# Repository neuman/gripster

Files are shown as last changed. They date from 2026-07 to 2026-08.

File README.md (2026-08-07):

# Gripster

**A wireless split thumb keyboard that turns your phone into a handheld deck.** Your phone clamps
landscape in the middle on a spring-loaded expanding bridge (Kishi/Backbone style, fits 130–170 mm
phones); two grips flank it and you thumb-type a real 78-key QWERTY on metal snap domes over Bluetooth.

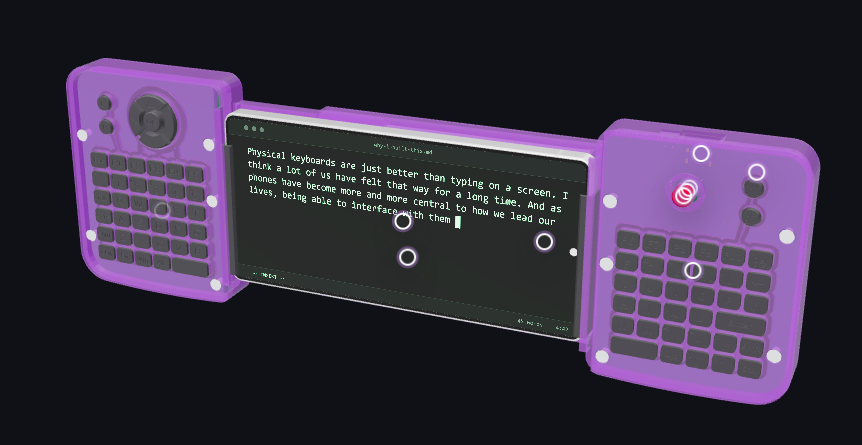
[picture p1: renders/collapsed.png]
Gripster — 3/4 view of the assembled deck: translucent Atomic-Purple shells, dark-gray keymats, a phone clamped landscape in the middle (https://neuman.github.io/gripster/)


<sub>☝️ **This image is a link — click it to spin the real assembly in 3D, pull it apart with the explode slider, and read the build story.**</sub>








> **Naming, once, so nothing is confusing later:** the project is called **Gripster** in prose. Every
> *internal* identifier — the ZMK board id `thumbdeck`, the board files `thumbdeck_right.kicad_pcb` /
> `thumbdeck_left.kicad_pcb`, the firmware artifact `thumbdeck-zmk.uf2`, the footprint library
> `thumbdeck.pretty/`, and the Bluetooth device name your phone will actually show — is
> **`thumbdeck`**. Those are real strings in real files and they stay as they are.

**What makes this interesting:**

- **It fits your phone, not one phone.** The grips ride a **2-part telescoping tray** (v0.24,
  Abxylute/8BitDo-style): stretch it open, drop the phone in, and two springs clamp it by the short
  edges — ~130 to ~170 mm long, and it collapses flat for a pocket. The phone is held **mechanically** —
  trapped between the tray and **soft TPU grippers with deep capture lips** — so it stays put even
  screen-down over your face like a Switch. **No magnets at all** — v0.25 dropped the secondary MagSafe
  ring: with the spring clamp, the toothed TPU grippers and the deep capture lips all doing their job it
  earned nothing, and its recess was the last thing wanting space in the moving jaw's travel.
- **The back is one flat plane.** v0.25 removed the v0.23 faceted crown and dropped both grips' backs
  to the tray floor, so the grips and the centre tray are coplanar — the device sits flat instead of
  rocking on its tray, and the back halves print straight on the bed with no supports. Every outside
  edge the hands wrap gets a 1.2 mm quarter-round.
- **No switches, no hand-soldering.** 78 Snaptron 7 mm metal snap domes press directly onto gold
  ENIG pads. Every soldered part is SMT on one side of each board — v0.21's pointing nub is a
  single SOT-23-6 hall sensor on the same reflow pass — so JLCPCB builds it 100 % turnkey,
  zero soldering by you.
- **It's not a split.** One certified nRF52840 module in the right grip scans a single 9×10 matrix;
  the left grip carries no active parts, joined by one **20-way** FFC ribbon that carries the matrix
  **and** the cell (v0.27 — the separate battery cable is deleted, so exactly one thing crosses the
  spine). One BLE device, no half-to-half pairing, one battery, one firmware image.
- **The whole product is generated from one Python file.**
  [`hardware/scripts/deck.py`](hardware/scripts/deck.py) emits the KiCad boards, the CadQuery
  shells, the renders *and* the ZMK keymap — so key openings land on dome pads by construction, not
  by luck.
- **The boards are real and finished.** Both PCBs are fully autorouted and DRC-clean in KiCad 9
  (0 violations, 0 unconnected), with the JLCPCB gerber + BOM + CPL package exporting cleanly.

> ### ⚠️ Honest status: designed, not built
>
> **No physical Gripster has ever existed.** Every image *of this device* is a render or a generated
> layout — the only photographs in the repo are of the Rii i8+ that was studied as a reference
> ([`references/`](references/)), alongside the original hand drawings in [`sketches/`](sketches/).
> rev-A (v0.27) is complete on paper: both boards routed and DRC-clean, the fab package
> exports cleanly, all 10 printed parts watertight and bed-fit-checked for an Ender 3 V2. (CI is
> stale — re-run it; the last green build predates the nub module.) Nothing has been ordered, printed, pressed, flashed or typed on.
>
> **Unmeasured and unknown:** ergonomics, dome feel and dome life, BLE range with a phone
> centimetres away and a hand around the antenna, real battery life, and every print tolerance.
> "0 DRC violations" means *no rule was broken*, not *the circuit is correct*.
>
> If you build one, **you are building the first one**. Read
> [Project status & roadmap](#project-status--roadmap) before you spend money.

---

## Table of contents

- [What is this?](#what-is-this)
- [Where to start](#where-to-start)
  - [What's in the repo](#whats-in-the-repo)
  - [Which doc answers which question](#which-doc-answers-which-question)
- [Project status & roadmap](#project-status--roadmap)
  - [Done](#done) · [Not done](#not-done--read-this-before-spending-money) · [Roadmap](#roadmap) · [Open design calls](#open-design-calls) · [Version history](#version-history)
- [FAQ](#faq)
- [Hardware](#hardware)
  - [At a glance](#at-a-glance)
  - [Why a module, not chip-down](#why-a-module-not-chip-down)
  - [Per-grip layout](#per-grip-layout)
  - [The boards, as routed](#the-boards-as-routed)
  - [The 3D model — printable shells + keymats](#the-3d-model--printable-shells--keymats)
  - [Parts list (BOM)](#parts-list-bom)
- [Firmware & software](#firmware--software)
  - [How it works — matrix, GPIO, power, antenna](#how-it-works--matrix-gpio-power-antenna)
  - [Building the firmware](#building-the-firmware)
- [Build guide](#build-guide)
- [Design & generation (the parametric model)](#design--generation-the-parametric-model)
  - [Fabrication view + real KiCad boards](#fabrication-view--real-kicad-boards)
  - [Reproduce the design](#reproduce-the-design)
- [Contributing](#contributing)
- [License](#license)

---

## What is this?

Phones are the most capable computer most people carry and the worst thing to type on. Gripster is a
handheld shell that fixes the input half without replacing the phone: your phone stays the screen
and the compute, and the deck around it becomes the keyboard.

The phone mounts **landscape in the centre**, clamped by two springs against toothed TPU grippers, and it
sits **down inside a well** — deep enough that the glass and the keyboard face form a single flat
plane 14.7 mm off the back. Two contoured grips flank it. You hold it like a game controller and
thumb-type a full split QWERTY: 78 keys on **metal snap domes**, the same clicky stainless discs used
in TV remotes and the [Rii i8+](references/rii8_ref.png), pressed straight onto gold pads on the PCB.
There is no switch, no stem, no solder — the dome *is* the switch. The whole thing takes its design
language from a Game Boy Color: boxy rounded outline, translucent Atomic-Purple shell, dark-gray
keymats. The original concept drawings are in [`sketches/`](sketches/).

Despite the two halves, **this is not a split keyboard**. One certified nRF52840 module lives in the
right grip and scans everything; the left grip holds no active silicon at all — domes, diodes, the
bridge connector, and (v0.27) the cell's plug and its fuse.

```
  LEFT grip (passive)                        RIGHT grip (MCU)
  42 domes + diodes  ── 20-way FFC jumper ──  Ebyte E73 (nRF52840)  ⇄ phone (BLE HID)
  D-pad/OK, mouse       straight type-A       + charger + USB-C + power switch
  LiPo + J4 + F1 PTC    14 matrix + VBAT      scans the whole 9×10 matrix
  (no chip)             + GND, one cable      charges over the same ribbon
```

That means one Bluetooth device to pair, no half-to-half link to drop, one battery to charge, and one
firmware image. The cost is a ribbon cable running through the spine under the phone well — since
**v0.27** that ribbon is 20-way and carries the raw cell alongside the matrix, so it is the *only*
thing crossing, and it is fused at the cell end (**F1**, a 0.75 A PPTC on the left board).

Everything you can see in this repo — the KiCad boards, the printable shells, the renders above, even
the ZMK keymap — is generated from a single parametric Python model,
[`hardware/scripts/deck.py`](hardware/scripts/deck.py). Move a key in the model and the board pad,
the shell opening, the keycap and the firmware matrix transform all move with it.

---

## Where to start

**Just browsing?** Open [the live site](https://neuman.github.io/gripster/) — spin the
model, drag the explode slider, tap the hotspots — then skim [At a glance](#at-a-glance) and the
[FAQ](#faq).

**Thinking about building one?** Read [Project status & roadmap](#project-status--roadmap) first — it
will either talk you out of it or tell you exactly what you are signing up for — then
[`docs/assembly.md`](docs/assembly.md) and
[`docs/fabrication-sourcing.md`](docs/fabrication-sourcing.md).

**Here for the engineering?** [Fabrication view + real KiCad boards](#fabrication-view--real-kicad-boards),
[`docs/routing-status.md`](docs/routing-status.md) and
[`docs/design-decisions.md`](docs/design-decisions.md).

### What's in the repo

| Directory | What's in it |
|---|---|
| [`hardware/scripts/`](hardware/scripts/) | **The source of truth.** [`deck.py`](hardware/scripts/deck.py) is the parametric model; the rest generate boards, fab output, firmware, simulations and 2D renders from it. Old 50-key experiments are archived in [`legacy/`](hardware/scripts/legacy/). |
| [`hardware/kicad/`](hardware/kicad/) | The generated KiCad 9 boards. Nothing here is hand-drawn — see its [README](hardware/kicad/README.md). The JLCPCB fab package builds into `generated/fab/` (a local build artifact, not committed). |
| [`hardware/cad/`](hardware/cad/) | CadQuery 3D: [`deck3d.py`](hardware/cad/deck3d.py) builds the shells and keymats, [`export_full_asm.py`](hardware/cad/export_full_asm.py) builds the nested GLB. Watertight STLs live in [`models/`](hardware/cad/models/). |
| [`hardware/footprints/`](hardware/footprints/) | Custom KiCad footprints, including the [snap-dome contact pad](hardware/footprints/snaptron_7mm_contact_pad.kicad_mod). Some are vendored third-party — see [License](#license). |
| [`hardware/layout/`](hardware/layout/) | [`keymat.json`](hardware/layout/keymat.json), the original sketch digitization. Historical only; the live layout is the `LEGENDS` tables in `deck.py`. |
| [`firmware/zmk-config/`](firmware/zmk-config/) | ZMK v0.3.0 config with a real board definition ([`config/boards/arm/thumbdeck/`](firmware/zmk-config/config/boards/arm/thumbdeck/)) — a unibody board, not a shield, not a split. |
| [`docs/`](docs/) | Eleven engineering documents, plus [`docs/diagrams/`](docs/diagrams/). Table below. |
| [`renders/`](renders/) | Every image in this README, all generated — CAD isometrics from `deck3d.py`, board renders from the `.kicad_pcb`s, and the two hero shots captured from the live viewer. [`history/`](renders/history/) keeps the superseded iteration log. |
| [`sketches/`](sketches/) · [`references/`](references/) | The original concept drawings, and Rii i8+ reference photos used during the design. |
| [`.github/workflows/`](.github/workflows/) | The self-contained ZMK build that produces `thumbdeck-zmk.uf2`. |

### Which doc answers which question

| I want to know… | Read |
|---|---|
| Why is it built this way? Every decision, with rejected alternatives | [`docs/design-decisions.md`](docs/design-decisions.md) |
| How do I actually assemble one, in order, without bricking it? | [`docs/assembly.md`](docs/assembly.md) |
| What do I buy, from whom, for how much? | [`docs/fabrication-sourcing.md`](docs/fabrication-sourcing.md) · [`docs/bill-of-materials.md`](docs/bill-of-materials.md) |
| How does the 9×10 matrix work, and why one diode per key? | [`docs/matrix-and-diodes.md`](docs/matrix-and-diodes.md) |
| Battery, charging, USB, ESD, the FFC bridge | [`docs/connectivity-and-power.md`](docs/connectivity-and-power.md) |
| How does a Python file turn into a routed PCB? | [`docs/routing-status.md`](docs/routing-status.md) |
| How does a Python file turn into printable shells? | [`docs/cad-process.md`](docs/cad-process.md) |
| What would an EE tear apart in a review? | [`docs/design-review.md`](docs/design-review.md) · [`docs/evaluation.md`](docs/evaluation.md) |
| What did we learn from cutting up a Rii i8+? | [`docs/reference-notes.md`](docs/reference-notes.md) |
| What does the architecture look like as a diagram? | [`docs/diagrams/`](docs/diagrams/) |

---

## Project status & roadmap

**rev-A (v0.27). Designed to the point of being orderable. Never built.**

### Done

| | |
|---|---|
| Both PCBs | Fully placed and **autorouted**, **0 DRC violations / 0 unconnected items** (KiCad 9, `kicad-cli 9.0.9`, error severity; both boards re-routed and re-verified for **v0.27**'s 20-way bridge, in the same commit that regenerated them — right board 75 nets / 114 footprints / 30 GND escape vias, left board 60 nets) |
| Fab package | 4-layer gerbers + JLC-format BOM + CPL export cleanly to `hardware/kicad/generated/fab/` via `gen_fab.py`; the exporter refuses to run unless DRC is clean. (That directory is a build artifact and is **not committed** — regenerate it, see [Reproduce the design](#reproduce-the-design).) |
| BOM | Every part real, LCSC-stocked and machine-placeable; no hand-soldered components |
| 3D | 221 bodies assembled and collision-checked at **every clamp position** (`deck3d.py --check` → 0 impossible overlaps at 130 / nominal / 170 / 179 mm open, cable enclosure sealed at each); all 6 shell parts (incl. the v0.21 nub spring + cap) + 2 TPU grippers + 2 keymats fit a 220 × 220 mm Ender 3 V2 bed (204 mm brim-safe limit) |
| Matrix proof | `sim_matrix.py` proves the full 78-key matrix is ghost-free with a diode per key |
| Firmware | Real ZMK v0.3.0 board definition; keymap and matrix transform generated from the model. CI last built green on 2026-07-15, **before the v0.21 nub module — re-run the workflow to validate the current design**. Never flashed; no hardware exists. |

### Not done — read this before spending money

| | |
|---|---|
| **Physically built** | **Never.** Zero boards ordered, zero shells printed, zero domes pressed, zero flashes. Every image of the device is a render. |
| Ergonomics | The grip shape, key pitch and thumb reach have never been tested by a human hand. v0.19 already reshaped the grips once on print-test feedback — expect more. |
| Dome feel & life | Snaptron force curve, keymat living-hinge fatigue and dome retention are *specified* but unmeasured. Fatigue-test a 3×3 keymat coupon before printing a full one. |
| Circuit correctness | Autorouted and DRC-clean is not the same as reviewed. No board has been powered, and no net has been probed. |
| RF | The antenna sits centimetres from a phone and inside a closing hand. Range loss is expected and unquantified. |
| Battery life | Never measured. The ~450–500 mAh cell and ZMK's sleep behaviour suggest weeks of light use; treat that as an estimate, not a spec. |
| Tolerances | Boss travel, screw-boss fit and lid gaps have only been checked in CAD, never against a real print. |
| **FFC route into the ZIF** | **Built in v0.27**, after turning out never to have existed. With the ZIF slot facing the spine there was only **1.20 mm of x** between the slot and a solid grip wall in which to lose **6.74 mm of z** — no route, in any version, for either cable, because both were drawn as straight boxes reaching neither connector. J2 now faces **inboard**: the ribbon folds in the grip's open back cavity and leaves through a low **stepped** duct (z −0.8 .. 2.6 on the grip side, .. 1.95 through the shroud so its roof keeps 1.42 mm) that passes *under* the phone-retention structure (all of which sits at z ≥ 3.9) rather than severing it. The descent clears the matrix diodes by **0.98 / 1.03 mm**, asserted against the real placement. `deck3d.py --check-lanes` sweeps the ribbon's full 21 mm section along the path and exits non-zero if any of it is buried. |

### Roadmap

1. **First article.** Order 5 sets, print the shells, build one, and write down everything that is
   wrong.
2. **Bring-up.** SWD-flash the bootloader, load the UF2, prove the matrix grip-by-grip, measure
   current draw and BLE range with a phone in the well and a hand on the grips.
3. **rev-B**, driven by whatever the first article teaches. Already parked for it: shoulder buttons,
   a canted/fanned key arc, and an I²C trackpad on the TP6–8 breakout.

### Open design calls

Decisions that are **yours to make** — they change the shape of the build:

1. **Feel.** Keys are **rectangular 8.5 × 7 mm at 10 × 9 mm pitch** (v0.17, i8+ chiclet — wider than
   tall so the 6-row field stays short). Still an open call: a flat ortho grid vs a **canted/fanned
   arc** to feel more like a controller — the arc is a keymat/standoff change, not a pitch change.
2. **Phone-fit window.** v0.24's expanding clamp fits phones with a **130–170 mm long edge** (cased)
   out of the box — the springs take up the rest. The jaw itself opens to **179 mm**: it has to
   clear the capture hooks to let the largest phone in, and v0.24e found that until then the travel
   was exactly the phone range, so a 170 mm phone couldn't physically be fitted. The nominal
   near-flush point is tuned to the
   **S25 Ultra + a 1.2 mm case**; `phone_span_min/max` (and `phone_t`/`case_t` for the recess depth)
   re-set the range and re-generate the shells (one command; boards unaffected).
3. **Cell size — settled in v0.18:** standard **403040 (~450–500 mAh)** in the left grip cavity (the
   only standard shape that fits the 5.1 mm free depth there); PROG's 196 mA ≈ 0.43 C suits it as-is.
   Sleep-managed runtime is still weeks.
4. **Shoulder buttons** for index fingers (offload thumb modifiers)? A rev-B matrix change.
5. **Trackpad** — dropped from v1 (single-maintainer ZMK driver + ATI tuning burden); the labelled
   I²C breakout (TP6–8) keeps a rev-B trackpad possible.

### Version history

<details>
<summary><strong>v0.16 → v0.20 changelog</strong> (click to expand)</summary>

- **v0.16 — the shell splits.** The one-piece shells (which needed a 350-class printer) become
  **five printed parts**: two back halves joined at mid-spine with printed tabs + wall shiplaps (no
  seam screws), two grip lids, and a screwed-on center panel that bridges the seam. Everything now
  prints flat on a 220 × 220 mm Ender 3 V2 bed.
- **v0.16-follow (2026-07-15).** A **Rii-style 2u Enter** ends the right grip's H-row — `H J K L +
  ENT`. The `'` key gave up its spot (`'` is now **FN+`;`**), bringing the total to **78 keys**. The
  right board was regenerated and rerouted (still 0/0), the fab package re-exported, **debossed
  keycap legends** added to the keymat model, and the shell screws modelled in the 3D assembly.
- **v0.17 — Rii proportions.** The grips take the Rii i8+'s proportions: **97 mm** tall, a chin cut,
  the E73 + entire power front-end moved up into the **top zone** (the old trackpad space) with the
  ceramic antenna pointing **up off the top board edge**, and **rectangular 8.5 × 7 mm keys** at
  10 × 9 mm pitch replacing the round ones. Boards became 79.5 × 97.0 mm.
- **v0.18 — the phone sinks.** A real **S25 Ultra in a thin case** drops into a **well in the center
  panel** so its **screen surface is flush with the lids' keyboard face** — one 14.7 mm-high front
  plane, and the device drops from 22.9 mm to **15.7 mm** thick overall. That left no cell height in
  the spine, so the **battery moved to the left grip's cavity**: a standard **403040 (~450–500 mAh)**
  under the passive PCB. No board change, no reroute. The FFC minimum length rose accordingly.
- **v0.19 — Game Boy Color rework.** From print-testing feedback: the grip outline goes
  **GBC-boxy** — the parabolic outer cheek bow is deleted (it blocked thumb reach to the
  edge-adjacent keys) and boards narrow **79.5 → 75.0 mm**; corners tuck to r8 (top, antenna-pinned)
  and r11 + a 1.0 mm **crown** (bottom). All 14 face screws become **M3×10 countersunk, flush with
  the face**. The phone well gets **closing end walls** (no more open slots into the grips) and the
  thumb scallop becomes a **watertight curved finger dish**. Shells render and export in
  **translucent Atomic Purple** with dark-gray keymats. Both boards re-routed from scratch against
  the new outline, still 0 violations / 0 unconnected.
- **v0.20 — mirrored modifiers.** A thumb can't cross the phone gap, so Ctrl/Shift/Alt now exist on
  **both** grips: two right-grip caps relabel (`AltGr`→`Alt`, the corner `\`→`Ctrl`) and both grips
  end in the identical stack — Ctrl at the bottom-outside corner, Shift above it, Alt beside Space.
  `\` and `|` move to **FN+`]` / FN+`[`** (direct bindings). Right grip emits RCTRL/RSHFT/RALT.
  **No sticky keys — all chords are plain holds.** Zero PCB change: the matrix transform regenerated
  byte-identical; keymats re-debossed; `sim_matrix` re-run — 78 keys, 0 collisions, PASS.

</details>

---

## FAQ

**Will it fit my phone?**
Out of the box, no — the well is dimensioned for a **Samsung S25 Ultra (77.6 × 162.8 × 8.2 mm bare)
in a ~1.2 mm thin case**, and the fit is tight by design because the screen has to sit flush. But the
phone is four numbers in the model (`phone_w`, `phone_h`, `phone_t`, `case_t` in
[`hardware/scripts/deck.py`](hardware/scripts/deck.py)); change them, re-run the 3D generator, and
you get shells for your phone. **The PCBs are unaffected** — only the printed parts change. Two
caveats: the grip separation is
derived straight from the cased phone envelope — a substantially **larger** phone pushes the grips
further apart than is comfortable to thumb-type across (a smaller one brings them closer, which is
fine ergonomically, you just get less screen). A large change also moves the FFC bridge connectors
apart, so re-check the ribbon length in [`docs/assembly.md`](docs/assembly.md) before ordering.

**Can I build one today?**
You can order everything today — the boards are routed, DRC-clean and the JLCPCB package exports with
one command. But you would be building the **first one that has ever existed**, and rev-A has never
been electrically or ergonomically validated. If that is appealing,
[`docs/assembly.md`](docs/assembly.md) is written to be followed literally, and the one thing to
check first is E73 module stock (JLC **C356849**) — it has been observed swinging from ~1000 units to
~20 in days.

**Is it a split keyboard?**
It looks like one and isn't. There is a **single 9×10 matrix** scanned by one MCU: the right grip
owns COL0–4 locally, the left grip's COL5–9 arrive over a **20-way** FFC ribbon (14 of its conductors
are the matrix and have not changed since rev-A; v0.27 put the battery on the spare ones), and all nine rows are
shared. In ZMK terms it's a **unibody board**, not `CONFIG_ZMK_SPLIT`. One device pairs to your
phone, one battery, one firmware. A useful debugging consequence: a dead **column** on the left
points at the ribbon; a dead **row** kills the same row on *both* grips.

**Why a module instead of a bare nRF52840?**
Because chip-down means owning a 2.4 GHz impedance match and VNA tuning, **FCC/IC/RED radiated
certification**, crystals, a USB bootloader and a from-scratch Zephyr board port. The Ebyte
E73-2G4M08S1C retires all of that, is stocked in JLCPCB's library so it machine-places, and still
breaks out far more GPIO than the 19 matrix pins + 1 battery ADC this design uses. Full reasoning in
[`docs/design-decisions.md`](docs/design-decisions.md) and
[below](#why-a-module-not-chip-down).

**Why no trackpad?**
It was designed in and then deliberately **cut from v1**: a maintained ZMK driver plus ATI/sensitivity
tuning is a large burden for a single maintainer, and it competed for the exact board area the module
and power front-end now occupy. Pointing since v0.21 is the right-grip **hall-effect nub**
(rate-control, ThinkPad-style) — which now lives on the very I²C breakout (**TP6–8**) that was
reserved for a rev-B trackpad — plus the left D-pad with FN-layer mouse keys as fallback. And the
user verdict behind the nub choice: trackpad-style thumb pointing means constantly lifting the
finger; a velocity-controlled nub doesn't.

**What's the battery life?**
Unknown — nothing has been measured. The design carries a standard **403040 LiPo (~450–500 mAh)** in
the left grip, charged at ~196 mA by an MCP73831, with battery percentage reported over BLE. A BLE HID
keyboard with a sleeping nRF52840 should give weeks of light use; that is an expectation based on
comparable ZMK builds, not a number from this device.

**Why ZMK and not QMK?**
ZMK is built around BLE and low-power sleep on nRF52 parts, which is exactly this device's whole job,
and it gives layers, combos and mouse keys for free. The repo pins **ZMK v0.3.0** (the last
HWMv1-compatible release, Zephyr 3.5) and ships a **real board definition** at
[`firmware/zmk-config/config/boards/arm/thumbdeck/`](firmware/zmk-config/config/boards/arm/thumbdeck/)
rather than a shield — the keymap and matrix transform are generated from the same model as the PCB,
so they cannot drift apart.

**What printer do I need?**
Anything with a **220 × 220 mm bed** — the 5-part shell split exists specifically so everything fits
an Ender 3 V2, and `deck3d.py --all` gates every part against a 204 mm brim-safe limit. Largest part
is a back half at 170.5 × 103.8 mm. Shells print in **PETG**; the keymats need **TPU 95A** (or a
tough resin) for the living hinges.

**Do I have to solder?**
No. Every soldered component is on one side of each board and is placed by JLCPCB, 100 % turnkey.
Your hands do four things: press the 78 domes onto their pads under retention tape, seat the FFC
ribbon, print and screw together the shell, and tape in the battery. The one unavoidable exception is
a **one-time SWD flash** of the Adafruit nRF52 bootloader via test pads TP1–5 (possibly preceded by
`nrfjprog --recover`) — that needs a debug probe, and it is the single most likely place a builder
gets stuck. After that it's drag-and-drop UF2 forever.

**What will it cost?**
The **~$150–250 for 5 sets** figure quoted below is **boards + JLCPCB assembly only**. It excludes
domes, retention tape, the LiPo, FFC jumpers, M3 hardware, filament, a debug probe,
shipping and any import duty. Re-quote at order time.

**Can I buy one?**
No. This is an open-source design, not a product — there is no kit, no store and no waiting list.
It's Apache 2.0, so you are free to build it, modify it or sell it yourself.

---

## Hardware

### At a glance

| | value |
|---|---|
| Form | phone (**130–170 mm long edge**) held **LANDSCAPE** in a **2-part telescoping tray** (v0.24, Abxylute/8BitDo-style — spring clamp, TPU edge grippers + deep capture lips; v0.25 no magnets); two dome-key grips, **printed shell** in **Game-Boy-Color design language** (translucent Atomic-Purple shells, dark-gray keymats; v0.25 flat one-plane back with rounded outer edges; every part fits an Ender 3 V2 bed) |
| Keys | **78 Snaptron 7 mm snap domes** (right 36, left 42) · **rectangular 8.5 × 7 mm keys** (i8+ chiclet feel) at **10 × 9 mm** pitch (~1.5–2 mm walls → PETG-printable) · one-piece living-hinge keymat with a **2u space bar**/side + a Rii-style **2u Enter** ending the right H-row · debossed keycap legends |
| Left grip | QWERT-half (6×6) + a **Ø24 integrated D-pad** (v0.25, Rii i8+ style: four arm sectors + a Ø9 centre OK behind one round lid aperture, over the same five domes) + **mouse L/R** buttons — **no active parts**: diodes + the FFC ZIF, plus (v0.27) the cell's JST-PH **J4** and its **F1** PPTC fuse in the chin |
| Right grip | YUIOP-half (6×6 field; the H-row ends in a Rii-style **2u ENT** — `H J K L + ENT`, with `'` on FN+`;`) + the v0.21 **pointing cluster mirroring the left D-pad cluster** (hall-effect nub at the D-pad mirror, PgUp/PgDn as the mouse-button pair's mirror), plus the module and the whole power front-end |
| Modifiers | **mirrored** (v0.20): Ctrl at each grip's bottom-outside corner, Shift directly above it, Alt beside each Space — a thumb can't cross the phone gap, so every mod+same-side-key chord holds the mod with the opposite thumb (right emits RCTRL/RSHFT/RALT). `\` and `\|` moved to FN+`]` / FN+`[`; **no sticky keys — all chords are plain holds** |
| Controller | **one Ebyte E73-2G4M08S1C** (nRF52840 module, JLC C356849) — certified radio, on-module antenna/crystals, UF2-flashable after a one-time SWD bootloader flash |
| Matrix | single **9 × 10**, `col2row`, one **SOD-323** diode/key on the back, 9× 4.7 kΩ row pull-downs, NKRO best-effort |
| Bridge | **20-pin 1.0 mm FFC ZIF** (v0.27: JUSHUO **AFA07-S20FCC-00**, JLC **C262352**, Extended — same tier as the 16-way it replaces) on each grip's inner edge + a **20-way 1.0 mm type-A (same-side contacts) FFC jumper, length ≥240 mm** (v0.24: the clamp span is variable, so the ribbon carries a rolling service loop). It went 16 → 20 way so **one** cable carries the matrix *and* the battery: 14 matrix conductors (ROW0–8, COL5–9 — **identical to rev-A, so firmware is untouched**), 2× GND, 2× VBAT_CELL and 2 NC guards. Nets are assigned by ribbon geometry, so a straight jumper is correct by construction. **⚠ Do not fit a 16-way ribbon** — a 17.0 mm ribbon floats in the 21.0 mm housing with 4.0 mm of slop at *each* end |
| Grip boards | **75.0 × 97.0 mm** each (v0.19: GBC-boxy straight outer edge — the parabolic cheek bow is gone for thumb reach), **4-layer** (sig / GND plane / sig / sig), 1.6 mm FR-4, **ENIG** (mandatory — dome contacts) |
| Power | **LiPo 403040 (4.0 × 30 × 40, ~450–500 mAh) with an integrated PCM — a hard requirement, not a preference** — in the LEFT grip cavity under its PCB (v0.18 — the sunken phone well leaves no cell height in the spine). **v0.27:** it plugs into **J4** (JST-PH) ~8 mm away *in the same grip*, through **F1** (0.75 A hold / 1.5 A trip PPTC) in series with cell +, and reaches the right grip over the bridge ribbon — the separate 2-wire power cable is deleted. **MCP73831** charger + **USB-C** + inline **USBLC6-2** ESD + **MSK12C02 power switch** + **reset tact** (pinhole) + **charge LED** stay in the right grip; the charger is still on the cell side of the switch, so it charges while switched off |
| Pointer | v0.21/22: **ThinkPad-style hall-effect nub** on the right grip, Ploopy-Bean architecture — a TMAG5273 I²C hall sensor (SOT-23-6, machine-placed) reads a magnet in a printed flexure spring **through the PCB**; true **rate-control** firmware (deflection → cursor velocity, quadratic curve) in an in-tree Zephyr module on the repurposed TP6–8 I²C breakout. The mount is a **standard 4.4 mm-square TrackPoint platform**: wear the printed **red soft-dome replica** or any **genuine classic TrackPoint cap**. FN+D-pad mouse keys remain as fallback |
| Wireless | BLE HID; USB-C for charging + UF2 flashing |
| Fabrication | **JLCPCB** turnkey, **two separate orders** (right + left), single-sided reflow (**all SMT on the back**, single-pass — v0.21 adds no THT) → rough target **~$150–250 for 5 sets**, boards + assembly only (re-quote at order time) |
| Firmware | **ZMK v0.3.0**, real board definition `thumbdeck` (unibody, not a split); the CI workflow is a **self-contained** ZMK v0.3.0 build producing `thumbdeck-zmk.uf2` |

### Why a module, not chip-down

> A bare nRF52840 would force you to own a 2.4 GHz match + VNA tuning, **FCC/IC/RED radiated
> certification**, a USB bootloader, crystals, and a from-scratch Zephyr board port. A pre-certified
> module retires all of that and still breaks out far more GPIO than the 19 matrix pins + battery
> sense this design needs. We use the **Ebyte E73** because it's stocked in the JLCPCB library and
> machine-places — see [`docs/fabrication-sourcing.md`](docs/fabrication-sourcing.md). Full decision
> record in [`docs/design-decisions.md`](docs/design-decisions.md).

Everything below is generated from one parametric model
([`hardware/scripts/deck.py`](hardware/scripts/deck.py)) — regenerate with the
[pipeline](#reproduce-the-design).

### Per-grip layout

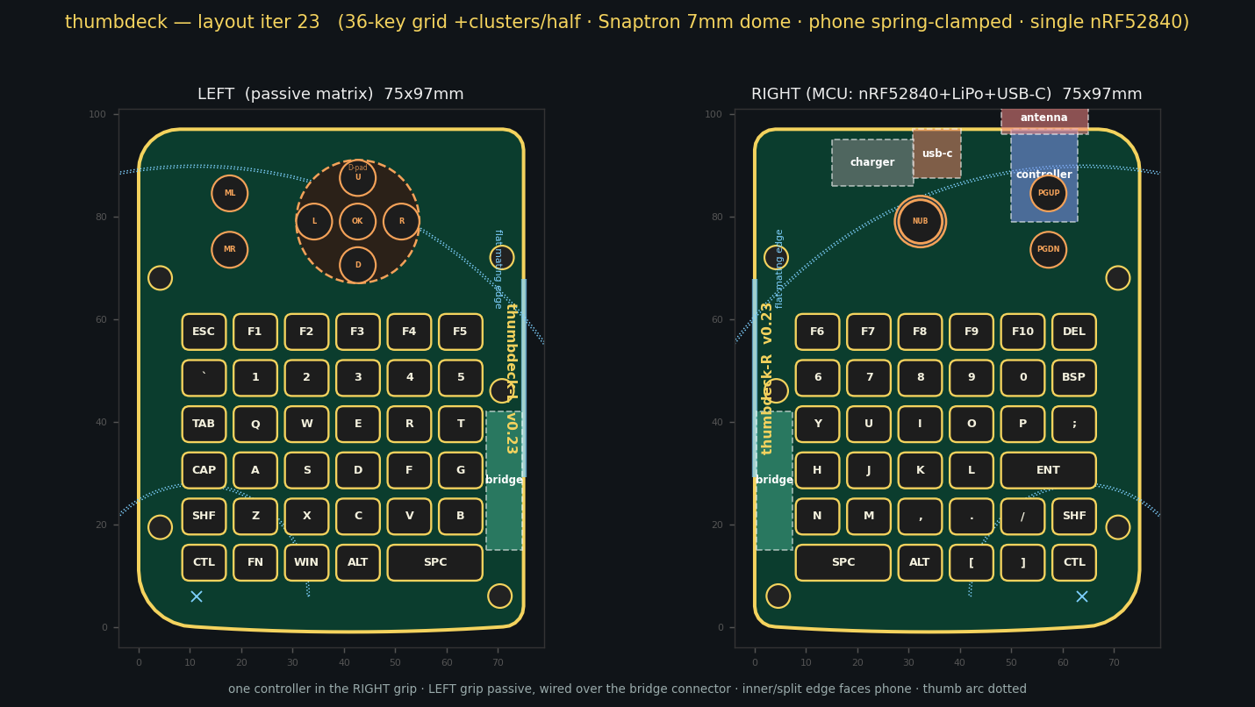
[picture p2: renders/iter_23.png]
Layout, both grips


6-col grid of rectangular 8.5 × 7 mm keys at 10 × 9 mm pitch per grip (bottom row = a 2u space bar;
the right H-row ends in a Rii-style 2u Enter — `H J K L + ENT`, `'` on FN+`;`), plus the cluster
features. The E73 + power front-end sit in the top zone with the antenna up off the top edge;
PgUp/PgDn sit beside the pointing nub as the mouse-button pair's mirror (v0.21).

### The boards, as routed

Rendered straight from the committed `.kicad_pcb` files — this is the copper that would be
fabricated, not a concept drawing.

<details>
<summary><strong>Show both boards, front and back</strong> (click to expand)</summary>

**Front — right grip.** Nothing but snap-dome contact pads (centre pad + leg ring with the routing
escape gap) and front-layer traces. The front carries **zero soldered parts**; the domes are pressed
on later, under retention tape.

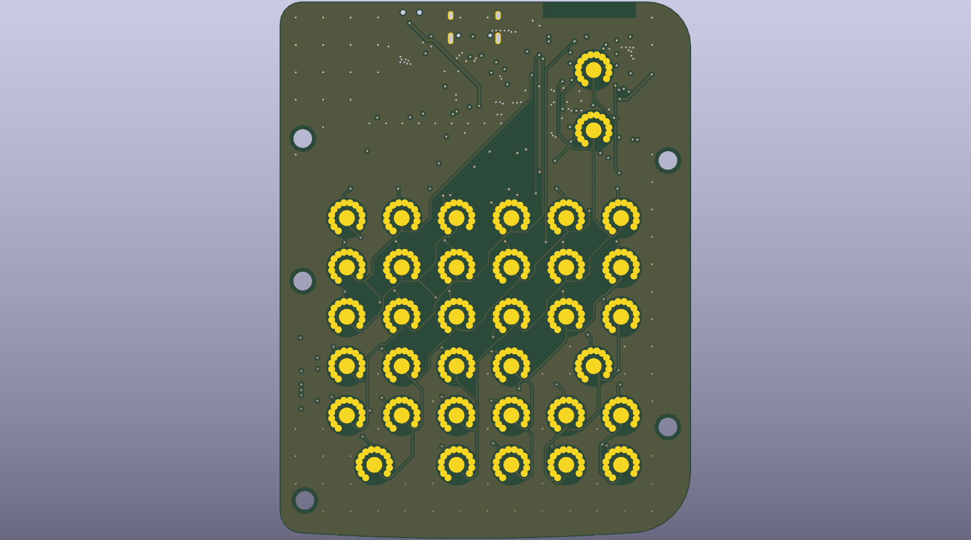
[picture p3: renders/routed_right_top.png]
Right board, front


**Back — right grip.** Everything soldered lives here: a diode behind every dome, the Ebyte module
(**antenna-up at the top edge**, v0.17), charger, USB-C, ESD, power switch, reset tact, charge LED,
the FFC connector and all passives — the whole cluster in the top zone, which is what let the chin
be trimmed.

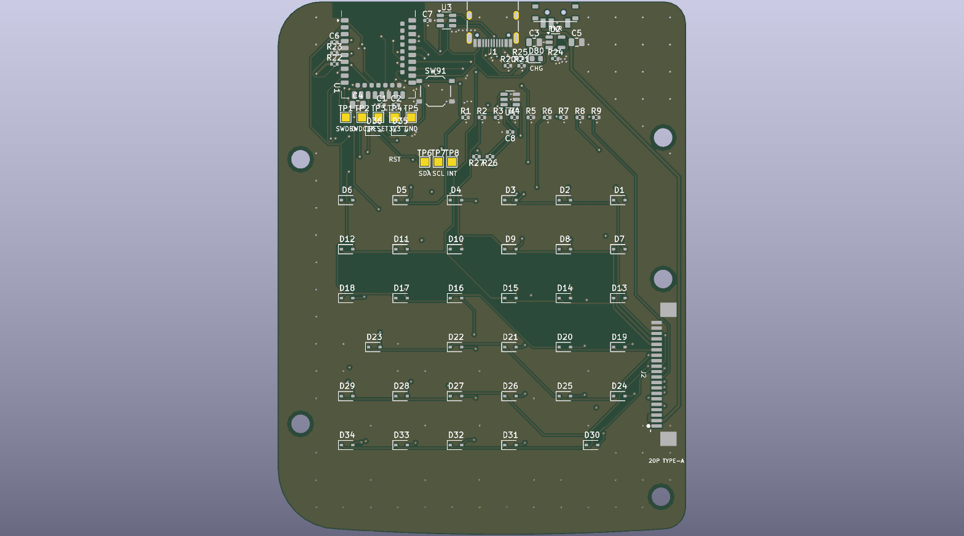
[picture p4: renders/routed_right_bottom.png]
Right board, back


**Left grip, front and back.** No active silicon at all — 42 domes, 42 diodes, the FFC ZIF, and
(v0.27) the cell's JST-PH **J4** and its **F1** PPTC fuse in the chin.

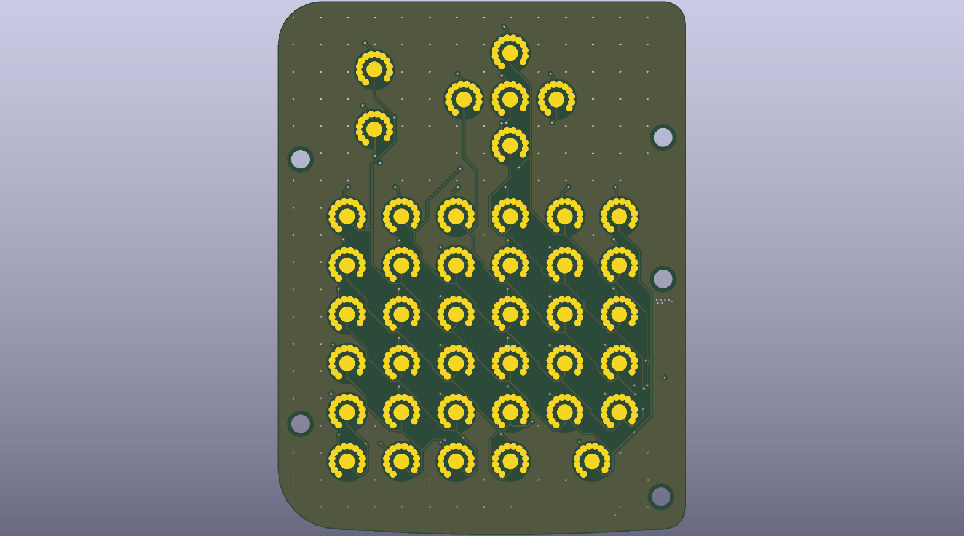
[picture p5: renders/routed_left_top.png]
Left board, front


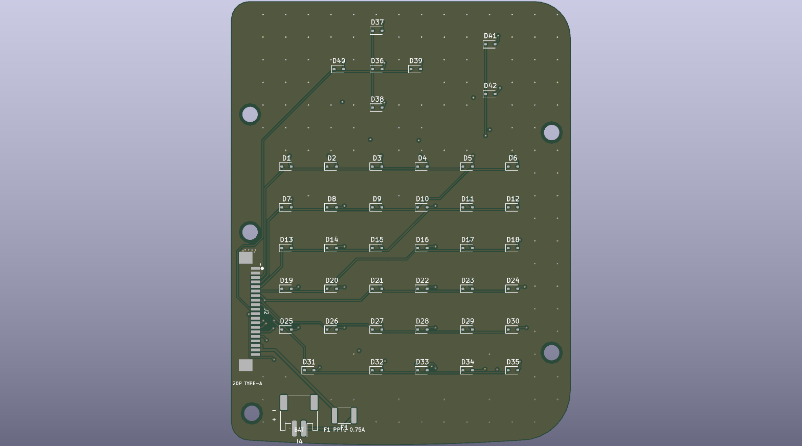
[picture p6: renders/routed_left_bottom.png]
Left board, back


</details>

Inside the centre tray, v0.24d gives the contents a **lane plan** — as of **v0.27** it reads
`spring | FFC | spring` front to back (the power lane went with the cable it carried), every lane on
one z with printed divider ribs between them, so nothing is stacked over anything and the ribbon
sits inside the *moving* shroud's cavity — enclosed at every extension, not just while the fixed
tray happens to still be underneath. The FFC lane widened with the connector — 17.0 → **21.0 mm** on
y **28.5** — and y 40.0…82.5 inside the cavity is now free.

### The 3D model — printable shells + keymats

Fit-checked in CAD against real-dimension component models — datasheet heights, not a physical
build. The mechanical parts are generated from the **same** parametric
model as the PCB ([`hardware/scripts/deck.py`](hardware/scripts/deck.py)) via CadQuery, so key
openings land on dome pads and bosses land on mount holes *by construction*. The whole stack — back
halves (the right one is the grip **and** the fixed tray in a single part since v0.25), PCB with
**real-dimension** components (E73 module, USB-C, connectors, SOT-23s, 0402s, snap-domes), LiPo, FFC
jumper, keymats, grip lids, **TPU grippers**, phone — is assembled in one frame and
**collision-checked at every clamp position**: `deck3d.py --check` reports **0 impossible overlaps**
at 130 mm, nominal, 170 mm and 179 mm fully open, with the cable enclosure sealed at each.
Full method: [`docs/cad-process.md`](docs/cad-process.md).

**Exploded** — back halves (right = grip + tray, one part) · PCB + domes · keymats · grip lids · TPU grippers · phone:

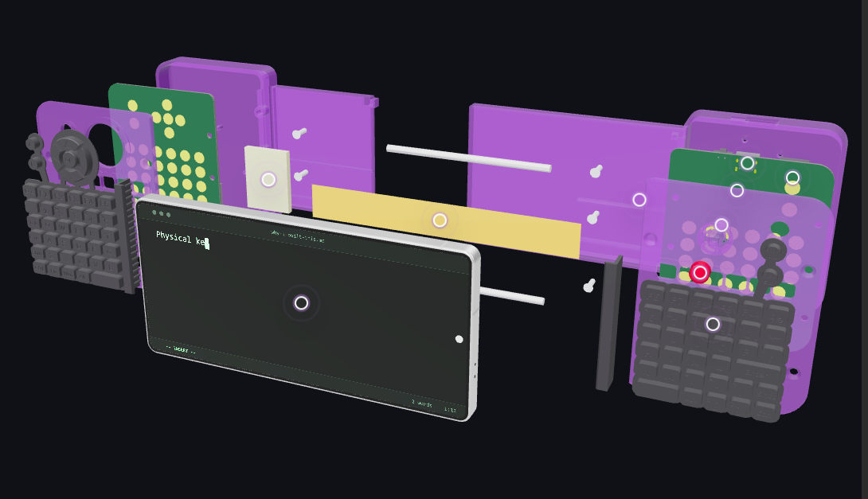
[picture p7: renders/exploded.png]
Exploded assembly


The shell prints flat on a **220 × 220 mm Ender 3 V2 bed** — the old one-piece shells needed a
350-class printer. Since **v0.24** the rigid center panel is gone: the two back halves are the
**grips themselves** — `back_right` is the fixed ground, `back_left` is the moving clamp jaw — and
since **v0.25** the telescoping tray is printed as *part of* `back_right` rather than bolted on, with
the left grip's inner shroud lapping inside it to enclose the springs and the single FFC. The tray
top is an uninterrupted flat phone rest; **TPU grippers** on each inner edge do the mechanical hold.
Opening the left grip's five screws services the battery. v0.17
keymats carry the **rectangular keycaps** (8.5 × 7 rounded-rect plungers, 18.5 mm 2u caps for the
space bars and the right H-row's Rii-style Enter, round cluster keys) on the same living-hinge web
(TPU 95A), now with **debossed Rii-style legends** (primary, shifted-symbol and FN-layer); the grip
lids get matching rounded-rect openings. v0.25 replaces the left grip's five separate nav buttons
with **one Ø24 integrated D-pad** — four arm sectors and a Ø9 centre OK, split by 2.0 mm relief
moats, through a single dished Ø24.4 lid aperture. The five domes underneath do not move, so no
board or firmware changes; the presses stay discrete because the web is **thinned to 0.4 mm under
each moat** and pinned all the way round the pad by a **clamp ring** on the lid backed by a **rib**
on the mat.
Part sizes: back halves 170.5/162.8 × 103.8 mm, grip lids 77.9 × 103.8, keymats ~63 × 86–89 — all
within the 204 mm brim-safe limit.

Back half (grip + tray) | Grip lid | TPU gripper | Keymat
:---:|:---:|:---:|:---:
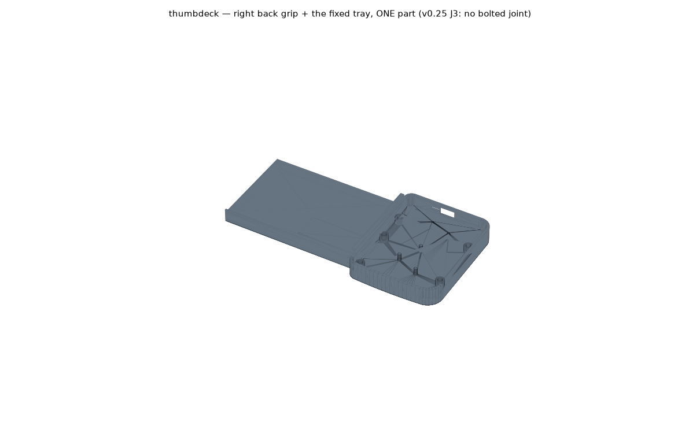
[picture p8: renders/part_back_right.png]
back
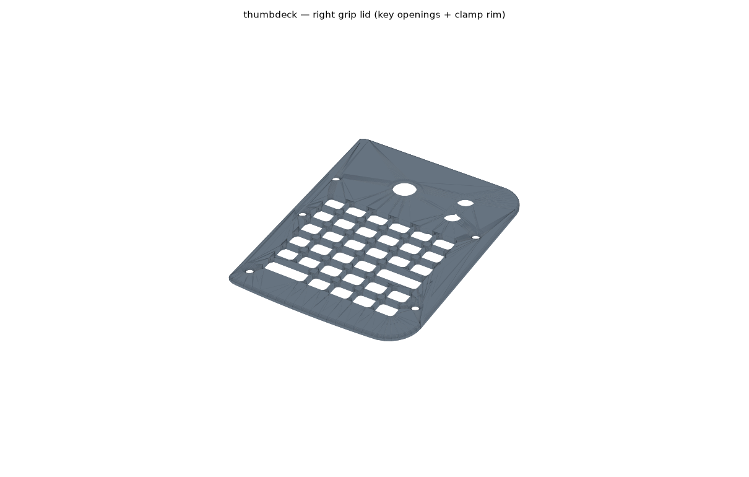
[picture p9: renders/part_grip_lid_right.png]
lid
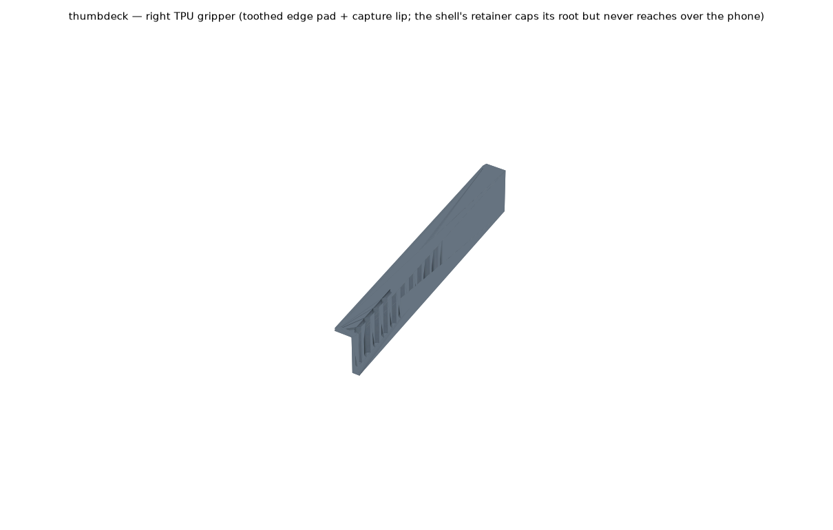
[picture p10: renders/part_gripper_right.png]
gripper
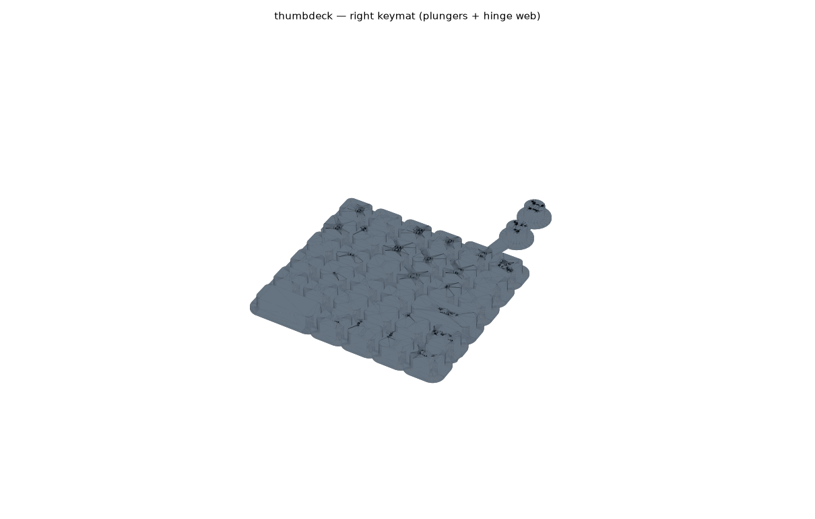
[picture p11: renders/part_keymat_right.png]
keymat
 |  |  | 

Regenerate: `hardware/cad/.venv/bin/python hardware/cad/deck3d.py --all --check --render`
(`--all` also gates every part on the Ender 3 V2 bed-fit; `--sync-models` refreshes the tracked STLs
in [`hardware/cad/models/`](hardware/cad/models/)).

**Full nested assembly** —
[`hardware/cad/models/thumbdeck_full_asm.glb`](hardware/cad/models/thumbdeck_full_asm.glb) is the
whole build as one glTF file with a **named object tree** (open it in Blender or any glTF viewer, or
spin it in the browser on [the live site](https://neuman.github.io/gripster/), which
loads a web-optimized build of this same file): translucent **Atomic-Purple** shells + dark-gray keymats (real glTF PBR
materials), **KiCad-generated boards** (real Edge.Cuts body + routed copper + soldermask + silkscreen
from the `.kicad_pcb`s), every placed component and snap dome as its real-dimension body, plus the
403040 battery, FFC jumper (drawn as a straight box in its tray lane — its descent into the ZIFs is
the open item in [Not done](#not-done--read-this-before-spending-money)), the M3 shell screws and the
flush-mounted cased phone. All transforms are baked into the vertices, so the tree survives even
minimal TRS-only viewers. Regenerate:
`hardware/cad/.venv/bin/python hardware/cad/export_full_asm.py`.

### Parts list (BOM)

Full BOM in [`docs/bill-of-materials.md`](docs/bill-of-materials.md) — regenerated from the
machine-exported `fab/*/bom.csv`. **78 keys**, **one** module, **one** battery. Everything soldered is
placed by JLC; your hands do domes, shell, battery and the FFC jumper.

#### Core

| Item | Part | Qty | Notes |
|---|---|---|---|
| Snap dome | **Snaptron 7 mm 4-leg dome** (SnapForce series) | 78 (+spares) | Pressed onto ENIG contact pads under retention tape — no solder. Footprint: [`snaptron_7mm_contact`](hardware/footprints/snaptron_7mm_contact_pad.kicad_mod) (centre pad + leg ring with routing escape gap). |
| Dome retention | Snaptron taped polyimide array (Peel-N-Place) **or** 0.2–0.3 mm laser-cut polyimide spacer | 2 | **Required** — the keymat alone won't stop a dome walking off its contact ring. The tape channels also vent the domes. |
| Keymat | one-piece 3D print, **TPU 95A** / tough resin | 2 | Living-hinge strips; fatigue-test a coupon >10 k cycles before the full mat. |
| Diode | **1N4148WS SOD-323** (JLC **C2128**, Basic) | 78 | One/key, `col2row`, cathode band → row net, **on the back**. Basic part = free feeder. |
| **Controller** | **Ebyte E73-2G4M08S1C** (nRF52840, JLC **C356849**) | **1** | Certified radio, on-module antenna/crystals. On the **back** of the right grip, **antenna-up at the top board edge** (v0.17 — farthest from the centred phone/LiPo, off the edge the palm doesn't cradle). Extended + X-ray + **volatile stock** (seen swinging ~1000 → ~20 units in days) — reserve/backorder before anything else. |
| **LiPo** | **403040 pouch (4.0 × 30 × 40 mm, ~450–500 mAh)** with an **integrated PCM — REQUIRED**, JST-PH pigtail | 1 | The protection module is a hard requirement, not advice: overcurrent 2.0–2.5 A / 8–16 ms, overcharge 4.275 V, overdischarge 2.75 V. It and **F1** cover *different* bands and neither alone is sufficient. v0.18: foam-taped (0.3 mm) to the **LEFT grip's floor under its PCB** — the sunken phone well displaced it from the spine. **v0.27:** the pigtail plugs into **J4** ~8 mm away in the *same* grip instead of running a ~265 mm bare lead across the whole device. **Meter pigtail polarity against the "+"/"−" silk at J4 — on the LEFT board — before first plug-in** (pin 1 = "+"); vendors wire PH pigtails both ways. |
| **Bridge** | **AFA07-S20FCC-00** **20**-pin 1.0 mm FFC ZIF (JLC **C262352**) ×2 + **20-way 1.0 mm FFC jumper, TYPE-A ONLY (contacts on the SAME side at both ends), length ≥240 mm** | 1 set | Bottom-contact, 2.5 mm tall, slide lock, side entry, 0.3 mm FFC. Type-A is load-bearing — the left grip's nets are assigned by ribbon geometry, so a straight jumper matches 1:1. **v0.27: buy 20-way. A 16-way ribbon is dangerous here** — 17.0 mm floats in the 21.0 mm housing with 4.0 mm of slop at *each* end, i.e. up to a 4-position shift. The conductor order (GND, GND, ROW0–8, COL5–9, NC, VBAT_CELL, VBAT_CELL, NC, index 0 = highest deck y) is chosen so even a 4-position shift lands VBAT on a **column** — one dead MCU pin — rather than on GND, which is a dead short across the cell. **v0.24:** the clamp span is variable, so the ribbon carries a rolling service loop that pays out as the jaw slides; it must reach at max extension (~195 mm J2-to-J2) plus the fold, so coupon-tune the loop radius. |
| **Fuse (F1)** | **Bourns MF-MSMF075-2** PPTC, 1812 (JLC **C84140**) | 1 | **v0.27, safety-critical.** 0.75 A hold / 1.5 A trip, 13.2 V, Imax 100 A, R<sub>init</sub> ≤ 0.45 Ω. On the **LEFT** board at deck (50.0, 5.5), in series with cell **+** between **J4** and **J2** — it must be on the **cell** side of the ribbon or it protects nothing. Why it exists: the ribbon now carries the raw cell, and a 1.0 mm-pitch FFC conductor (0.70 × 0.035 mm = 0.0245 mm²) hits its 105 °C insulation limit around 2.8 A·√s and melts its own PET in ~0.2 s at a real short, while the cell's PCM does not trip until 2.0–2.5 A. The **0.43–2.0 A band in between** — the signature of a partially abraded conductor in a mechanism that flexes on every phone insertion — is covered by nothing else. Cost is **charge time**, not capacity: the 0.45 Ω moves CC→CV handover to a lower cell voltage so the taper is longer; undercharge at termination is I<sub>TERM</sub> × R<sub>loop</sub> ≈ 10–16 mV, negligible against the MCP73831's own ±32 mV VREG tolerance. |

#### Power / USB front-end (right grip unless noted — required even with a module)

| Item | Part | Qty | Notes |
|---|---|---|---|
| Charger IC | **MCP73831T-2ACI/OT** (JLC **C424093**) | 1 | Module has no charger. PROG = 5.1 kΩ → ~196 mA (~0.43 C of the 403040 cell). Don't sub -2ATI (different Vreg). 4.7 µF 0805 at **both** VDD and VBAT per datasheet. |
| USB-C receptacle | **fully-SMD 16P** (JLC **C165948**) + **2× 5.1 kΩ** CC1/CC2 | 1 | Must be SMD — a THT shell breaks 100 % reflow. Missing CC = never charges. |
| ESD array | **USBLC6-2SC6** (JLC **C7519**) **inline** between USB-C and module | 1 | |
| Power switch | **MSK12C02** slide (C431540) between cell+ and VBAT | 1 | Charger stays on the cell side — it charges while switched off. Knob through a slot in the **top** shell wall (v0.17 moved the electronics cluster to the top zone). v0.27: cell + arrives here as **VBAT_CELL over the bridge ribbon**; the switch gates only the load, so the ribbon is live whenever the cell is plugged into J4. |
| Reset button | **TS-1187A** tact (C318884), top-actuated | 1 | Pressed through a 1.6 mm pinhole in the shell floor — UF2 double-tap without opening the shell. |
| Charge LED | 0603 red (C2286) + 1 kΩ | 1 | On MCP73831 STAT; visible through a 1.5 mm floor hole. |
| Battery connector | **JST-PH 2.0 mm side-entry SMT** (S2B-PH-SM4-TB, C295747) — **J4, on the LEFT board** | 1 | Polarized; the hobby-LiPo standard. **v0.27:** it moved grips. Deck (60.0, 5.5) in the left grip's chin, mouth facing +y, so the 403040 plugs in ~8 mm from where it lives; the old right-board **J3 is deleted**. It is also the only way to de-energize the ribbon for service, since the power switch gates the load, not the cell. Pin 1 = "+". |
| Battery sense | 2× 1 MΩ divider (÷2) + 100 nF SAADC filter | 1 | On P0.02/AIN0. |
| SWD pads | **TP1–5** (SWDIO / SWDCLK / RESET / 3V3 / GND), silk-labelled | — | One-time bootloader flash / recovery. TP6–8 = the nub sensor's live I²C (SDA/SCL/INT), still probe-able. |

#### Matrix hardening (on the board)

| Item | Part | Qty | Notes |
|---|---|---|---|
| Row pull-downs | 4.7 kΩ 0402 (R1–R9) | 9 | External at the MCU — the nRF's internal pull is too weak over the ribbon. |

Column series resistors and a dome-field TVS were considered and **dropped** — the bridge is a short
fixed internal ribbon, not a long flexing cable. Note them as a rev-B option if field ESD issues
appear.

#### PCB / hardware

| Item | Spec | Qty | Notes |
|---|---|---|---|
| PCB | `thumbdeck_right` + `thumbdeck_left`, **4-layer**, 1.6 mm FR-4, **ENIG** | 5 each | Two distinct boards, **two separate JLC orders**. Fab package exported by `gen_fab.py` into `hardware/kicad/generated/fab/`. |
| Shell | **v0.25: 6 prints** (`back_right` = grip **+ fixed tray in one part**, `back_left`, 2 grip lids, nub spring + cap) + 2 **TPU grippers** | 1 | Retention is entirely mechanical (TPU grippers + capture lips + spring clamp) — no magnets. All parts fit a 220 × 220 bed. |
| Pointing nub | **TMAG5273A1** hall sensor (C3716049, on the right board) + **Ø4 × 2 mm N45 disc magnet, axially magnetized** (supermagnete **S-04-02-N**) in the printed spring | 1 + spare magnets | v0.21: the only added electronics is one SOT-23-6 — machine-placed with everything else. v0.22: the spring's post is a standard TrackPoint square platform — genuine classic caps fit; a red soft-dome replica prints in TPU. **v0.26:** the magnet is now a real body in the CAD (it had only ever been a *hole*) and sits a measured **3.33 mm from the hall element** — not the 2.6 mm the old comment claimed, which was the distance to the outside of the chip package rather than to the sensing element 0.73 mm inside it. The flexure was re-derived against the TrackPoint IV spec and **kept at 0.8 mm** (thickening it would have made the nub nearly rigid); what it gained was a **root fillet** at the arms' square T-junction — where every model put peak stress — and a **0.35 mm plunge stop**, without which pressing harder sped the cursor up at constant tilt. Grade is N45, **not** N52: N52 tops out at 65 °C and the loss is irreversible. |
| M3 hardware | **M3×10 countersunk** screws + M3 heat-set inserts (Ø4.0 bores) | 10 + 10 | Heads flush with the face (v0.19). 5 per grip lid, and that is all of them: v0.24 deleted the 4 center-panel screws, and v0.25 deleted the tray's own 2 by printing it as part of `back_right`. |

---

## Firmware & software

### How it works — matrix, GPIO, power, antenna

- **One matrix, not a split.** A single 9×10 matrix scanned by one module. Right grip = COL0–4
  (local); left grip = COL5–9 (over the ribbon); ROW0–8 shared. This is a ZMK **unibody** board —
  *not* `CONFIG_ZMK_SPLIT`. [`docs/matrix-and-diodes.md`](docs/matrix-and-diodes.md).
- **GPIO:** 19 matrix pins + 1 battery ADC, plus a spare I²C (SDA/SCL/INT) broken out to test pads
  TP6–8 for a rev-B trackpad. COL9 sits on P0.04/AIN2 — the XTAL pins (P0.00/P0.01) are deliberately
  kept free.
- **Power electronics all in the right grip:** cell → charger (cell side) → **power switch** → VBAT →
  the module's VDDH — topology unchanged. The cell itself sits in the LEFT grip (v0.18), and since
  **v0.27** its whole path is `cell → J4 → F1 (PPTC) → J2 → ribbon → right board`: the connector and
  the fuse are on the left board, and **VBAT_CELL crosses on the bridge ribbon** instead of on a
  separate 2-wire cable. So the bridge carries power as well as logic, and the ribbon is live
  whenever the cell is plugged in — the switch gates only the load. VBAT_SENSE (R22/R23/C6 → AIN0)
  is unchanged.
- **Antenna:** the E73's ceramic antenna points **up, off the top board edge** (v0.17 — centre-top,
  farthest from the phone/LiPo and off the edge the palm doesn't cradle), with an all-layer keep-out
  crossing the edge and a 0.6 mm relief in the shell wall. Expect the phone + hand to detune range
  somewhat; re-check on the first article.

A block diagram lives in [`docs/diagrams/`](docs/diagrams/). Every other document is indexed in
[Which doc answers which question](#which-doc-answers-which-question).

### Building the firmware

- **Config:** [`firmware/zmk-config/`](firmware/zmk-config/), pinned to **ZMK v0.3.0** — the last
  HWMv1-compatible release (Zephyr 3.5).
- **Board, not shield:** [`config/boards/arm/thumbdeck/`](firmware/zmk-config/config/boards/arm/thumbdeck/)
  is a real ZMK board definition (`thumbdeck.dts`, `thumbdeck.keymap`, `thumbdeck_defconfig`, …)
  describing a **unibody** keyboard. The matrix transform and keymap in there are *generated* by
  `gen_firmware.py` from the same model as the PCB, so a key cannot exist on the board and be missing
  in the firmware.
- **CI:** [`.github/workflows/build.yml`](.github/workflows/build.yml) is a **self-contained** build
  (deliberately not ZMK's reusable `build-user-config` workflow, which assumes the config sits at the
  repo root — ours lives under `firmware/zmk-config/`). It runs
  `west build -s zmk/app -p always -b thumbdeck` and uploads the result as the artifact
  **`thumbdeck-zmk-uf2`**, containing `thumbdeck-zmk.uf2`.
- **Locally:** `cd firmware/zmk-config && west init -l config && west update && west zephyr-export`,
  then the same `west build` line with
  `-DZMK_CONFIG="$PWD/config"`.
- **Status:** the firmware **compiles green in CI** (a ≈137 KB `thumbdeck-zmk.uf2` was produced on
  2026-07-15). It has never been flashed to hardware, because no hardware exists. Compiling is not
  working.

---

## Build guide

Path: **order boards (turnkey, no routing left to do) → press domes → print shells + keymats →
assemble + FFC jumper → battery → first flash → pair.** Full detail in
[`docs/assembly.md`](docs/assembly.md).

> Nobody has executed these steps. They are derived from the design, not transcribed from a build.

### Step 1 — Order the boards

Nothing is left to route: both boards are **DRC-clean and fully routed**, and the JLCPCB package is
one `gen_fab.py` run away.

1. Upload `hardware/kicad/generated/fab/right/thumbdeck_right_gerbers.zip` + `bom.csv` +
   `positions.csv` as one JLCPCB PCBA order, and the `fab/left/` set as a **second, separate order**
   (two different designs — panelizing them costs more than it saves). That directory is a build
   artifact and is not committed; regenerate it with
   [the pipeline](#reproduce-the-design) (`python3 hardware/scripts/gen_fab.py`).
2. Options: **4-layer**, 1.6 mm FR-4, **ENIG** (snap domes need gold — HASL oxidises within weeks of
   cycling), assembly side = **bottom**, single-sided. The right board needs **Standard** assembly
   (the E73 is Extended + X-ray); the left board (42 diodes + the ZIF + v0.27's J4 and F1) can go Economic.
3. **Check the DFM preview before paying** — LED polarity (the classic JLC 180° flip), SOT-23-5/6
   rotation, USB-C and E73 orientation. Rotate in the preview if needed.
4. Rough target **~$150–250 for 5 sets** — **boards + assembly only**; costing detail and part
   numbers in [`docs/fabrication-sourcing.md`](docs/fabrication-sourcing.md); re-quote at order time.
   **E73 stock is volatile** (observed from ~1000 down to ~20 units within days) — check
   jlcpcb.com/parts for **C356849** and **reserve/backorder the modules before anything else**.

### Step 2 — Domes, retention, keymat

- Press the **78 Snaptron domes** onto the gold pads under the **polyimide retention tape/array**
  (pockets locate each 7 mm dome; the tape channels vent them).
- Print the **shells** (PETG) and the **keymat** (TPU 95A); validate boss travel + hinge fatigue on a
  3×3 coupon **before** committing the full mat.

### Step 3 — Assemble

- Everything soldered arrives soldered — there is **no hand-soldering step**.
- **FFC jumper first** (the ZIFs hide under the lids): **≥240 mm, 20-way, type-A** ribbon between the
  two ZIF connectors, **contacts facing the board at both ends** (bottom-contact ZIFs); flip the
  latches closed. **Ribbon before the cell, always** — since v0.27 two of its conductors are the raw
  cell, so seating it with the battery plugged in is a live operation. Then seat the ribbon into its
  tray lane.
- **Battery first (v0.18):** foam-tape the 403040 to the LEFT grip's floor before the left board goes
  in — the cell lives UNDER the left PCB, and since **v0.27** its pigtail reaches **J4 on that same
  board**, so nothing has to be routed across the spine. Then seat each board on its 3 support posts
  + perimeter bosses; screw on each grip lid
  (5 × M3×10 CSK). Route the FFC through the tray — which since v0.25 is already part of
  `back_right`, so there is nothing to bolt — lap the left grip's inner shroud into it, then press
  the TPU grippers on. The battery is serviced by opening the left grip. v0.24d: the ribbon threads its
  **own walled channel** with a spring in each outboard lane (**v0.27:** `spring | FFC | spring` —
  the power lane is gone) — thread it before the shrouds are lapped together, and don't let the
  service loop sit across a divider rib. Full order:
  [`docs/assembly.md`](docs/assembly.md).
- **Battery:** meter the pigtail against the **"+"/"−" silk at J4 — on the LEFT board** (pin 1 = "+")
  first (vendors wire PH pigtails both ways) — but **do not connect the cell until after the first
  flash** (REGOUT0 must be programmed first — see [`docs/assembly.md`](docs/assembly.md)). Slide
  switch OFF for assembly. Use a cell with an **integrated PCM**; **F1** on the left board covers the
  band the PCM does not, and neither substitutes for the other.

### Step 4 — First flash, pair

- The E73 ships **blank**. One-time step: SWD-flash the **Adafruit nRF52 bootloader (nice_nano
  build)** via TP1–5 (a `nrfjprog --recover` may be needed first). The bootloader sets
  REGOUT0 = 3.3 V. **This step needs a debug probe** and is the most likely place to get stuck.
- From then on it's UF2: double-tap reset (pinhole) → drag the CI-built `thumbdeck-zmk.uf2` on.
- **Pair:** the host pairs to a device advertising as **"thumbdeck"** (that is the literal
  `ZMK_KEYBOARD_NAME` in the board definition — not a typo for Gripster). No inter-half pairing. Type
  across both grips — a dead **column** on the left → suspect the ribbon seating; a dead **row** hits
  **both** grips (rows shared). Confirm battery % over BLE.

---

## Design & generation (the parametric model)

### Fabrication view + real KiCad boards

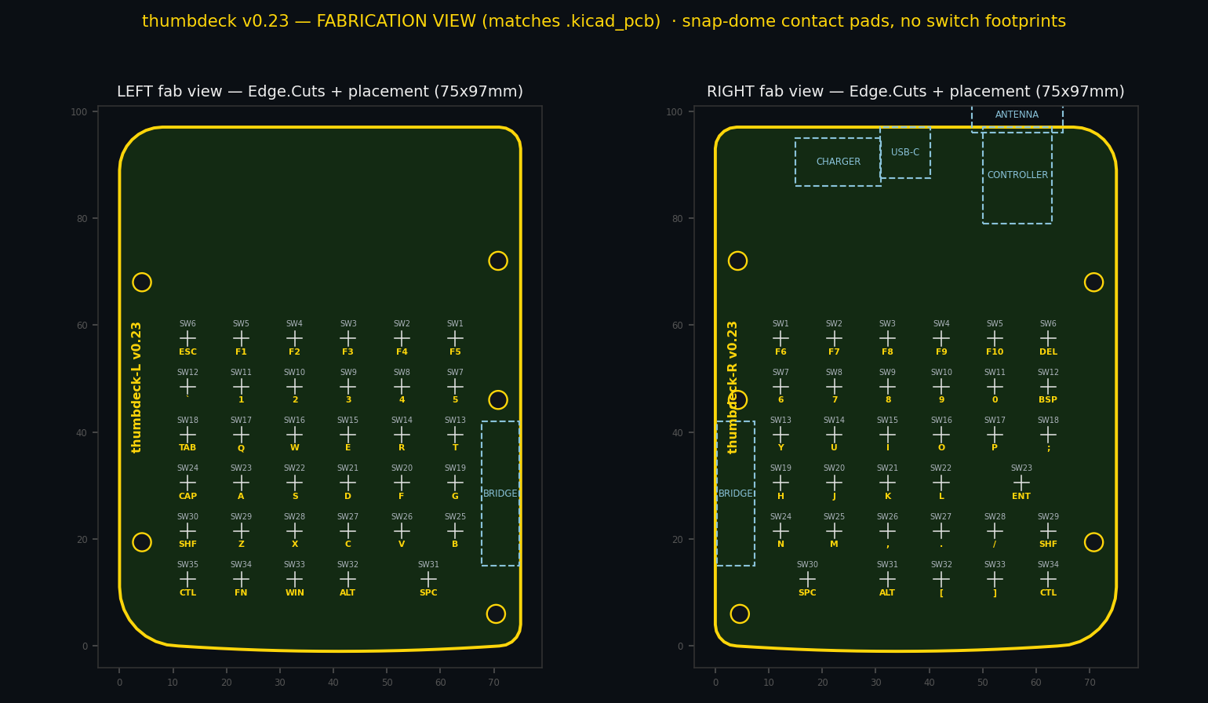
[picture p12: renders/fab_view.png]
Fabrication view


The generated boards are **real, routed, DRC-clean KiCad 9 files** —
[`hardware/kicad/generated/thumbdeck_right.kicad_pcb`](hardware/kicad/generated/thumbdeck_right.kicad_pcb)
(36 domes + 36 diodes + module + power front-end; 75 nets, 114 footprints) and
[`thumbdeck_left.kicad_pcb`](hardware/kicad/generated/thumbdeck_left.kicad_pcb) (42 + 42, no active
parts, 60 nets since v0.27 added J4 and F1) —
**0 DRC violations, 0 unconnected items** on both (`kicad-cli 9.0.9`, error severity; both boards
re-routed and re-verified for v0.27's 20-way bridge). The full fab package (4-layer
gerbers, JLC-format BOM + CPL) exports to `hardware/kicad/generated/fab/`; the exporter refuses to
run unless DRC is clean. Routing is fully autonomous — Freerouting + a GND stitcher + a DRC gate; see
[`docs/routing-status.md`](docs/routing-status.md).

Three placement constraints moved with the wider connector, and they are frozen: `deck.py`'s
inner-mid M3 mount hole went from `board_h × 0.42` (40.74) to a fixed **46.0** — its Ø8 boss disc was
the only thing capping the connector's pin count — and **J2 moved from deck y 24.5 to 28.5** on both
boards, because the 21 mm ribbon would otherwise overlap the clamp's front spring lane. J2's land is
26.85 mm long with 4.08 mm to the boss (the gate is 4.00). **VBAT_CELL/VBAT now route at 0.4 mm** via
a real power netclass injected in `route.sh`'s DSN rewrite; before v0.27 `gen_board.py`'s `PWR = 0.5`
was dead code and VBAT_CELL shipped at 0.2 mm — ~336 mΩ, a third of the whole charge loop.

*Caveat worth stating plainly: 0 DRC violations means no design rule was broken. It does not mean the
circuit is correct, and no board has ever been powered.*

Like the i8+: the **front** carries only the snap-dome contact pads and front-layer traces; the
**back** carries everything soldered — the 78 diodes, the Ebyte module, charger, USB-C, ESD, power
switch, reset tact, charge LED, FFC connectors, passives. All parts on one side makes the SMT job
**single-sided** (one stencil, one pass) and **100 % turnkey** — there are no hand-soldered parts.
The USB-C shell's plated stakes and the FFC/slide-switch locating pegs are the only through-board
features, and they are all placed in the same single-pass JLC assembly.

### Reproduce the design

```bash
cd hardware/scripts
python3 gen_board.py                  # placement + netlist + deterministic USB copper + GND escape vias
./route.sh right && ./route.sh left   # Freerouting autoroute -> GND stitch + zone fill -> DRC gate
python3 gen_fab.py                    # gerbers/BOM/CPL per side (refuses to export unless DRC-clean)
python3 verify_alignment.py           # top-to-bottom 2D stack audit: PCB domes/diodes vs model, cap gutters, boss clearances
python3 sim_matrix.py                 # ghosting/NKRO proof (78 keys, 0 collisions) — FINAL PASS
python3 gen_firmware.py               # ZMK transform/keymap/gpio, generated from the model
python3 layout_gen.py --iter 23       # per-grip layout diagram -> renders/iter_23.png
python3 render_fab.py                 # Edge.Cuts + placement fab view -> renders/fab_view.png
# --- 3D (CadQuery; see docs/cad-process.md) ---
cd ../.. && hardware/cad/.venv/bin/python hardware/cad/deck3d.py --all --check --render
hardware/cad/.venv/bin/python hardware/cad/export_full_asm.py   # nested full-assembly GLB (KiCad boards + all parts)
```

Requires Python 3 + `matplotlib`; the board pipeline needs **KiCad 9** (`pcbnew` Python module +
`kicad-cli`) and a **Freerouting** jar (see [`docs/routing-status.md`](docs/routing-status.md)); the
3D generator uses a venv (create it from
[`hardware/cad/requirements.txt`](hardware/cad/requirements.txt) — the commands above assume it lives
at `hardware/cad/.venv/`).

The routing intermediates (`*.dsn`, `*.ses`), the DRC result JSONs and the `fab/` package are all
build artifacts and are **not committed** — run the pipeline to produce them.
[`hardware/layout/keymat.json`](hardware/layout/keymat.json) is the **original sketch
digitization** — historical; the layout source of truth is now the `LEGENDS` tables in `deck.py`. The
old 50-key / nice!nano design-loop scripts are archived in
[`hardware/scripts/legacy/`](hardware/scripts/legacy/).

---

## Contributing

Contributions are welcome — see [CONTRIBUTING.md](CONTRIBUTING.md), and please read the
[CODE_OF_CONDUCT.md](CODE_OF_CONDUCT.md).

The most valuable thing anyone can contribute right now is **not code**. It is:

1. **A first-article build.** Someone ordering rev-A and reporting what's wrong is worth more than
   every other contribution combined. Open an issue with photos — especially if it doesn't work.
2. **Ergonomic critique.** If you have built or used a thumb-typed device, the
   [Open design calls](#open-design-calls) are real open questions: flat ortho grid vs a canted arc,
   shoulder buttons, key pitch.
3. **A KiCad or RF review.** The boards are autorouted and DRC-clean, which is not the same as good.
   Antenna keep-out, ground stitching and the power front-end all deserve a second pair of eyes.
4. **A ZMK review** of the board definition in
   [`firmware/zmk-config/config/boards/arm/thumbdeck/`](firmware/zmk-config/config/boards/arm/thumbdeck/).

One rule specific to this repo: **the generated files are outputs, not sources.** Do not hand-edit
`hardware/kicad/generated/`, `hardware/cad/models/` or `renders/`. Change
[`hardware/scripts/deck.py`](hardware/scripts/deck.py) or the generators, re-run the pipeline in
[Reproduce the design](#reproduce-the-design), and commit the regenerated output alongside the
change.

---

## License

Licensed under the Apache License, Version 2.0 — see [LICENSE](LICENSE) and [NOTICE](NOTICE).
Copyright © 2026 Eric Neuman.

```
Licensed under the Apache License, Version 2.0 (the "License");
you may not use this file except in compliance with the License.
You may obtain a copy of the License at

    http://www.apache.org/licenses/LICENSE-2.0

Unless required by applicable law or agreed to in writing, software
distributed under the License is distributed on an "AS IS" BASIS,
WITHOUT WARRANTIES OR CONDITIONS OF ANY KIND, either express or implied.
See the License for the specific language governing permissions and
limitations under the License.
```

This covers the original hardware design, the parametric model and generator scripts, the firmware
configuration and the documentation in this repository.

### Third-party components

Some files in this repository come from elsewhere and carry their own terms. They are **not**
relicensed by the above.

| Component | Origin | License |
|---|---|---|
| Footprints in [`hardware/footprints/thumbdeck.pretty/`](hardware/footprints/thumbdeck.pretty/) derived from marbastlib — exactly two: `nRF52840_E73-2G4M08S1C` (the E73 module, used on the shipped boards) and `CON_JST_ACH_BM02B` (unused spare) | [marbastlib](https://github.com/ebastler/marbastlib) by ebastler | **CERN-OHL-P-2.0** — full text preserved unmodified at [`marbastlib-LICENSE`](hardware/footprints/thumbdeck.pretty/marbastlib-LICENSE) |
| Stock KiCad footprints — those embedded in the generated `.kicad_pcb` files, plus the vendored copy of `USB_C_Receptacle_HRO_TYPE-C-31-M-12` in `hardware/footprints/thumbdeck.pretty/` | KiCad Libraries | CC-BY-SA-4.0 with the KiCad library exception |
| [`hardware/cad/assets/s25_ultra.glb`](hardware/cad/assets/) — phone model, used for fit-checking and visualization only | *provenance not yet established* | *to be stated — see [NOTICE](NOTICE)* |
| Images in [`references/`](references/) — one Rii i8+ product photo and two i8+ teardown photos, used as design reference only | *provenance not yet established — neither photographer nor source is recorded anywhere in this repo* | **Unknown. No licence is asserted and none can currently be substantiated.** Provenance must be established, or the files removed, before redistribution — see [`docs/reference-notes.md`](docs/reference-notes.md) |

The other footprints in `hardware/footprints/thumbdeck.pretty/` — `ffc_afa07_s20fcc` (the shipped
20-way bridge connector), `ffc_afa07_s16fcc` (the 16-way it replaced, kept because the committed
rev-A boards reference it), `msk12c02_slide`, `snaptron_7mm_contact`, `snaptron_7mm_simple` — are
original work drawn from manufacturer land-pattern drawings and are covered by the Apache-2.0 grant
above, not by any third-party licence.

Nothing in the buildable output (PCBs, shells, keymats, firmware) depends on the `references/`
images; no i8+ artwork, geometry, footprint or firmware was copied into this design. "Rii" is a
trademark of its respective owner; this project is not affiliated with, endorsed by, or sponsored
by Rii.

Fuller attribution notes in [NOTICE](NOTICE), which covers the marbastlib footprints, the phone
GLB and ZMK.

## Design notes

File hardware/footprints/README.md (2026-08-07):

# hardware/footprints — thumbdeck footprint library (rev-A)

`thumbdeck.pretty/` is the library the board generator loads (alongside the stock
KiCad libraries). The custom footprints below are **as-fabricated** — they are on
the routed, DRC-clean boards and were verified against manufacturer drawings in
2026-07 (the 20-way ZIF in 2026-08). Do not edit them casually: `gen_board.py` and
the routed `.kicad_pcb` files depend on their exact geometry.

## `snaptron_7mm_contact` — the production snap-dome footprint

For the Snaptron 7 mm 4-leg dome (SnapForce), pressed (not soldered) onto the pads:

- **Pad 1 = centre contact, Ø2.86 mm** (Snaptron P1 spec) — the column net.
- **Pad 2 = leg ring, 4.4–6.9 mm dia** (T1/W1/N1), drawn as **13 overlapping
  circles spanning 292°** with a **67.5° escape gap** at +y — the corridor the
  column trace uses to reach the centre pad. Worst-case dome rotation keeps
  **3 of 4 legs on the ring**.
- Full solder-mask apertures over both contacts (bare metal for the dome).
- **F.Cu keepout r 3.8:** tracks allowed (they're mask-covered) but **no vias, no
  pour**; plus an **all-layer via keepout r 3.6** — a tented-via bump under the
  dome seat breaks contact, and Freerouting only honours via keepouts that cover
  every layer.
- **No vent hole** — venting comes from the Snaptron retention-tape channels.
- Ring circle angles must match `RING_ANGLES` in `gen_board.py`.

Why not two simple pads: a dome rotated ~45° on the old 2-pad proxy
(`snaptron_7mm_simple`, kept for reference only) lands legs off-copper → **dead
key**. The continuous ring makes rotation irrelevant.

> **Surface finish: ENIG is mandatory.** An old note here claimed HASL was fine —
> that was written for the abandoned soldered-tact-switch design and is **wrong**
> for snap domes: they press on bare pads, and HASL oxidises into rising contact
> resistance within weeks of key cycling. Order ENIG; hard gold is a
> production-volume upgrade only.

## `ffc_afa07_s20fcc` — the bridge ZIF (current, v0.27)

JUSHUO **AFA07-S20FCC-00** (LCSC **C262352**, JLC **Extended**): FFC/FPC ZIF,
**1.0 mm pitch, 20 positions, side entry, BOTTOM contacts**, slide-lock drawer,
2.5 mm tall, 0.3 mm FFC, tin plating. Land pattern per the customer drawing —
same family rule as the 16-way (nail pad = `(N−1)/2 × pitch + 2.35`): 20×
0.6×1.8 mm pads at 1.0 mm + 2 nail pads 2.6×3.0, land 26.85 mm long. One per
grip, on the inner edge at deck y **28.5**, cable opening toward the spine.
Mates with a **20-way, 1.0 mm pitch, TYPE-A (contacts on the SAME side at both
ends)** jumper, **≥240 mm** (the v0.24 clamp span is variable, so the ribbon
carries a rolling service loop) — the left grip's pin→net assignment is generated
from ribbon geometry, so the straight jumper is correct by construction.

Since v0.27 this ribbon carries the **battery as well as the matrix**: the four
extra conductors over the 16-way are `NC | VBAT_CELL | VBAT_CELL | NC`, which is
what deleted the separate 2-wire power cable. Two consequences the geometry
alone won't tell you:

- **Buy 20-way, and buy TYPE-A. Do not use a leftover 16-way ribbon.** A 17.0 mm
  16-way ribbon drops into this 21.0 mm housing with **4.0 mm of independent slop
  at each end** — up to a 4-position shift. The conductor order is chosen so the
  worst achievable shift lands VBAT on a *column* (one dead MCU pin) rather than
  on GND (a dead cell short), but that is a last line of defence, not a licence.
  The silk names the width and the type for the same reason.
- **The cell path is fused on the cell side** (F1, a 0.75 A-hold PPTC on the left
  board) because a 1.0 mm-pitch FFC conductor is only 0.0245 mm² — see
  [`docs/design-decisions.md`](../../docs/design-decisions.md).

## `ffc_afa07_s16fcc` — the rev-A 16-way ZIF (superseded, KEPT)

JUSHUO **AFA07-S16FCC-00** (LCSC C13744): the same connector in **16 positions**,
16× 0.6×1.8 mm pads + 2 nail pads, land 22.85 mm long. Superseded by the 20-way
above in v0.27 and **kept on purpose** — the committed rev-A boards reference this
file and must keep loading. It is not what a current build orders.

## `msk12c02_slide` — the power switch

SHOU HAN **MSK12C02** SPDT slide (LCSC C431540): body 8.0×2.8×1.4 mm, knob
protrudes ~1.5 mm from the −y face, 1.6 mm travel. Land per the manufacturer
drawing: 3 signal pads (**pin 2 = common**) + 4 mechanical lug pads + 2× Ø0.85
NPTH locating holes. Wired between cell+ and the VBAT rail; the knob passes
through the 8×2.8 slot in the top shell wall (v0.17 moved the electronics cluster
and its shell openings to the top zone).

## Also in the library

| Footprint | Use |
|---|---|
| `nRF52840_E73-2G4M08S1C` | Ebyte E73 module — 13×18 mm, 43 pads (28 castellated + 15 inner, 1.27 mm), **antenna keep-out embedded** (all-layer, crosses the board edge as placed). Pad N = Ebyte datasheet pin N; from marbastlib (see `marbastlib-LICENSE`), verified against the Ebyte User Manual. |
| `USB_C_Receptacle_HRO_TYPE-C-31-M-12` | full-SMD 16P USB-C (C165948). |
| `snaptron_7mm_simple` | historical 2-pad routing proxy — **not for fab**. |
| `CON_JST_ACH_BM02B` | unused spare (JST ACH 2-pos); the battery connector is the stock-library JST-PH `S2B-PH-SM4-TB` — **J4 on the LEFT board** since v0.27 (it was J3 on the right). |
| `../snaptron_7mm_contact_pad.kicad_mod` | earlier standalone draft of the contact footprint, superseded by `thumbdeck.pretty/snaptron_7mm_contact`. |

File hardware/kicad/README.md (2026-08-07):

# hardware/kicad — generated boards + autonomous fab pipeline (rev-A)

Everything in `generated/` is produced headlessly by the pipeline in
`hardware/scripts/`. **Both boards are fully routed and DRC-clean** (0 violations,
0 unconnected, kicad-cli 9.0.9) and the JLC fab package exports cleanly. Nothing
here is hand-drawn; to change the board, change the model/scripts and regenerate.
**The boards are unbuilt** — nothing here has been fabricated or bring-up tested,
and DRC-clean means no rule is violated, not that the circuit is correct.

## The pipeline

```bash
cd hardware/scripts
python3 gen_board.py                  # placement + full netlist + deterministic USB copper
                                      #   + GND escape vias -> generated/thumbdeck_{right,left}.kicad_pcb
./route.sh right                      # Specctra DSN (In1 marked power, + a 0.5mm `power`
                                      #   netclass for the cell path) -> Freerouting (-Xss16m)
./route.sh left                       #   -> SES import -> stitch.py (GND vias + zone fill) -> DRC -> renders
python3 gen_fab.py                    # gerbers/BOM/CPL per side; REFUSES to export unless DRC is 0/0
python3 sim_matrix.py                 # 78-key matrix ghosting/NKRO proof (final pass)
```

Requirements: **KiCad 9** (`pcbnew` Python module + `kicad-cli`), a Java runtime
and **freerouting.jar**. Note that `route.sh` currently **hardcodes the author's
toolchain paths** for both (the `JAVA=` and `FR=` lines at the top) — edit them to
match your machine before running it. Details and quirks in
[`docs/routing-status.md`](../../docs/routing-status.md).

## What's in `generated/`

| file | what |
|---|---|
| `thumbdeck_right.kicad_pcb` / `thumbdeck_left.kicad_pcb` | routed, DRC-clean 4-layer boards (F.Cu / In1 GND plane / In2 / B.Cu) |
| `thumbdeck_*.kicad_pro/.kicad_prl/.kicad_dru` | project + 0.2 mm rules (via 0.6/0.3) |
| `thumbdeck_*.dsn` / `thumbdeck_*.ses` | Freerouting in/out (local build artifacts — git-ignored, regenerate with `route.sh`) |
| `drc_right.json` / `drc_left.json` | DRC results: **0 violations, 0 unconnected** (error severity) — git-ignored, regenerate with `route.sh` |
| `fab/right/`, `fab/left/` | **the order package**: `thumbdeck_*_gerbers.zip` + `bom.csv` + `positions.csv` (JLC format) — git-ignored, regenerate with `gen_fab.py` |
| `thumbdeck_*_placement.csv` | placement summary (ref, value, x, y, rot, side) |

## Ordering

Two **separate** JLCPCB PCBA orders (right + left — don't panelize two different
designs): 4-layer, 1.6 mm FR-4, **ENIG (mandatory — snap-dome contacts)**, assembly
side **bottom**, Standard assembly for the right board (E73 = Extended + X-ray),
Economic OK for the left. Check the DFM preview for part rotations (LED polarity,
SOT-23s, USB-C, E73). Full walkthrough:
[`docs/fabrication-sourcing.md`](../../docs/fabrication-sourcing.md).

## Notes

- **v0.27 (2026-08-07):** the bridge is a **20-way** 1.0 mm ZIF (JUSHUO
  AFA07-S20FCC-00, LCSC C262352) whose four extra conductors carry the cell across
  the spine, so the separate battery cable is gone. **J3 is deleted from the right
  board**; the left board gains **J4** (JST-PH-2, C295747) and **F1** (Bourns
  MF-MSMF075-2 PPTC, C84140) — so the left board is no longer purely passive, and
  its BOM has two placements it did not have before. J2 sits at deck y 28.5 on both
  boards. Both boards were re-generated and **re-routed to 0/0** with the new parts.
  The `power` netclass injected by `route.sh` is what finally gives the cell path
  its 0.5 mm width; details in
  [`docs/routing-status.md`](../../docs/routing-status.md).
- The boards are frozen build artifacts — regenerate rather than hand-edit; the
  DRC gate in `gen_fab.py` protects the export either way.
- Opening them in the KiCad 9 GUI is fine for inspection; the pipeline does not
  depend on the GUI for anything.

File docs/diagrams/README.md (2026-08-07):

# docs/diagrams

> **Historical.** `architecture.svg` shows the **v0.2 two-controller BLE split**
> (LEFT peripheral ⇄ BLE ⇄ RIGHT central) — an architecture abandoned in v0.3.
> The current rev-A design is a **single** E73 (nRF52840) in the right grip
> scanning one 9×10 matrix, with the passive left grip wired over a **20-way**
> FFC jumper (14 matrix signals + the battery, since v0.27 — there is no separate
> power cable). See the architecture diagram in the [README](../../README.md#how-it-works--matrix-gpio-power-antenna)
> and [connectivity-and-power.md](../connectivity-and-power.md).

- `architecture.svg` — v0.2 split architecture (historical, kept for the record).

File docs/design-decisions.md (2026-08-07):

# Design decisions

Decision log, newest first. Older entries are **history** — they record why calls
were made at the time and may name parts since replaced (Raytac → E73, Cirque /
IQS7211E trackpad → dropped, JST-GH → FFC ZIF, nice!nano → bare E73 board,
16-way FFC → 20-way, battery connector J3-on-the-right → J4+F1-on-the-left). The
current design is rev-A / v0.27 (first entry).

## v0.27 — the battery rides the bridge ribbon (2026-08-07, branch main)

The 403040 has lived in the **left** grip since v0.18; the charger, the switch and the
E73 have lived in the **right** grip since v0.8. Between them ran a two-wire pigtail
~265 mm long, across the spine, through a mechanism that moves on every phone insertion,
in an enclosure lane of its own. v0.27 deletes that cable. The bridge FFC goes **16-way →
20-way** (JUSHUO **AFA07-S20FCC-00**, LCSC **C262352** — same 1.0 mm pitch, bottom
contact, side entry, slide lock, 2.5 mm height, same JLC **Extended** tier, so no
assembly-class change) and four of the extra conductors carry the cell.

The **14 matrix signals are unchanged**, so ROW0–8 / COL0–9 land exactly where they did
and **the firmware is completely unaffected** — not "regenerated identical", untouched.

### Why the ribbon, and not a second connector pair

Three options: keep the pigtail, add a dedicated 2-pin connector at each end of a proper
cable, or spend four conductors on the ribbon that already crosses. The third wins on
every axis that matters here, and the v0.24d entry below is the evidence for most of it:

- **The second cable is where the enclosure kept failing.** Every v0.24c/d cable fault
  was the power lane's: it was the lane the tray's single end-wall window missed
  entirely (cut at y 15–33, lane at y 40), and its envelope was the one hanging 0.95 mm
  below the moving shroud's underside at full extension. One cable in one walled channel
  is not a smaller version of that problem — it is the problem deleted.
- **Part count goes DOWN, not up.** A dedicated pair costs two connectors, a cable and a
  second service loop. The ribbon route adds one connector (J4) and deletes one (J3), so
  the count is flat — and the ribbon's service loop already exists and is already ribbed
  off from both springs.
- **The cell finally terminates in the grip it lives in.** ~8 mm of pigtail to J4 instead
  of ~265 mm of bare two-wire to the other grip. That is the actual safety win; the fuse
  below is what pays for putting the cell on a flat flex.
- **Freed volume.** `POWER_Y`/`POWER_W`/`POWER_T` are gone and y 40.0–82.5 inside the
  clamp cavity is now empty — the lane plan reads `spring | FFC | spring`.

The costs, stated rather than buried: the ribbon now carries the **raw cell**, which is
what forces F1; and the left board **stops being purely passive**, which is what forces
J4. Both are treated as requirements below, not as nice-to-haves.

### Why 20-way and not 24

A 24-position sibling exists in the AFA07 family (confirm the exact suffix and LCSC
code against the JUSHUO drawing before ordering — this design never sourced one) and four
more guard conductors would be pleasant. It does not fit the board. J2 sits between the chin
mount hole at deck y 6.0 and the inner-mid mount hole, and it is the inner-mid hole's
**Ø8 boss disc** — not the board edge, not the routing — that caps the connector's pin
count. At 20 positions the land is **26.85 mm** long with **4.08 mm** to the boss against
a 4.00 mm gate: 0.08 mm of margin, and only after moving that hole from `board_h*0.42`
(= 40.74) to a **frozen 46.0**. A 24-way needs the hole at **≥50.0** — i.e. moving a
mount hole, its boss, its screw and the shell around it, to buy guard positions that F1
and the pin order below already make unnecessary.

The `0.42` is worth a sentence of its own. A hard geometric requirement had been hiding
behind an innocuous-looking fraction that nothing was allowed to notice; it is an
absolute now, with the reason written next to it.

### F1 is required. It is not belt-and-braces.

**Bourns MF-MSMF075-2** PPTC, LCSC **C84140**, 1812, **0.75 A hold / 1.5 A trip**,
13.2 V, Imax 100 A, initial resistance ≤0.45 Ω. On the **left** board at deck
(50.0, 5.5), in series with the cell **positive**, between J4 and J2 — on the **cell**
side of the ribbon, or it protects nothing at all.

The reasoning is a gap between two protections, not a duplication of either:

- A 1S pouch's built-in PCM does not trip until **2.0–2.5 A**.
- A 1.0 mm-pitch FFC conductor is **0.70 × 0.035 mm = 0.0245 mm²**. It reaches its
  105 °C insulation limit at about **2.8 A·√s**, and at a real short it melts its own
  PET in **~0.2 s**.
- Between them sits the **0.43–2.0 A** band: too little for the pack to notice, more than
  enough to cook the ribbon over seconds to minutes. That is precisely the signature of a
  **partially abraded conductor in a mechanism that flexes on every phone insertion** —
  the one failure this device's geometry actively invites — and nothing else covers it.

0.75 A hold rather than 0.5 A because the part derates with temperature and has to stay
clear of the ~196 mA charge current in a device designed to sit on a car dash.

**The cell must also be a protected pack — that is now a hard requirement, not advice.**
Integrated PCM with overcurrent 2.0–2.5 A / 8–16 ms, overcharge 4.275 V, overdischarge
2.75 V. The PCM and the PTC cover **different bands**; neither alone is sufficient, and
the BOM says so.

**What F1 costs: charge TIME, not capacity.** Its ≤0.45 Ω is in the charge loop, so
CC→CV handover happens at a lower cell voltage and the taper runs longer. The
*undercharge* at termination is `ITERM × R_loop` ≈ **10–16 mV**, which is negligible
beside the MCP73831's own **±32 mV** VREG tolerance — the charger's datasheet spread is
already twice the effect. What the loop resistance did deserve was a real trace:
`VBAT_CELL`/`VBAT` now route at **0.4 mm** via a genuine `power` netclass injected in
`route.sh`'s DSN rewrite. Before v0.27 `gen_board.py`'s `PWR = 0.5` was **dead code**
(KiCad 9 exposes no netclass setter through SWIG) and `VBAT_CELL` shipped at 0.2 mm —
about **336 mΩ**, a third of the entire charge loop, on a board that had a stated
intention to do better.

### The conductor order is an interlock, not packing convenience

Index 0 = **highest** deck y:

```
GND | GND | ROW0..ROW8 | COL5..COL9 | NC | VBAT_CELL | VBAT_CELL | NC
^ high deck y                                              low deck y ^
```

The hazard being designed against is **not** a one-position slip. It is the 16-way ribbon
every rev-A builder already owns: 17.0 mm of ribbon in a 21.0 mm housing has **4.0 mm of
independent slop at each end** — up to a **4-position shift**. `place_bridge()` maps the
left connector **by deck y**, so a shift joins right-net(k) to left-net(k+n), and only
nets present on *both* boards can fault.

- **GND is 15 positions from VBAT_CELL.** VBAT onto GND is a dead cell short — roughly
  10–16 A through one 0.0245 mm² conductor, which melts its own PET in ~0.2 s. At 15
  positions apart **no achievable shift can reach it**. The worst case instead lands VBAT
  on a **column**: ~50–100 mA into an MCU output NFET — one dead pin, no fire.
- **The two NC guards** absorb a ±1 slip completely, so VBAT never touches a matrix line
  for the ordinary error either. They carry **no net at all**, deliberately: tying them to
  GND would recreate exactly the short the guards exist to prevent.
- **No VBAT at a ribbon edge**, where a conductor is most exposed to abrasion.
- **Ribbon GND is not in the matrix return loop** (that closes through the right board's
  R1–R9 pulldowns and right-board GND), so exiling it to the far end costs no signal
  integrity — it is purely the battery return.
- **This ordering is only correct with F1 fitted.** Without the fuse the right answer
  changes shape entirely, which is another reason F1 is not an option.

**Consequence: purging "16-way" from the documentation is itself a safety item.** Any doc
still telling a builder what ribbon to buy in 16-way terms is actively dangerous now, so
every such reference across the repo moved to 20-way, and J2's silk names the **width and
the type** (`J2 FFC20 1.0mm TYPE-A <- pin1`) because getting either wrong is a short, not
a no-op.

### J3 out, J4 + F1 in — and why J4 has to exist

**J3 is deleted from the right board.** **J4** (JST-PH-2, S2B-PH-SM4-TB, C295747) is new
on the **left** board at deck (60.0, 5.5), mouth facing **+y**. Pin 1 = "+". Placement is
not free: `rot=180` would aim the plug off the bottom board edge into the shell wall, and
the naive mirror of the old right-board J3 at x = 31 would drive the mated plug's swath
straight into the cell. F1 sits west of it at (50.0, 5.5), clear of the cell footprint,
of the innermost diode column and of every boss. `VBAT_CELL` reaches the right board's
charger and switch over the ribbon; the power tree is otherwise **unchanged** — the
charger is still on the cell side of SW90, so it still charges while switched off, and
VBAT_SENSE (R22/R23/C6 → AIN0) is untouched.

J4 is **required**, not a convenience, and the reason is a live-parts argument: **SW90
gates only the LOAD**, so `VBAT_CELL` — and therefore the whole ribbon — is energised
whenever the cell is attached. Without a connector on the board the cell sits on, there
is no way to de-energize the ribbon for the service operation the docs advertise, and
[assembly.md](assembly.md)'s **battery-free first power-up** (the REGOUT0 / AIN0
absolute-maximum rule) becomes impossible to perform. So the build order changes:
**ribbon first, then J4** — and "battery-free" now means *J4 unplugged*, not *switch off*.

### The enclosure loses a lane and gains an assertion

`spring | FFC | power | spring` → **`spring | FFC | spring`**. `FLEX_Y` 26.5 → **28.5**,
`FLEX_W` 17.0 → **21.0**, `FLEX_T` still 0.3, `POWER_*` deleted.

The lane move is the more interesting half. v0.24d recorded that the FFC lane was kept at
"**J2's y centre (24.5)**" so the ribbon would enter the ZIF dead straight. **That was
false when it was written.** The lane was 26.5 and the connector was at 24.5 — a 2.0 mm
skew that ran the 17 mm ribbon off the pad row and put its first conductor outside the
housing altogether. 26.5 was never J2's y; it was the lane-plan *minimum* that the
spring-rib assert would accept, silently overriding the connector, and nothing objected
because the two numbers lived in different files and nothing compared them.

v0.27 makes the claim true and then makes it checkable. J2 moves to deck y **28.5** on
both boards — the 21 mm ribbon needs ≥28.20 to clear the front spring lane, and the
inner-mid mount boss is the ceiling — and `check_lanes()` now asserts the lane y against
**J2's slot centre read from the KiCad placement export** (to 0.25 mm) *and* the ribbon
width against J2's body, so a wrong pin count fails loudly too. `deck3d.py
--check-lanes` runs the whole thing in seconds, before any mesh work. The general lesson
is the same one v0.24d learned about its guards: a comment claiming two numbers are equal
is not a constraint, it is a wish.

### Boards

Both re-generated and **re-routed from scratch to 0 DRC violations / 0 unconnected**.
Right board: **75 nets, 114 footprints, 30 GND escape vias**. Left board: **60 nets**
(was 58 — `VCELL_RAW` and `VBAT_CELL` are new there). The footprint library gains
`ffc_afa07_s20fcc`; the 16-way file is **kept**, because the committed rev-A boards
reference it.

### The FFC duct, and why J2 was rotated to face inboard

A defect that **pre-dates v0.27** surfaced the moment the ribbon was modelled honestly:
there was no physical route from either ZIF into the enclosure lane, and never had been.
J2's cable slot sits at z ≈ 6.95 (the ZIF is back-mounted under a board at `PCB_Z` 7.9)
and the lane at z 0.2, and across the ribbon's y band the grip is solid from the tray end
to the cavity wall. With the slot facing the spine that left about **1.20 mm of x** in
which to lose **6.74 mm of z**. It could not be done.

Nothing caught it because *both* bridge cables were straight boxes in the lane reaching
neither connector, and a cable that reaches nothing touches nothing — `collide()` had no
opinion, and `cable_enclosure()` clipped 6 mm off each end, putting the connector ends
outside its window by construction.

Two ways to open the route, and the choice is structural:

- **Cut a full-height slot** from the lane up to the ZIF. No PCB change, no re-route —
  but at the ribbon's 23 mm y band that slot passes through the cradle backstop wall, its
  1.2 mm rest ledge and the bottom shelf, removing ~23 mm of phone-edge support out of
  ~78 mm on the one structure whose entire job is stopping a phone falling out.
- **Rotate J2 to face inboard** (chosen). The ribbon exits into ~10 mm of open back
  cavity, descends there, folds at z ≈ 2.2 and leaves through a **low duct** that passes
  *under* the retention structure — all of which lives at z ≥ 3.9. Costs one re-route and
  ~20 mm more ribbon, and buys back the cradle intact.

The duct is **stepped**, and that is not cosmetic. Only its grip-side half may be tall:
inboard of the grip's inner face the moving inner shroud's roof spans `CAV_Z1` 1.75 to
`izt` 3.15, so a straight 2.6-high cut across the whole duct left that roof **0.55 mm**
thick on an exposed outside surface — well under this file's own 3-perimeter convention
(`RIB_T` = 1.2). The grip side has no such roof (it is cutting the grip's own floor slab,
whose top is at 1.55), so it goes to `FLEX_DUCT_Z1` = 2.6 for the fold while the shroud
side stays a flat slot at `FLEX_DUCT_Z1_LANE` = 1.95. Measured result: **1.42 mm** of roof
left, and the ribbon's vertical drop is placed on the grip side of the face so it still
has the height it needs.

The descent is dimensioned, not eyeballed. `FFC_BEND_R` = 1.6 mm is charged against
`FLEX_TURN_X` = 2.0 mm, because a ribbon leaving a slot horizontally lands its vertical
leg one bend radius past the fold — sizing the fold to a zero-radius corner is how a
21 mm-wide ribbon ends up over a diode column. `check_lanes()` measures the resulting leg
against the real placement and asserts it clears the innermost back-side part: currently
**0.98 mm** (left, D25) and **1.03 mm** (right, D24).

`flex_route_report()` then sweeps the ribbon's **full 21 mm section** — not its centre
line — along the whole path and asserts nothing is buried in the shell. The centre-line
version of that test was written first and rejected: this repo's own v0.24e lesson is
that centre-line enclosure tests lie, and with 21 mm of ribbon in a 23 mm duct band the
width is exactly what is tight. Removing the duct makes it fail with the first
obstruction at y = 18.0 — the ribbon's *edge*, which a centre-line probe would have
walked straight past.

## v0.26 — the nub magnet becomes real, and the flexure gets a spec (2026-08-03, branch main)

The magnet had a **pocket** in `nub_spring` since v0.21 but never a **body**: it was in no
STL, no GLB, no render and no collision check. Adding it turned into an audit of the whole
pointing stack, because once you draw the magnet you have to say exactly where it sits, and
that number had never been written down.

### The magnet: a part you can actually order

The BOM said "Ø4 × 2 mm N52 disc, axially magnetized" with no supplier, no plating and no
tolerance. It now names **supermagnete `S-04-02-N`** (Ø4 × 2 mm, **N45**, Ni-Cu-Ni, axial,
Br 1.32–1.37 T) with a US part (totalElement `D4X2MMN52-250PK`) and an engineering-grade
alternative (Radial 9039 = Digi-Key `469-1072-ND`, N35SH, 150 °C, magnetization angle sorted
to ≤ 3°).

- **Grade drops N52 → N45.** N52 has the **lowest** service temperature of the common grades
  (≤ 65 °C vs ≤ 80 °C). This device clamps a phone, sits in sunlight and rides in cars. Past
  that limit the loss is irreversible and the driver's boot-zero *cannot* recover it — it
  re-zeros a weaker magnet and pointing goes quietly sluggish forever. N45 costs ~8 % of Br,
  which the firmware gain absorbs without noticing.
- **"(Bean spec)" was false.** The code comment credited the Ø4 × 2 size to the Ploopy Bean.
  The Bean's hardware appendix actually specifies **Ø6 × 2**, which our Ø7.0 hub cannot carry
  (the wall would drop to 0.5 mm). Ø4 × 2 is our own choice, made because it is a genuine
  mass-stock size that the hub *can* carry. The Bean also mounts its magnet **N away** from
  the sensor — the opposite of ours — so the polarity note is ours to own too.
- **Order by SKU, not description.** A Ø4 × 2 mm *diametrically* magnetized disc is also a
  cataloged product and is the wrong part.
- **The pocket was never a press fit.** It was drawn Ø4.10 for a Ø4.00 ±0.10 magnet, so a
  +tolerance magnet exactly equals the nominal bore — and FDM prints holes undersize. That is
  an interference fit being driven into a 1.45 mm wall by hand, and NdFeB is brittle. The bore
  opens to **Ø4.20** and retention becomes a drop of cyanoacrylate against the pocket ceiling.

### The gap nobody had computed

The docstring said the magnet sits "~2.6 mm over the back-side TMAG5273". That is the distance
to the **package**, and the package is not what measures anything. Per TI SLYS045C Figure 6-2,
the hall element sits **0.73 mm below the moulded top face** — and U4 is back-mounted, so its
mould face points *away* from the board and that 0.73 mm is *toward* the PCB. The real
magnet-face-to-die distance is **3.33 mm**:

```
magnet face 10.45 | 0.95 air | 1.60 FR4 | 0.06 solder | 0.72 package | die 7.12
```

`deck3d.py --report` now prints and asserts this whole stack instead of leaving it in a
comment. Modelled SOT-23-6 height also went 1.1 → **1.45 mm** (the real DBV figure), because
the die reference is measured off a face the model was placing 0.35 mm wrong.

At 3.33 mm a Ø4 × 2 N45 disc puts **~52 mT** on the die. Nothing saturates: the driver enables
**X and Y only**, and the axial field never enters a measured channel.

- **The X/Y range was wrong in the safe direction.** It was set to ±80 mT for "headroom vs the
  close nub magnet" — but X/Y only ever see the *transverse* field, which peaks around 12 mT
  including the static misalignment offset. v0.26 uses **±40 mT**, doubling resolution to
  1.2207 µT/count for free.
- **The hall element is 0.418 mm off the package axis** (+0.40 along the body, −0.12 across),
  and `gen_board` centres U4's *footprint* on the nub axis, so the die is off-axis by that much.
  This is left **uncompensated, deliberately**: it costs a static transverse offset the boot-zero
  removes and **under 1 %** response asymmetry once the flexure is stiff enough to stay in its
  linear range. Correcting it would mean either a board respin or de-coupling the mechanical nub
  from the feature that places the sensor. Recorded here so the next board spin can shift U4
  0.418 mm and take the 17 % of full scale back.

### The flexure: the arms were already right, but for no stated reason

The user's ask was a "ThinkPad-like experience of tension / pressure / travel", so the arms were
modelled properly for the first time. **Four** independent beam models got built — two here, two
adversarial — and the honest result is that **they agree on stress and disagree on stiffness by
7×.** That disagreement is itself the finding, so it is recorded rather than averaged away.

The reason is a boundary condition, not a modelling error. The arm is a 1.2 mm ribbon spiralling
r 3.6 → 5.9, so its first ~22 % is buried in the Ø7 hub and its last ~30 % in the flange bore.
Treat the whole 100° arc as a free beam and you get 2.6 N/mm; clamp it rigidly at both embedments
(48° free) and you get 18.3 N/mm. Neither is true — the hub is genuinely stiff, the 1 mm flange
ring is not — and no beam model can tell you where in between the real part sits.

What that bracket *can* settle is the design question, because the two candidates fall on opposite
sides of it. Against a target of **350–600 µm of cap travel at 150 gf** (the TrackPoint IV spec —
0–150 gf usable, 320 gf working — adapted to a hall nub, which unlike a strain gauge must actually
move to be read):

| arm thickness | cap travel at 150 gf | verdict |
|---|---|---|
| **0.8 mm (as built)** | **474 µm** (free-span) … **285 µm** (hub clamped) | **straddles the band** |
| 1.2 mm | 158 µm … 94 µm | below it under *every* assumption — nearly rigid |

So **`NUB_ARM_T` stays at 0.8.** An earlier pass of this same work had thickened it to 1.2 on the
strength of the softest model alone; correcting the embedment assumption reversed that. The v0.21
value was right — it simply had no stated reason, no target band, and no calibration procedure
attached to it. It now has all three, and arm thickness is documented as a **coupon-calibrated
parameter**: print at 0.7/0.8/0.9, hang 50/100/150 gf laterally off the cap, measure with a dial
indicator, and take the one nearest 350–600 µm. Do not trust a beam model here, including ours.

Peak arm stress at 150 gf is **23–29 MPa** against PETG's ~50 MPa yield — first yield around
300 gf. That is a thinner margin than one would choose, which is what the first change below is for.

Two changes the arms did need, both **independent of the stiffness argument**:

- **Root fillets.** The arm was a constant-width ribbon meeting the hub and the flange at a square
  re-entrant T-junction, and *every* model built — including the ones that disagreed about
  everything else — put peak stress at exactly that corner. The arm is now a two-sided offset
  polygon whose half-width swells 0.5 mm at both ends, shaped `(2s−1)^6` so the swell stays inside
  the last ~15 % — the zone where the arm is merging into the hub or flange anyway, so it costs no
  free slot at mid-arc. Peak stress drops ~19 % (28.6 → 23.1 MPa at 150 gf) and the peak migrates
  off the corner. This is the fix the stress numbers actually supported; thickening was not.
- **A plunge stop.** Nothing limited *axial* travel: the hub could sink the full 0.90 mm to the
  PCB, and because the magnet approaches the die over that stroke, Bz swung 52 → 92 mT and the
  pointing gain rose with it. The cursor sped up when you pressed harder **at constant tilt** —
  precisely the squishy, non-isometric feel a TrackPoint avoids. Three pads on the hub underside
  now bottom out at **0.35 mm**. (Note the stop is directionally uneven — it engages sooner toward
  a pad than between pads. Widening or adding pads is the follow-up if that reads as notchy.)

**Correction to v0.22.** That entry claims the cap skirt hitting the Ø10 aperture wall is the
"first tilt-stop" and that it keeps peak arm strain under 3.5 %. It does neither. The skirt has
1.1 mm of radial clearance and the cap moves ~54 µm/N laterally, so reaching that wall takes
**~20 N** — nothing a thumb will ever do. There is no tilt stop in the lid, and there never was.
What does bound overload is the v0.26 plunge pads (they ground out on the PCB in tilt as well as
in plunge) plus the arms' own ~300 gf first-yield margin. The "<3.5 % peak arm strain" acceptance
criterion should also be retired rather than re-used: PETG's yield strain is ~2.5 % (50 MPa /
2.0 GPa), so a 3.5 % budget is already past it. Judge stress against yield directly instead.

### Firmware is half of the feel, so it moved with the spring

`gain-div` is not independent of the arms — it converts field into cursor speed, so it inherits
the flexure's stiffness and the sensor's range. Two of the three changes here are unambiguous:

- **X/Y range ±80 → ±40 mT.** The old setting was justified as "headroom vs the close nub magnet",
  which conflates the axial field with the channels being measured. `MAG_CH_EN` enables X and Y
  only, and those never see more than ~12 mT. Halves the count size for free.
- **deadzone 150 → 100 counts.** Forced by the above: the range change halved the microtesla value
  of a count, so keeping 150 would have *doubled* the physical deadband. 100 counts = 0.122 mT ≈
  9.5 gf, about 2.8× the noise floor at 8× averaging.
- **`MAG_TEMPCO` → NdFeB (0.12 %/°C)** — a free register field left at "no compensation" for a
  magnet that is, in fact, NdFeB.

**gain-div 3500 → 1054 is a bracket, not a measurement**, and is labelled as such in the binding.
It inherits the flexure's 7× stiffness uncertainty: targeting full speed at 150 gf gives 615 at the
stiff end of the bracket and 1807 at the soft end. 1054 is the geometric mean, and across the
bracket the curve spans:

| thumb force | cursor speed |
|---|---|
| 25 gf | 8 – 35 px/s |
| 50 gf | 57 – 191 px/s |
| 100 gf | 289 – 876 px/s |
| 150 gf | 701 – 1200 px/s (clamp) |

The binding carries the formula to re-derive it from a measured count at 150 gf. It stays a
first-article item for two further reasons: printed arm stiffness varies with material and layer
bonding, and the sensor is spec'd to ±20 % sensitivity error, which this quadratic curve squares
into ±44 % of cursor speed.

### Also fixed

The site's "TI TMAG5273A1 Hall Sensor" hotspot was anchored to **`pcb_right__U2`** — the
MCP73831 **charger**, 13.5 mm away. The TMAG5273 is U4, and it was not even preserved as a node
in the web export. Both fixed, and the magnet is now its own explodable part.

## v0.25 — flat one-plane back, and the tray joint deleted rather than fixed (2026-08-02, branch main)

Two user calls in one pass, plus a consequence neither of them had alone.

### The faceted crown is gone (option A)

*"I appreciate everything you did to add the ergonomic 'cheeks' … but they are not working for me
aesthetically."* Five options were rendered as hillshaded relief so the choice could be made on the
shape rather than on a description; the call was **delete it**. Worth separating what was wrong: the
5.5 mm of palm fill was doing real ergonomic work, but the *language* — a cut-corner octagon, one
steep chamfer band, three scored grooves — read as a block applied to the back rather than a shape
the back has. The crown was also the sole reason the back halves printed cavity-down and therefore
needed tree supports through the cavity, and why the reset pinhole was a 7.1 mm Ø1.6 straw.

### The tray-to-grip joint is deleted, not repaired (option J3)

Measuring the joint to answer "is this the best design for strength and simplicity" turned up that
**it could not be assembled at all**:

- Both sides were **Ø3.4 M3 *clearance*** (`SCREW_HOLE_R` 1.7). No tapped hole, no heat-set bore, no
  head seat anywhere in the joint — a bolt engaged nothing. Conspicuous, because the grips' own five
  mount holes do it properly (Ø4.0 × 5.3 for an M3 insert, OD ~4.6).
- A probe straight down the bolt column at x = 83.3 meets solid grip from z = 17.7 to 5.2 — the
  cradle wall and capture retainer sit **12.5 mm** directly on top of it. No driver could reach it.

`--check` passed it every time, because **assemblability is not a collision**. Rather than fix a
joint whose whole job was to exist, the fixed tray is now unioned into `back_right`: one part,
203.75 × 103.8 × 22.2 mm. It missed the 204 mm brim-safe gate by 3.75 mm as drawn, so `OUTER_LEFT`
went −45 → **−41** and `INNER_LEN` 67 → **71** paid it back — full-open telescoping overlap is
unchanged at 13.35 mm, which is the number the enclosure assertion actually cares about.

### …and the two together broke the stance, which is why the back is now one plane

`SHROUD_ZBOT` = −4.5 was chosen as "above the −5.5 grip crown": the device rested on the two crown
plateaus with the tray hanging 1 mm clear. Delete the crown and the grips' backs are flat at z = 0,
so **the tray became the lowest thing on the device by 4.5 mm** — it would have rested on the centre
tray with both grips floating, and since J3 prints the tray as part of `back_right`, the merged part
would have needed support under ~87 cm² of cosmetic back face.

The fix is `BACK_Z = SHROUD_ZBOT`: both grips' outer backs drop to the tray floor, so the whole back
of the device is **one flat plane**. Deriving it from `SHROUD_ZBOT` rather than writing −4.5 twice
makes the coplanarity a fact of the model. The part now lies straight on the bed and prints with **no
supports at all** — the cavity, its bosses and its posts all open upward.

Consequences handled in the same pass: the back is 6.1 mm thick under the cavity there, so the reset
pinhole and the LED pipe get a Ø3.2 counterbore from the back and keep only their last 1.6 mm narrow
(otherwise the crown's 7 mm straw would have come straight back).

### The outside edges the hands wrap get a 1.2 mm quarter-round

`EDGE_R` = 1.2 on the back plane's outer edge and on the grip lids' keyboard-face outer edge —
*"just a slight rounding … around the outside of the device where human hands will touch
frequently."* Built as six ~0.2 mm bands of inset profile rather than a CadQuery `.fillet()`: these
boundaries are 200 mm long with dozens of segments, an OCC fillet on them is slow and fragile, and at
one band per layer the printed result is identical. Each band overhangs the last by one layer, so it
prints with no support. The lid's round is built from the **unclipped** footprint on purpose — near
the seam that profile sits 2.9 mm inboard and gets clipped away, so the reveal keeps its crisp 0.5 mm
chamfer and only the outer perimeter is rounded. Nothing moves: the nearest screw hole edge is 5.4 mm
inboard of the outer boundary and its countersink cone stops 2.3 mm short of the round.

## v0.25 — the nav cluster becomes one integrated D-pad (2026-08-01, branch main)

User request, with the Rii i8+ nav cluster circled as the reference: *"adjust the 5
circles directional pad to instead be a traditional integrated d pad like in the rii.
The idea is for it to be a circle with some sort of ridges internally or in the back to
enable the clicks to be cleanly discrete between up down left right and center. I think
this can be a change to the keymat and shell only."*

It can, and it is. The left grip's nav cluster was five scattered Ø6.2 buttons on 8.5 mm
centres poking through five Ø7.8 holes. It is now **one Ø24 pad** — four arm sectors
around a Ø9 centre OK, split by 2.0 mm relief moats — standing in a **single Ø24.4 lid
aperture** with a 0.6 mm dished lip. `deck.py` still emits the same five `NAV_*` dome
features at the same coordinates, so **the board, the matrix, the routing and the ZMK
keymap are byte-for-byte untouched**; the whole change lives in `deck3d.py`'s keymat and
grip-lid builders (`_dpad_zone` / `_dpad_plan`).

### Discreteness is bought with geometry, not with rigidity

A faithful one-piece rocker — a rigid cross on a centre pivot, rocking to press one dome
at a time — is the obvious answer and the wrong one here. It needs a stiff cap, and the
keymat is **TPU 95A** (E ≈ 30 MPa, ~80× softer than the PETG shells): a 24 mm TPU disc
does not transmit a corner press to a pivot, it just squashes locally. Worse, a centre
pivot has nowhere to react against except the **OK dome**, so every direction press would
land force on OK. Rocking was rejected; four cheaper pieces of geometry do the job:

- **Moats** (keymat). Each of the five actuators is its own column all the way down to
  the 0.8 mm web, so no cap material links neighbours at all. This is the primary
  isolator and it is *geometric*, not stiffness-dependent — which is why cross-talk
  becomes a web problem instead of a cap problem.
- **Moat relief** (keymat) — *the part that is easy to miss.* A moat on its own isolates
  nothing: the caps stop but the web runs straight on underneath at full thickness, and
  over a short span that web is **stiff**, because a thin-strip coupling goes as
  `t³/L³`. The first cut of this design used a 1.0 mm moat over the unmodified 0.8 mm
  web — **3.4× stiffer** than the 1.5 mm of web that separates two ordinary keycaps, i.e.
  a pad that would have pressed its neighbours along with the key you meant. The moat is
  now 2.0 mm wide and the web beneath it is thinned to **0.4 mm** (two 0.2 layers), which
  lands **~19× looser** than that key pair. `_dpad_zone` asserts that ratio rather than trusting a
  number: the absolute stiffness of a printed TPU membrane is not something this model
  can honestly predict, but "no stiffer than the geometry we already assume works" is a
  bar it can hold.
- **Clamp ring** (grip lid). The perimeter clamp rim only pins the web where the field's
  edge happens to run, and the pad sits well inboard of it. A closed annular downstand at
  **r 13.0 → 14.5** pins the web all the way round the pad, so a sector reacts against a
  clamped boundary instead of lifting the web its neighbours stand on. Its 1.0 mm standoff
  from the pad edge leaves each arm a short full-thickness hinge — soft enough to rock
  (≈ 32 N·mm/rad, an order more travel than the 0.4 mm a dome wants) but short enough to
  locate the arm.
- **Back rib** (keymat). The matching annulus on the web's underside, reaching to 0.2 mm
  above the PCB face, so the pinned ring cannot simply sink instead of clamping. It is a
  **backstop, not a preload** — 0.2 mm of rest clearance keeps it off `collide()`'s
  keymat-vs-board pair, which is not a mating one.

r 13.0 is not arbitrary: the arm domes are Ø7 discs centred at r 8.5, so their edges
reach r 12.0. `_dpad_zone` asserts the band starts ≥ 0.5 mm outside that, or the back rib
would come down on a dome's edge. It also asserts the pad covers its domes, that the OK
button plus moat leaves an arm sector to press, that the pad's web does not swallow
`MB_L`/`MB_R`, and that the web disc stays 1.0 mm inside the grip cavity — because
growing the upper zone to fit a bigger pad *is* a board change, and it should fail loudly
rather than quietly re-derive `board_h`.

### Notes

- The moats read as the seams of a moulded D-pad rather than as five gaps, which is the
  Rii/GBC look. A seamless top skin over hidden rear moats was considered and dropped for
  the same `t³/L³` reason the relief exists: a skin thin enough to fold over a 2 mm moat
  is ~0.4 mm, and bridging 0.4 mm of soft TPU across an enclosed slot is a print gamble
  where an open moat is not.
- The pad's outer edge and the OK button's each get a 45° break (0.5 / 0.4 mm) so the
  flat-topped extrusion the other caps use still reads as a moulded control, and the lid
  aperture gets a 0.6 mm 45° dish so the pad sits *in* the face rather than standing in a
  punched hole. Every one of those cones is based *outside* the wall it chamfers — a cone
  based exactly on the wall is a coincident-face boolean, and OCC returns a
  **non-watertight** shell for it (caught by `--all`, which prints watertightness).
- The NAV arrows grow 3.2 → 4.6 mm now that each has a whole sector, and `OK` is sized to
  the Ø9 button instead of the old Ø6.2 one. `_dpad_plan` asserts each Ø2.8 actuator nub
  still lands fully under its own cap — with the moat at 2.0 mm the arms start at r 6.5
  and the nubs at r 8.5 keep 0.6 mm of margin.
- `deck.Config.dpad_d` owns the diameter so `layout_gen.py` (which draws the pad as a
  dashed footprint *under* its five domes — the board really does still have five
  switches) and `deck3d.py` cannot drift apart.

## v0.24e — the capture lip actually captures (2026-07-30, branch main)

User review of the assembled GLB: *"the lips of the grippers are submerged within the
phone body… are they actually large enough to hold a phone with the gripster fully
inverted?"* and *"is the grip strength really enough or do we need a small shelf?
Phones dropping out is a dealbreaker."* Both were right, and the arithmetic is worse
than the observation. **v0.24d had no working capture lip at all** — retention was
friction, and friction does not have the margin.

### The lip was measured off two planes that don't exist

- **Underside.** It sat at `FACE_Z - LIP_T` = 13.1. A nominal cased phone's front face
  is at `RECESS_TOP + PHONE_TC` = **14.5**. The lip was modelled **1.4 mm inside the
  phone body**, so only its top 0.2 mm was ever above the screen.
- **Overhang.** `CRADLE_LIP` = 2.8 was measured from the *nominal* phone-edge plane
  (x = ±82.6). But the pad (1.6) and its teeth (0.8) stand 2.4 mm proud of that plane,
  so the clamped phone's edge rests on the **tooth crest** at 80.2, against a lip inner
  edge at 79.8 — **0.40 mm** of real overhang.
- Review then found the 0.4 was itself optimistic: `LIP_CHAM` = 0.8 sits on the lip's
  *top inboard* edge, which is precisely the sliver above the phone, so net capture over
  the front face was **≈ −0.2 mm — a clearance gap**. And because the lip's inner edge
  was 0.4 mm *inboard of the tooth crest*, the soft lip, not the teeth, was the clamp
  contact: **the v0.24d teeth were dead geometry.**

Fixed by referencing surfaces that physically exist: `PHONE_FACE_Z` for the underside,
and `lip_depth() = GRIP_PAD_T + TOOTH_R + LIP_OVER` so `LIP_OVER` is overhang past what
the phone actually touches. `--check` asserts both.

### The lip stays TPU. A rigid hook was tried and rejected.

An adversarial review refuted the all-TPU lip — it passes its bending check comfortably
(b = 60, TPU 95A at a pessimistic E = 20 MPa → 0.47 mm tip deflection at 10 g, 16 % of
the overhang) but review raised four modes bending never captures: **gripper pull-off**
(`gripper()` is a plain L-section with no dovetail, undercut or screw, so the whole
retention chain hung off a friction joint), **creep** under a deck stored face-down,
**temperature** (TPU 95A loses 35–45 % of its modulus at 50 °C, 60–70 % at 70 °C), and
**asymmetric load** (the phone rotates about one edge, so one lip takes all of it).

So a rigid PETG hook over the phone was built — and then **rejected on user review, which
was right**, for a reason none of the four reviewers raised:

> **A rigid hook at a fixed z can only capture a phone whose cased thickness is ≤ nominal.**
> The lip's underside is `PHONE_FACE_Z`, a 9.4 mm cased phone. A thicker case puts the
> phone's front face *above* that plane, so its edge butts into the lip's z band and the
> jaw cannot close. The lip degenerates into a side pad and the capture is silently gone.

TPU fails gracefully in that case — it deforms, rides up, still part-captures — where
PETG fails hard. And printed PETG layer lines on cover glass are a scratch source; TPU
spreads the contact. Stiffness and thickness-compliance are the *same* direction (+z),
so a lip cannot provide both: **the compliance has to be TPU, and the lip is the only
place it can live** without moving the phone's back datum.

What survives from the rigid version is the part that never touched the phone: a
**`_gripper_retainer`** caps the TPU lip's **root** so the gripper cannot peel off, and
stops `RETAIN_CLR` = 0.4 mm **outboard of the clamped phone edge** — so no rigid material
is ever over the screen, and the 3.4 mm of lip inboard of it stays free to flex, which is
exactly where a thick case needs give. Pull-off is solved; compliance and screen safety
are kept. The lip's top inboard edge carries the lead-in chamfer; its **underside stays
dead flat**, because a chamfer there would turn the phone's weight into a jaw-spreading
wedge.

**Known limitation, stated rather than hidden:** thickness compliance is only what the
TPU lip can flex. Cases meaningfully thicker than nominal still lose capture. The real
fix is a compliant pad *behind* the phone so the screen plane stays put regardless of
case thickness — but that drops the tray floor and cascades into `SHROUD_ZTOP`, the
v0.24d lane plan, the MagSafe recess and the v0.23 back crown, so it is not taken here.

### Insertion: the mechanism couldn't fit its own largest phone

Travel was exactly 130–170 — *identical* to the phone range — so at 170 there was zero
opening left. With a real lip that is fatal. Rotating the phone in doesn't help: its
xz diagonal (170.3) is longer than its length, and the well is exactly `PHONE_TC` deep.
The only path is seat-one-edge-then-translate, which needs

    clamp_pos ≥ P + lip_depth() + (GRIP_PAD_T + TOOTH_R) = P + 7.8

not the "one lip overhang" (3.0) first assumed. `clamp_insert_clr` = **9.0**, so the jaw
opens to **179**. Every mm of opening costs a mm of telescoping overlap, so `INNER_LEN`
goes **62 → 67** to keep the enclosure sealed: overlap at *full open* is 13.35 mm,
still over the ≥ 12 assertion. `--check` now runs a fourth **"open"** state, because the
widest the jaw goes — not the biggest phone — is the real worst case.

### Grip strength: the math, and why the shelf is justified

Statics: the springs pull the moving jaw with total `F_s`; that force passes through the
phone, so the normal force at **each** of the two grippers is `F_s` (not `F_s/2`).
Holding force = `2·μ·F_s`.

| `F_s` | μ | hold | slips at (0.30 kg phone) |
|---|---|---|---|
| 10 N | 0.6 (molded-TPU optimism) | 12.0 N | **4.1 g** |
| 10 N | 0.40 (glazed, oily, dusty) | 8.0 N | **2.7 g** |
| 10 N | 0.25 (printed ridges on a glossy PC case) | 5.0 N | **1.7 g** |
| 20 N | 0.6 | 24.0 N | 8.2 g |

Printed TPU is not molded TPU — layer ridges mean the pad contacts a smooth case only on
ridge crests, and elastomer friction is adhesion-dominated, so **μ ≈ 0.25–0.45 is the
defensible design range, not 0.6**. Review also derates `N` itself: the spring pulls at
`LANE_Z` = 0.2 while the phone contact acts at pad mid-height ≈ 9.9, and that ~9.7 mm
offset is a permanent racking couple reacted as slide friction in the shroud — roughly
`N ≈ 0.7·F_s`. Net: **the phone slips at 2–3 g**, which is ordinary handling.

Held normally, gravity acts along **−y**, and nothing was under the phone's bottom long
edge — the tray sits *behind* it (z), not *below* it (y). So that load rode entirely on
the one path that decays. **`SHELF_H` = 3 mm upstand** along the tray top's low-y edge
plus a tab on each grip's cradle turns it into bearing (contact stress 0.05 MPa —
nothing). It blocks only −y, so the phone still drops straight in and lifts straight
out. Honest caveats: it does nothing for the device held **upside down** (+y), where
friction still rules; and it can't live on the moving inner shroud, whose front wall is
inset to y ≥ 8.75, *inside* the phone's 8.5 footprint — so at long spans ~40 mm of the
phone's bottom edge overhangs the tray shelf and is carried by the cradle tabs.

Worth recording: **no commercial controller has a bottom shelf** — Backbone, Kishi,
GameSir and the Abxylute all leave both long edges clear. They can, because molded
liners and higher clamp force give them the friction we don't have.

### Springs: the anchor moves, and the spring type is still wrong

`SPRING_ANCHOR_X` **22 → 76**. At 22 the installed length ran 7.85 → 47.85 mm — 510 %
extension, which no coil spring survives — and because an extension spring is weakest
when least stretched, the **smallest phones would have got the weakest clamp**. At 76 it
runs 61.85 → 105.85 mm, a **1.71:1** length ratio instead of 6.1:1.

That makes the spring *buildable*, not *right*. Review closed the loop on the numbers:
a Ø4 / 0.5 mm music-wire spring at C = 7 caps initial tension at **F0 ≈ 1.85 N/spring,
not the 3 N assumed** — τ_i would need ~259 MPa against a ~160 MPa limit — so min-span
clamp lands near 5.8 N total, not 8.1. And the spring is **fatigue-limited** (τ ≈
870–930 MPa against an ~843 MPa cyclic allowable, cycling on every insertion), while a
**hooked extension spring's failure mode is total release**. None of Backbone, Kishi,
GameSir or Abxylute uses hooked extension springs: they use **compression springs
captive in the telescoping bridge**, or a **constant-force spiral**. That is a component
choice for the user to make, so it is flagged, not silently changed.

**Also flagged, not fixed:** the assembly GLB used to seat the phone by its *camera-bump
tip* on the recess floor (a v0.18 rigid-well leftover), which put its screen 0.82 mm
above `PHONE_FACE_Z` and is why the lip still rendered buried. It now seats by the
**screen**, so the GLB and the fit model agree — and that makes visible a real
interference the old datum was hiding: a bare S25U's camera bump stands ~2.0 mm proud of
its back while a 1.2 mm case covers only 1.2 of it, so **a flat full-width tray cannot
accept a phone whose bump exceeds its case thickness**. Either the tray needs a bump
relief or it needs to narrow toward the Kishi/Backbone rail form.

## v0.24d — enclosure lane plan + gripper teeth (2026-07-28, branch feature/expanding-clamp)

User review of the v0.24c clamp found three faults. All three were real, and the first
two were the *same* fault: v0.24c placed the enclosure's contents by eye, one at a time,
instead of to a plan.

- **Everything inside the enclosure now runs in its own y LANE, on one shared z.**
  Front → back the tray reads `spring | FFC | power | spring`, every lane on `LANE_Z`
  (the mid-height of the *moving* shroud's cavity). Nothing is stacked over anything.
  - *Why it was broken:* v0.24c ran the FFC at y=24 directly under spring 0 (also y=24),
    z bands overlapping — the coil sat on the ribbon, and the ribbon's service loop had
    nowhere to crumple at short spans that wasn't a spring. The user called this out
    before it ever got printed.
  - *The fix is a lane plan, not a nudge.* The springs move OUT to the enclosure's y
    extremes (13.5 / 83.5); the FFC keeps **J2's y centre (24.5)** so the 16-way ribbon
    still enters the ZIF dead straight rather than being doglegged to make room; the
    power cable keeps its own row at 40. Pushing the springs outboard is a second win:
    a wider stance resists jaw racking.
    > **⚠ Superseded by v0.27, and the "J2's y centre" claim in this bullet was already
    > wrong when written.** The lane was 26.5 against a connector at 24.5 — a 2.0 mm
    > skew that put the ribbon's first conductor outside the housing. 26.5 was the
    > lane-plan minimum the spring-rib assert would accept, not J2's y. v0.27 moves
    > both to **28.5** (21 mm ribbon, 20-way), deletes the power lane and its cable
    > entirely (`spring | FFC | spring`), and makes `check_lanes()` assert the lane
    > against the KiCad placement export so the two cannot drift apart again.
  - **Printed divider RIBS** wall each cable into a channel, in *both* telescoping
    members, so a loose loop has no path into a spring lane at any extension. The tray's
    ribs can only live right of the moving shroud's end at the *shortest* span — that is
    still the majority of the run, and exactly the stretch that was open cavity before.
- **The cables were exposed out the back at full extension — root cause was a z, not a
  gap.** v0.24c pinned both cables to the FIXED tray's floor. The MOVING shroud's floor
  sits 1.4 mm *above* that, so across the span only the moving shroud covers (longest at
  full extension) the cables hung in open air behind the device — the power cable's
  envelope reaching 0.95 mm below the shroud's underside. Putting every lane on `LANE_Z`
  *inside the moving shroud's cavity* makes enclosure hold **by construction** at every
  extension, instead of depending on the fixed tray still happening to be underneath.
  Two consequential fixes came with it: the shroud's left end wall now has real cable
  **pass-throughs** (v0.24c modelled the ribbon straight through 1.4 mm of PETG), and the
  tray's right end wall has **one window per lane** (v0.24c cut a single window at
  y 15–33, which the power lane at y=40 missed entirely).
- **The TPU grippers get TEETH** (the GameSir / Abxylute detail v0.24c skipped). 13
  half-round ribs at 3.4 mm pitch, axis along the phone's thickness, 0.8 mm proud of the
  pad face. A flat pad resisted the phone creeping or rotating in y by friction alone;
  the teeth bite the cased edge, which is what actually keeps the screen square to the
  keyboard face. Rolling them out of cylinders centred *on* the pad face leaves exactly
  half proud — the shape that bites and the shape TPU prints without support. The
  capture lip also gains a **lead-in chamfer** on its top inboard edge so the phone snaps
  past it instead of having to be threaded in square.
- **Both `--check` guards that should have caught this were themselves wrong** — worth
  recording, because the geometry bugs were only survivable *because* the guards passed.
  - `cable_enclosure` ray-cast from the cable's **centre line**, so a cable sunk inside a
    shroud wall reported "SEALED": every ray promptly hit the wall it was embedded in. It
    now runs two tests — a **solid** test (the clipped run may not intersect the tray at
    all; a cable inside a wall is impossible, not "contact") and rays cast from just
    outside the cable's **envelope**. Fed the v0.24c lanes it fails 2 / 9 / 10 samples at
    min / nominal / max span, `power … open: down` — precisely the reported symptom, and
    worst at full extension, as reported.
  - `_allowed` whitelisted **"spring vs anything"** as intended mating, which is how a
    coil resting on the FFC never showed up as a clash. A spring may now only touch its
    own anchors (`bridge`, `back_left`). Likewise the cables no longer get a free pass
    against `bridge`: inside the tray they run in a walled channel with real clearance,
    so any overlap there means buried-in-a-wall.
  - `--check` now also asserts the **lane plan** numerically (each cable between the two
    springs, ≥2 mm clear of both, channels far enough apart to wall off, lane axis inside
    the moving shroud's cavity) — pure arithmetic, so a lane regression fails in
    milliseconds instead of after a four-minute build.

**Known, not fixed here:** the spring stroke is aggressive. With the anchor at x=22 the
installed length runs ~7.9 mm at min span to ~48 mm at max — a >5:1 working ratio no coil
extension spring will survive. Moving the anchor toward the tray's right wall converts
that to a far saner ratio on the same 40 mm travel. Left alone deliberately: it is a
spring-selection question the user has not weighed in on, and it does not interact with
the lane plan.

## v0.24 — expanding spring-clamp back (2026-07-26, branch feature/expanding-clamp)

User request: make the back **expand and collapse like a Razer Kishi 2 / Backbone** so
it clasps different-size phones with a spring — a drastic rework of the rigid center.
Chosen after four decisions: **printed dual-rail slide** (no metal rods), **2 extension
springs**, **preserve near-flush at the nominal phone**, phone long-edge range
**130–170 mm**.

**FINAL landing: 2-part tray (the geared 3-stage below was built, then simplified away).**

- **The rigid center is gone.** Deleted the bolted `center_panel`, the sunken
  flush-screen well, the x=0 back seam + tabs/shiplap, the panel screws, and the central
  spine slab. The two grips are now separate bodies joined by the telescoping tray. A
  deliberate reversal of the v0.8/v0.18 fixed-flush calls — the user wants multi-phone
  fit over a single-phone flush mount.
- **2-part telescoping TRAY (final).** After building the geared 3-stage (below), the
  user flagged it as over-complex and pointed to the Abxylute S9 / 8BitDo single-joint
  trays. Reframe that settled it: **our travel is only ~40 mm (1.3:1)**, and the geared
  telescope's whole value is holding overlap over *large* travel — for 40 mm a single
  lap keeps huge overlap throughout, so the gear solved a problem we don't have. The
  tray (`bridge` = fixed tray + the left grip's lapping plate) is simpler, sturdier in
  practice (the clamped phone is the stiffener), far easier to tune, and its continuous
  flat top hosts the MagSafe ring + leaves back-space for maker alt-shells (the user's
  hackability goal). Kept: the enclosure (lapping plates), springs, power cable, rounded
  section. *(⚠ v0.27: the power cable is deleted — the cell crosses on the bridge ribbon.)* Dropped: the pinion, both racks, the separate centre stage, the twin channels.
- **Face-down retention is MECHANICAL, not magnetic.** Requirement: usable screen-down
  over your face (Switch/Steam-Deck). Magnets shear/peel — unsafe over a face — so the
  phone is trapped between the tray (behind) and **deep soft lips** (front); gravity just
  presses it into the lips. The lips + a compliant edge grip are one **TPU gripper** per
  grip (`gripper_left/right`, GameSir-style, prints with the keymats). Lip depth + clamp
  force are the coupon tune.
- **MagSafe is back — as a SECONDARY convenience.** A strong **N52 ring** (mount side,
  not a passive steel plate — the user correctly noted the phone/case magnet is the weak
  one) seats in a recess at the tray centre (`magsafe_ring`), for back-flat + snap only.
  Because it isn't load-bearing, its alignment drift across phone sizes/cases (the thing
  that killed a fixed ring on the old rigid mount) stops mattering; makers can reposition
  or float it. Opt-in: Android (incl. our S25U) needs a magnetic case/stick-on ring;
  iPhone gets it free; the clamp holds the phone either way.
- **THREE-STAGE GEARED brace (feedback: match the Kishi's geared telescope; make it
  sturdy for print/mould).** `deck.product()` is parametric on `clamp_pos`; the right
  grip is the frame reference and the left is the moving jaw. The brace is a 3-section
  slide: a **centre stage** (`bridge`) telescoping inside a **channel on each grip**,
  with a **pinion** (`pinion`) meshing a **fixed rack** (right grip) and a **moving
  rack** (left grip). This enforces a **2:1** — `_center_x()` places the centre at the
  midpoint = the phone centreline at every span. *Why geared, not free-sliding:* a
  telescope's stiffness is its overlap; free stages hand off (one runs to its stop,
  then the other), leaving the worst-case one-joint-does-all at intermediate spans. The
  2:1 keeps **both joints half-engaged everywhere**, maximising rigidity, killing
  racking, halving per-joint travel/wear, and keeping the pad behind the phone. Three
  stages (not two) also buy the collapsed→extended range without a bigger closed unit.
  It evolved from a 2-stage nested shroud (this same iteration) once the geared
  reference was specified.
- **Sturdy section (per the brief).** Every stage is a solid bar with a **flat
  phone-side top + a rounded-bevel back** (`_rbar`) — a deep, stress-concentration-free
  section for bending/torsion, comfortable in hand, and consonant with the v0.23 crown.
  The clamp **springs**, the **FFC**, and the **power cable** run enclosed in the nested
  stages' cavity on y-lanes clear of the gear/racks.
- **The missing power cable, added + enclosed.** The battery leads (left-grip 403040 →
  J3 on the right board) were never modeled; they're now a `power_body` routed enclosed
  through the shrouds in its own y/z lane beside the FFC, each with a rolling service
  loop. Collision shows both cables as intended contacts with the shrouds (threaded
  through, inside the cavity), not clashes.
  > **⚠ Deleted in v0.27.** The cable, its lane and J3 are all gone: the cell crosses on
  > four conductors of a 20-way bridge ribbon and plugs into **J4 on the LEFT board**,
  > ~8 mm from where it sits. `power_body` no longer exists.
- **Packing conflicts solved during collision bring-up** (validated at min/nominal/max):
  the left grip's mount screws had to be shifted with the moving jaw (they were pinned
  at nominal); the recess floor was shortened to x −60 so it clears the **collapsed
  grip's battery** (the phone is edge-clamped, so it only needs central + cradle-edge
  support, not full-back support); the cradle walls were pulled 0.9 mm shy of J2's
  courtyard; and the bolt column was moved off J2's y-band. `--check` asserts the
  shrouds stay overlapped (≥12 mm) so the enclosure can't open at full extension.
- **Retention & near-flush trade-offs (accepted).** X = spring clamp on the short
  edges via TPU-padded cradles; Z = screen-edge lips + the recess; Y = bridge walls.
  Near-flush holds exactly only at the nominal cased thickness (9.4 mm) — thinner
  phones sit slightly low, thicker slightly proud — and the smallest phones are
  right-justified (right edge pinned) rather than centred.
- **Electrical / battery.** Both cross-grip cables — the 16-way FFC (matrix) and the
  battery power leads — now need a **rolling service loop** (fold inside the shroud;
  FFC grows to ≈240 mm) because the span is variable. The 403040 battery stays in the
  left grip and rides the moving jaw. No PCB changes — this is shell-only; the boards
  remain v0.22 rev-A.
  > **⚠ Superseded by v0.27.** There is only **one** cross-grip cable now: a **20-way**
  > FFC carrying the matrix *and* the cell. ≥240 mm and the rolling service loop still
  > stand — quoted for 20-way stock, **TYPE-A only**. This did become a PCB change: J2
  > is a 20-position ZIF at deck y 28.5, the right board loses J3, and the left board
  > gains J4 + F1.

## v0.23 — faceted ergonomic back crown (2026-07-26, branch feature/back-ergonomics)

User feedback: "the design is great but flat — use more sophisticated geometry for
better ergonomics, especially the back contours; take inspiration from the Rii 8+
back and 90s electronics." The back was a dead-flat extruded tray (outer face a
single z=0 plane), so the device pressed a flat slab into the palm.

- **A faceted palm crown, added BELOW z=0.** Two cut-corner **grip plateaus** rise
  **5.5 mm** below the back plane (apex biased to the outer edge where the thenar
  heel and curled fingers bear), each scored with three **shadow-line grip
  grooves**; a lower faceted **spine panel** (−2.2 mm) laps into both so the whole
  back reads as one milled 90s-industrial block (Sega/Nokia cut-block facets, crisp
  panel lines), tapering to a thin land at the perimeter. Generated with CadQuery
  **ruled lofts** of cut-corner octagon sections — planar-facet B-rep, exact and
  STEP-clean, the right tool for the *faceted* (not smooth-organic) look the user
  chose. scipy thin-plate-RBF + scikit-image marching-cubes were installed for a
  future SDF/organic pass but are unused here by design.
- **Why additive-below-z=0 is the whole trick.** The crown never enters the
  electronics cavity (everything at z ≥ FLOOR), so the validated PCB fit, the
  221-body collision result (still **0 clashes**), the joinery and the bed-fit are
  unchanged by construction — the change is provably local to the cosmetic back.
  The reset pinhole + charge-LED holes are the only cavity features it touches, and
  they are just lengthened to pierce the crown to daylight.
- **Print orientation flips floor-down → CAVITY-DOWN** (the one real cost). A
  convex crown can't print floor-down (a convex-down face droops near its apex), so
  the halves now print cavity-opening-down: the crown prints **apex-up as a
  strictly-narrowing faceted peak** — self-supporting at any facet angle, clean
  cosmetic face. The internal PCB bosses/posts become the only downward faces and
  take **tree supports inside the cavity**, where the scars are hidden (the user
  explicitly chose "cavity-down with supports so the support scars are internal"
  over a bolt-on cover or an outer-face-down print with visible palm-side scars).
- **Thickness.** Device stays 14.7 mm at the flush front plane and ~15.7 mm at the
  thin edges; the grips swell to ~20 mm back-to-face (~24.8 mm incl. keycaps) —
  the Rii-8+ hand-filling target. The PCB is unchanged from v0.22 rev-A (the crown
  is shell-only; boards were not re-fabbed, so their silkscreen still reads v0.22).

## v0.22 — true-mirror page keys + genuine-TrackPoint-cap mount (2026-07-24, branch feature/right-joystick)

Two user-feedback items on the v0.21 print/renders.

- **PgUp/PgDn move to the TRUE mouse-button mirror x = 57.25** (the F10|DEL
  gap, mirroring the left pair's ESC|F1 gap; y unchanged at cy_lo ± 5.5). The
  user caught them sitting "above F9" (x 45.7). v0.21 had dodged 57.25 with
  the note "the true mirror is ON the E73 body" — which conflated the two
  board FACES: domes are front-side copper, the module is a back-side part,
  and they coexist at the same x/y. What actually needed care: (1) BOTH
  feature diodes — PGUP's default spot (deck 57.25, 87.5) is under the module
  belly and PGDN's (57.25, 76.5) is on the TP1-5 SWD row (y 75.7), so they
  drop to deck (52.5, 73.2) and (57.25, 73.2), just under the TP row; (2)
  SW91 moved (53.5, 71.5) → (46.0, 80.5) — the vacated old-PGUP zone; its
  first two candidates hit TP6/TP7 and the R-row (the reset's 7.6×5.7
  courtyard fits no gap in the crowded y 66–77 band); (3) the
  module's south-castellation escape vias must clear the PGUP dome's r3.6
  all-layer via keep-out — the autorouter re-fans them (tracks stay legal
  through the keep-out; only vias are banned). The dome courtyard clears the
  antenna keep-out band (module-top 5.5 mm) by ~4 mm.
- **The nub mount becomes GENUINE-TrackPoint-cap compatible.** v0.21's Ø5
  round spigot + smooth-top printed dish cap (TPU, but no dot texture — a
  slick surface that wears with no replacement path but a reprint); the user
  asked for the classic cap look ("people who love the nub
  will respond to it visually"). The spring's post is now the **standard
  classic TrackPoint square platform: 4.4 mm sq × 2.5** (genuine classic
  full-size caps — soft dome / soft rim / classic dome, the ones sold in
  10-packs everywhere — have a ~4.5 mm square socket ~2.5 deep; dimension
  cross-checked against the navcaps project's cap-mount sources, which print
  against genuine caps: mount side 4.5, height 2.5, classic cap adds ~5 mm
  height, and 6 mm-tall variants "tend to come off" as thumbsticks). The
  printed cap is now a **classic soft-dome replica in ThinkPad-red TPU**:
  mushroom profile (Ø7.8 flared skirt, Ø6.8 waist, Ø7.8 dotted dome, 5.25
  tall), the same 4.6 sq × 2.6 socket (corners r0.6, waist Ø6.8 — the r0.6 corner
  reaches r3.00, so a Ø6.2 waist left a 0.10 mm unprintable corner wall,
  caught in STL review; Ø6.8 leaves 0.40 mm ≈ one extrusion width), so
  printed and genuine caps interchange on the same post.
  Hub top drops 16.4 → **14.0** (0.7 below the face): the cap skirt nestles
  INTO the Ø10 aperture exactly like a TrackPoint between keycaps; dome top
  z 18.9 (+0.35 dot grid) ≈ 4.2 mm proud of the face. First tilt-stop is now the rubber skirt
  against the aperture wall (1.2 mm) instead of plastic-on-plastic — gentler
  on the flexure (peak arm strain drops below ~3.5%). Sensor gap, magnet,
  arms, legs and clamp are untouched; the GLB paints the cap
  `trackpoint_red`.
  > **⚠ Superseded by v0.26 — the tilt-stop claim in this paragraph is wrong.** Reaching
  > the aperture wall takes ~20 N of thumb force, so it is not a stop at all, and the
  > "<3.5 % peak arm strain" criterion is past PETG's ~2.5 % yield strain anyway. v0.26
  > re-derived the flexure against the TrackPoint IV spec and **kept the 0.8 mm arms** (they
  > were already in the target band), but added a root fillet and a 0.35 mm plunge stop, so
  > "arms, legs and clamp are untouched" no longer holds. Neither does "sensor gap ...
  > untouched": the gap was never 2.6 mm — that measured to the package, not the die.

## v0.21 — right-grip pointing nub: Bean-style TMAG5273 hall sensor (2026-07-23, branch feature/right-joystick)

The right top zone becomes a mirror of the left cluster, with a real pointing
device where the D-pad mirror lands. Final architecture: a **ThinkPad-style
rate-control nub** built the way the
[Ploopy Bean pointing stick](https://github.com/ploopyco/bean-pointing-stick/)
does it (hardware CERN-OHL-S v2 — credit where due; our sensor placement,
flexure, and driver are original implementations of the same architecture):
a **TI TMAG5273A1 I²C 3-axis hall sensor** (SOT-23-6, LCSC **C3716049**,
~$0.60, basic SMT — machine-placed like everything else) under the board, a
**Ø4×2 mm N52 disc magnet** press-fit into a **3D-printed flexure spring**
above the lid, and a printed friction cap. Deflecting the nub tilts/shifts the
magnet; the sensor reads the X/Y field **through the 1.6 mm FR4**; firmware
maps deflection to cursor **velocity** (quadratic curve + deadzone + remainder
accumulation) — steeper tilt = faster cursor, exactly the trackpoint behavior
the user asked for, with zero moving parts on the PCB.

- **The ALPS detour, recorded honestly**: the first implementation used an
  ALPS RKJXV1224005 analog gimbal stick (THT, JLC hand-solder). It worked
  electrically (routed 0/0) but the 11.2 mm module body stood proud of the
  face with a housing built around it — the user expected "the stick pokes
  out, not the module," and a Switch-style flush face is geometrically
  impossible with any COTS gimbal in a 5.2 mm under-lid cavity: the module
  that fits doesn't exist at JLC, and the module JLC has doesn't fit. The
  hall-nub architecture inverts the problem: the tall part (spring + cap) is
  a printed part *outside* the shell; the electronic part is a 1 mm SMT chip
  *inside* it. It also restores the all-SMT, no-hand-solder fab story and
  drops the moving-part count on the board to zero.
- **Placement**: sensor U4 at (32.3, 79.0) right-grip-local — the **exact**
  left-D-pad mirror (32.3 mm from the inner edge on both grips, same y — the
  ALPS variant's 2 mm terminal-row offset died with the ALPS). Back
  side, under the lid's Ø10 nub aperture. PgUp/PgDn are the mouse-button
  pair's mirror: same y-heights (cy_lo ± 5.5), same 11 mm spacing, at
  x = 45.7 — the true MB mirror x (57.25) is ON the E73 body; the right
  outer-top has belonged to the antenna since v0.17, so the pair sits between
  nub and radio.
- **Electrical**: the rev-B "trackpad breakout" pads finally do their job —
  **SDA = TP6 (P0.05), SCL = TP7 (P0.28), INT = TP8 (P0.29)**, TWIM0 at
  400 kHz, addr 0x35. Adds only R26/R27 (4k7 pullups) and C8 (100 nF bypass).
  No new MCU pins, no analog domain, no SAADC conflict with the battery
  divider (the ALPS plan's open risk), and deep-sleep drain is the sensor's
  sleep current instead of 660 µA of pot bias.
- **Board knock-ons**: TP6-8 relocate to deck y 67.5 (PgDn's diode landed on
  the old row); C7 beside the USB-C; SW91 reset to deck (53.5, 71.5); the
  deterministic In2 USB lanes get a reworked D+ elbow (rev-A 24.0 → 33.0) and
  a dedicated D− resurface column — the v0.17 columns are inside the new
  PGUP dome ring. Board is back to **all-SMT, 36 right keys, 78 total**; the
  ALPS footprint file is deleted.
- **Firmware**: new in-tree Zephyr module **`firmware/zmk-modules/tmag5273_nub`**
  (Apache-2.0, register map from the upstream Zephyr tmag5273 sensor driver +
  TI datasheet — NOT derived from the Bean's GPLv3 QMK firmware): polls X/Y at
  100 Hz, boot-averages the magnetic zero (which also swallows the MagSafe
  ring's static field), then quadratic rate-control → `input_report_rel`
  into a `zmk,input-listener`. Deadzone/gain/max-speed/axis-flips are DT
  properties — first-article tuning without touching C. A `pm_device` hook +
  `CONFIG_PM_DEVICE` puts the sensor into its ~nA sleep mode when ZMK deep
  sleep fires (continuous mode free-runs at ~2.3 mA on the always-up REG0
  rail — enough to kill the cell in a week of "sleep"; caught in review) and
  re-zeros on resume. Matrix stays 78 keys; west.yml carries no third-party
  modules.
- **Shell/CAD**: right lid gets a plain **Ø10 aperture** (no collar, no pod —
  the face stays flat like a ThinkPad keyboard) with an underside counterbore
  over a printed **nub_spring** (Ø14.8 flange + 3 spiral flexure arms + Ø7 hub;
  the magnet pocket is a press-fit, N-up). The spring is **clamped, not
  floating**: 3 legs on the flange underside bear on the PCB front face and
  the counterbore ceiling presses the flange onto them with 0.05 mm preload
  when the lid screws go home (the adversarial fit review caught the first cut
  leaving the flange 0.9 mm free to drop). A **nub_cap** (Ø8.5 TPU friction
  dome, 4.25 mm proud of the face) press-fits 0.95 mm onto the hub's Ø5
  spigot — cap and spring are prints 8 and 9. Spring compliance is a
  print-tune parameter (arm thickness 0.8); both parts verified watertight.

## v0.20 — mirrored modifiers: Ctrl/Shift/Alt on both grips (2026-07-22)

The 147 mm phone gap means a thumb can never reach the opposite grip, so any
modifier+same-side-key chord needs that modifier on BOTH grips — with left-only
Ctrl, the entire core shortcut cluster (Ctrl+Z/X/C/V/A/S — all left-grip
letters) was physically impossible. The Rii i8+ itself half-acknowledges this:
it duplicates Shift at both ends of the Z-row and carries a right-side AltGr,
and its layout demotes Del to Fn+Backspace. We extend its own logic to the
split geometry. Reviewed by a 3-critic panel (thumb ergonomics, ZMK
feasibility, Rii fidelity) before landing.

- **Two right-grip caps relabel, nothing else moves**: bottom-row `AGR` → `Alt`
  (the keycode was already RALT; AltGr ≡ right Alt on US layouts) and the
  outer-corner `\` → `Ctrl`. Both grips now end in the identical mirrored
  stack — **Ctrl at the bottom-outside corner, Shift directly above it, Alt
  beside Space** (the Rii's own Alt|Space|AltGr grammar). Left grip, brackets,
  FN and WIN are untouched. Zero PCB/matrix change: `thumbdeck.dtsi`
  regenerated **byte-identical**; all 78 domes keep their positions; the JLC
  fab package stays valid.
- **Backslash demotes to the FN layer as DIRECT bindings — FN+`]` = `\`,
  FN+`[` = `|`** (same pattern as `'` on FN+`;`). Pipe deliberately does NOT go
  through Shift: Shift+FN+] would be a three-key chord no thumb-pair can hold.
  Bracket caps get debossed Rii-blue sublegends (`|` and `\`).
- **Side-aware HID codes** in `gen_firmware.py` (`KC_RIGHT`): the right grip
  emits RCTRL/RSHFT/RALT so left/right modifiers stay distinguishable and AltGr
  keeps working under intl layouts. Previously `kc()` was side-agnostic.
- **No sticky/one-shot behaviors — deliberate.** All chords are plain holds;
  the modifier is held by the thumb opposite the target key. Same-side triples
  (Ctrl+Shift+letter) use the vertical corner Ctrl+Shift one-thumb bridge or an
  occasional cross-hand reach. Known residual gaps, accepted: Win+left-side
  combos (Win+E/D, Super+1–5) and left-grip FN-layer targets (BT select) need
  the cross-hand reach — BT is setup-time, Win combos are rare on this device.
- Stale-count cleanup: `gen_firmware.py` docstring and `sim_matrix.py` banner
  said 79 keys; the matrix has been 78 since the v0.17 2u-Enter change.
  `sim_matrix.py` re-run fresh: **78 keys (right 36 + left 42), 0 cross-grip
  collisions, 0 ghost/miss failures — PASS**.

## v0.19 — Game-Boy-Color rework: boxy outline, flush M3 screws, closed well (2026-07-17)

Driven by the user's print-test feedback (5 items) with a Game Boy Color as the
design-language reference (boxy rounded silhouette, Atomic-Purple translucent
shell, dark button-gray keys).

- **Outline (item 4):** the outer **parabolic cheek bow is deleted** — printed
  testing showed the widest part of the cheek blocks thumb reach to the
  edge-adjacent keys and top corners. The outer edge is now **straight** at a
  constant `grip_margin` (7.0 → 8.5: +1 for the fatter M3 boss column, +0.5 routing
  relief — at 8.0 Freerouting left 1-3 nets open every attempt), so
  boards go **79.493 → 75.0 mm** wide; corners: r_in 4.0 / **r_out_top 8.0**
  (antenna-pinned — the E73 keep-out forbids anything rounder) / **r_out_bot
  11.0**, plus a **1.0 mm parabolic bottom crown** (the GBC's convex bottom).
  Face cheek is now a constant ~11.4 mm (was 9.9–15.9 bowed). Device face
  width 330.6 → **325.5 mm** despite the wider spine (below).
- **Mount holes → M3 (item 1):** all 14 face screws are **M3×10 DIN 965
  countersunk, heads flush** with the face (proud M2 pan heads were
  uncomfortable). PCB holes Ø2.2 → **3.4** (boards unordered — free change),
  bosses Ø6/7 → **Ø7.5/8.0** with **Ø4.0 bores** for M3 heat-set inserts;
  lid plate **TOP_T 2.0 → 2.4** so the Ø6.2 countersink cone keeps ≥1.0 mm of
  land (face plane 14.3 → **14.7**; keymat plungers +0.4 to keep caps 1.0
  proud). Hole positions re-tuned for the fatter bosses (inner column x 3.2 →
  4.2, H3 y 77.6 → 72.0, outer column at edge−4.2, H5 y 67.9 → 68.0) against a
  **raised boss gate (r 3.0 → 4.0)** in gen_board/verify_alignment — at the old
  r 3.0 a real dome-courtyard clash would have shipped. The top electronics
  cluster's placement anchor is now a **frozen absolute** (AX 72.493), not
  board_w-derived — the narrower board slid a W-anchored cluster 5 mm inboard
  onto the PGUP/PGDN dome courtyards (caught by the C5 GND-escape assert).
- **Closed phone well (item 2):** the well's x-ends were open slots into the
  grip cavities (the v0.18 gap put the phone ends exactly AT the panel edges).
  The spine gap grows `2 × (0.35 well clearance + 1.6 end wall + 0.3 reveal)`
  = span_x + 4.5 (gap 165.8 → **169.7**), and the panel's well is a full
  **picture-frame** (explicit frame rect replaces the y-only buffer band).
  FFC jumper spec ≥190 → **≥194 mm** (J2 rows now 173.3 mm apart).
- **Thumb scallop → finger dish (item 3):** the R9 scallop cut used to punch
  through into the interior. Now a **curved backer** (R10.6 half-annulus wall +
  solid floor to z 6.0, clipped to the spine cavity −0.25) is unioned before
  the R9 re-cut: watertight, support-free in the panel's slab-down print, case
  edge still exposed ~17 mm for tip-out. Scallop centre moved 2.3 mm into the
  well; the top border screws moved to |x|=13 to clear the dish + Ø8 bosses.
- **Colors (item 5):** GLB shells switch from per-face concept colors to a real
  **glTF PBR material** — "atomic_purple", baseColorFactor linear [0.198,
  0.102, 0.381, 0.55], alphaMode BLEND, doubleSided (translucent purple with
  the guts visible); keymats **dark button gray**. The matplotlib renders
  mirror both (render_iso no longer forces alpha=1).
- **Boards re-routed from scratch** (outline + all 10 hole centers moved =
  Edge.Cuts change): gen_board → route.sh both sides → DRC 0/0 gate → fab
  re-export; sim_matrix / verify_alignment / verify_geometry re-run
  (verify_geometry's hole-to-key gate raised 3.0 → 7.9 c-c to encode the M3
  boss + dome-courtyard rule).

## Rii-follow: 2u Enter at the end of the right H-row (2026-07-15)

Following the Rii i8+'s wide Enter: the right grip's H-row (4th from the top) is
now **H J K L + a double-wide 2u ENT** — 5 caps spanning the 6-unit row width,
one dome under the wide cap (same construction as the 2u space bars). The
apostrophe gave up its physical spot: **`'` is now `&kp SQT` on FN+`;`** (the FN
layer already carried -, =, Home/End, PrtSc and the mouse moves).

- Key count **79 → 78** (right grip 37 → 36: 34 grid keys + PgUp/PgDn; left
  unchanged at 42); diodes likewise 78 (right board 36, refs D1–D36).
- **PCB, keymat and shells regenerated**; the right board **rerouted — still
  0 DRC violations / 0 unconnected** (left board untouched, 0/0); fab package
  re-exported (right BOM now 67 placements). Board dims unchanged (79.5 × 97.0).
- Firmware regenerated: 78 `RC()` transform entries, keymap carries `&kp SQT`
  on FN+`;`.
- Also in this pass: the keymat model carries **debossed Rii-style keycap
  legends** (primary legend + small shifted-symbol secondaries + FN-layer
  legends on 0/9/PgUp/PgDn/Del/;), and the assembled 3D model now includes the
  **M2 shell screws**.

## v0.18 — flush-screen phone well + battery to the left grip (2026-07-14)

Goal: an **S25 Ultra in a typical thin case** sits with its **screen surface flush
with the grip lids' keyboard face** — one continuous 14.3 mm-high front plane
(lids · panel border · screen), thumbs sweeping from glass onto keys with no step.
No change to the boards (no reroute); grips untouched.

- **The math.** Keyboard face (lid top) = z 14.3. Cased S25U = 8.2 + 1.2 case back
  = **9.4 mm** back-of-case → screen. So the phone must rest at z 4.9 — a
  **10.2 mm drop** from v0.17's 15.1. The center panel becomes a **sunken tray**:
  border flange 12.3..14.3 (flush with the lids), well floor at 4.7 with the same
  Ø57×1.8 MagSafe recess / 0.8 mm web / 0.2 mm-proud ring construction as before,
  translated down. Device thickness **22.9 → 15.3 mm** (keycap tops; the flat
  face is 14.3, the case lip sits ~0.4 proud of flush glass).
- **Phone dims got real.** The model carried placeholder iPhone dims (71.6 ×
  147.6); the flush stack forced the real **S25 Ultra (162.8 × 77.6 × 8.2) +
  case_t 1.2** into `deck.Config`. Consequence: the spine gap is sized to the
  cased length (165.2 + 0.6 clearance), so the device is **324.8 mm wide
  (+18.2)** — that is the phone's own size, not packaging growth; y-footprint
  (102.8) and grips unchanged.
- **Battery relocation: REQUIRED, not optional.** Under the sunken well's floor
  slab only **0.5 mm** remains above the back floor — no standard Li-Po exists
  that thin. Survey of the cavities: right grip has 0.24 mm spare (mated JST-PH),
  the **left grip (passive board: diodes 1.16 mm + the FFC ZIF) has 5.14 mm
  free**. The cell is now a **standard 403040 pouch (4.0 × 30 × 40 mm,
  ~450–500 mAh)** foam-taped (0.3 mm) to the left floor under the key field —
  0.84 mm below the diodes at nominal, ~0.4 mm at +10 % swell. 450–500 mAh is the
  capacity the README's own cell-size note preferred, and PROG (196 mA ≈ 0.43 C)
  needs no change. Support posts auto-route around the cell (it's an obstacle box
  in `support_post_locations`). Leads run left cavity → bottom-border lane (y≈5,
  outside the well) across the spine → J3 on the right board. Trade-off logged:
  battery replacement now means opening the left grip (5 screws + lid + keymat +
  board) instead of the panel hatch; the FFC stays panel-serviceable.
  > **⚠ The lead route is superseded by v0.27.** Nothing crosses the spine any more:
  > the cell plugs into **J4 in its own grip**, through **F1** (0.75 A PPTC), and
  > `VBAT_CELL` reaches the right board's charger over the bridge ribbon. The
  > left-grip-service trade-off below still stands.
- **FFC drops into a floor channel.** The ribbon crossed at z≈5.4 — inside the
  well now. A **0.5 mm recess in the back floor (19 mm lane at the J2 band)**
  gives it a 1.1..1.6 duct under the panel slab (0.5 mm headroom), S-bending down
  from each ZIF inside the grip cavities. The lower seam floor-tab moved
  30–38 → 36–44 so the channel doesn't thin it.
- **Transverse walls cut down to sills** (z 1.95) over the well span — the phone
  and the slab pass over them; full height outside the span still seats the
  border. The old ring-height Ø8 anchors are gone (their bores sit 8 mm above the
  new floor): MagSafe detach is held by the **4 border screws** + slab stiffness
  (~0.25 mm flex at 8 N), down-press by **4 floor nubs** under the slab. Panel
  screw count 6 → 4; **total M2×10: 16 → 14**.
- **Removal scallop.** With the phone sunk 9.4 mm, you can't pinch it — an R9
  thumb scallop in the top border exposes ~18 mm of case edge to tip it out
  against the ring.
- Phone x-retention is the grips' PCB/lid inner edges (0.3 mm clearance per
  side); y-retention the well's 2.0 mm wall band; alignment the MagSafe ring.

## v0.17 — Rii-height grips: chin cut + electronics to the top (2026-07-14)

Ergonomic feedback after printing the right grip lid: the grip (114.5 mm) was
significantly taller than the phone (~80 mm short-side) and than the Rii i8+ the
user thumb-types daily (~97 mm), the excess concentrated in a tall "chin" below the
bottom key row, and the 6-row field (55.5 mm) read taller than the i8+'s (~45 mm),
so the keys sat less within thumb reach. Goal: mimic the i8+'s proportions within
FDM + our-board limits — and since the **trackpad was dropped for v1**, the top zone
it would have occupied is free to reclaim.

- **Grip 114.5 → 97.0 mm** (the i8+ is ~97 mm); width 76.5 → 79.5 mm. Three levers:
  1. **Chin cut, `bottom_strip` 19 → 7 mm.** The 19 mm strip existed only to hold
     the E73 (18 mm) antenna-down at the bottom edge. With the module relocated
     (below), the chin under the space row drops ~23 → ~9 mm — the bulk of the excess.
  2. **Rectangular keys, `key` 8×8 → 8.5×7, `pitch` 9.5 → 10 (X) / 9 (Y).** The i8+
     keeps a short field with wider-than-tall chiclets; ours follow. The 7 mm domes
     (contact courtyard r3.9) still clear at 9 mm Y-pitch (1.2 mm courtyard gap);
     gutters stay ≥1.5 mm (X) / 2.0 mm (Y) for PETG-FDM. Field 55.5 → 52 mm.
  3. **Electronics to the top zone.** The E73 + the whole power front-end (USB-C,
     charger, ESD, reset/power switches, JST, passives, SWD/I²C pads) move from the
     old bottom strip up into the vacated trackpad space, implemented as a rigid
     180° rotation of the DRC-verified rev-A cluster about the board centre
     (`gen_board`'s `P()`/`xf()` involution), so the hand-routed USB fan-in copper
     carries along unchanged rather than being re-derived.
- **Antenna-up at the top edge.** The rotation lands the E73 antenna at the
  CENTRE-top edge — farthest from the centred phone/LiPo, and off the edge the palm
  (which cradles the bottom) doesn't cover. RF is a judgment call vs the old
  antenna-down: hand-detune should improve, phone/battery proximity is similar —
  **re-check range on the first article.** A small inward shift (`DX = 7`) keeps the
  13 mm module off the rounded corner; the JST is placed separately in the chin (its
  rotated pose hit the inner-top page keys); PgUp/PgDn move to the inner-top corner.
- **Top-outer corner sharpened, r_out 14 → 10** (bottom stays 14 for the palm) so
  the top cluster clears the corner — and squarer "shoulders" read more like the i8+.
- **Both boards re-routed 0/0** (KiCad 9, error-severity DRC + 0 unconnected); the
  fab package, firmware (byte-identical — the matrix/pin-map is unchanged) and all 2D
  renders are regenerated. Routing is tighter than rev-A (module-top / bridge-bottom
  puts the 14 bridge nets across the board); `route.sh` is a route-until-clean loop
  and hit 0/0 within a few passes.
- **Switch re-evaluated and KEPT: Snaptron 7 mm 4-leg dome** (2026-07-14 review,
  triggered by the rectangular-cap change). It verifiably fits the new geometry —
  courtyard Ø7.8 vs 9.0 mm Y-pitch = 1.2 mm gap (0.7 mm at the 8.5 mm cluster
  pitch), Ø2.8 nub presses every dome dead-centre (cap centre = dome centre for all
  79 keys incl. the 2u space), and both boards are routed 0/0 around this exact
  footprint. Alternatives lose: 8.4 mm domes physically don't fit the pitch; 5–6 mm
  domes give up travel/centre-hit tolerance under an 8.5 mm cap; LCSC SMD tacts
  (TS-1088 etc.) add 1.0–2.6 mm of z-stack (dome is 0.5 mm), 79 fab-soldered parts,
  and a full reroute. The fab's role is unchanged either way: ENIG gold pads only —
  domes press on at assembly. **Actionable:** sample LIGHT-force (~160–180 gf trip)
  4-leg domes, not the 400+ gf GX class, to approximate the i8+'s light feel.
- **3D regenerated for v0.17** (same session, after review): `deck3d.py` updated —
  keymat plungers/lid openings are now the real **rounded-rect 8.5 × 7 caps** (18.5
  for the 2u space; cluster keys stay round), the USB-C opening / power-switch slot /
  antenna wall relief moved to the TOP wall, the slide-switch knob direction is
  derived from the placed rotation, and the 4 panel seam screws are derived from the
  phone-pocket span (the old hardcoded y=105 was off the 97 mm shell entirely, and
  y=10 clipped the new pocket rim). The antenna wall stays CLOSED — 1.9 mm of PETG
  remains over the relieved span; the antenna radiates through plastic, not a hole.
  Also fixed a **latent v0.16 keymat bug the regen render exposed**: the cluster
  plungers (PgUp/PgDn, D-pad, mouse pair) sat outside the web buffer's reach — the
  "one-piece" keymat was really 3+ floating pieces. The web now grows the **3 mm
  living-hinge strips** the 2D concept always drew (each feature → nearest grid key
  + nearest other feature) and asserts single-polygon connectivity at build time.
  Also fixed: `deck.product()` origin rounding 2 → 3 decimals (a 79.493 mm board_w
  put the left grip 0.003 mm off the seam and tripped deck3d's frame assert).
- **Adversarial alignment audit (machine-verified, 2026-07-14):** all 79 domes sit
  at model key centres with 0.0 µm deviation on both boards; diodes at +3.0 mm; min
  dome courtyard spacing 9.0/8.5 mm vs the 7.8 floor; every non-dome footprint is
  back-mounted. Two margins worth knowing: (1) the cap Y-dimension (7.0) exactly
  equals the dome diameter — zero cover margin, so keymat registration (screw bosses
  + clamp rim) is what keeps the dome edge hidden; (2) the USB-C shield stakes and
  the J1/SW90 locating pegs protrude through to the PCB FRONT in the top zone —
  they clear the keymat web by ~8.4 mm and sit below the lid plate, but any rev-B
  front-side feature near x 31–40, y 90–95 must account for them.

## v0.16 — 5-part shell split for a 220 mm bed (2026-07-13)

Concept change from the sketches (`sketches/All.png`, `top_shell.png`, `side.png`):
the front is **two cyan grip lids** and a **pink center panel** that is visually
"the front of the back"; the back stays pink. Driver: the one-piece shells were
306 × 120 mm — they don't fit a Creality **Ender 3 V2 (220 × 220)** at any
rotation (min enclosing square ~302 mm); the target printer is now first-class.

- **Part set: 5 shells** — `back_left` + `back_right` (tray split at x=0 mid-
  spine, ~161/153 × 120 mm), `grip_lid_left/right` (~79 × 120), `center_panel`
  (~147 × 120). `deck3d.py --all` gates every part on **bbox ≤ 204 mm** (220 −
  2×8 brim). Keymats unchanged.
- **Staggered splices** — the bolted-on panel bridges the back seam at x=0; the
  continuous back halves bridge the front seams at the grip edges: every
  cross-section keeps one uncut structural member.
- **Back seam is screwless printed joinery** (adversarial design review killed
  the lap-screw variant: M2 inserts don't fit a 0.8 mm floor flap, and a
  horizontal lap is a 120 mm unprintable one-sided cantilever): floor butt +
  two full-thickness tabs into cleared notches, an 8 mm **vertical shiplap** in
  each perimeter wall (vertical faces print clean; 0.25 mm clearances), and a
  0.4 mm 45° outer V-groove = elephant-foot relief + intentional shadow line.
- **Panel/lid joint is a 0.3 mm open reveal, no overlap** — a shiplap/rebate
  here either lands on the inner lid screw heads (3.2 mm from the grip edge,
  fab-locked) or creates more mid-air mating faces; the reveal needs neither.
  Both edges get 0.8 mm 45° chamfers, so the seam reads as a design line.
- **Transverse spine wall at each grip boundary** (new, in each back half):
  closes each half's torsion box where the front plate is now cut, seats the
  panel edge, and carries a **Ø8 boss at MagSafe-ring height** — phone-detach
  pull anchors in line with the ring instead of peeling the panel. FFC and
  battery-lead windows are cut from the placed J2/J3 positions. *(⚠ v0.27: there are no
  battery-lead windows and no J3; the one remaining window is the FFC duct.)*
- **Panel plate 2.0 → 2.6 mm**: the Ø57 ring recess now leaves a **0.8 mm
  (4-layer) web** instead of one 0.2 mm layer; ring still sits 0.2 mm proud;
  spine grows 16.3 → 16.9 mm. Panel = spine **service hatch**: 6 screws expose
  battery + FFC without touching the grips.
- **Fasteners: 10 → 16 M2 (one SKU, M2×10 button-head)** — grips keep their 5
  per side untouched; the panel adds 4 floor bosses straddling the back seam +
  the 2 ring-height wall bosses.
- **Fixed en route:** `battery_body()` modeled the 503450 pouch rotated 90°
  (34 × 50 overflowed the 52 × 36 reserved rect y-span); `--sync-models` now
  refreshes the tracked `hardware/cad/models/` STLs (they had gone stale/orphan).
- `deck3d.py --check` = **0 collisions** (203 bodies); back-seam interpenetration
  asserted 0.000 mm³; both cosmetic faces verified flat for their print
  orientation.
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

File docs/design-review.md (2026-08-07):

# Design review record — rev-A (v0.15, 2026-07-11)

The rev-A audit: an **8-dimension adversarial review** (snap-dome contact
mechanics, module/RF placement, bridge, battery/power, USB, pin budget, firmware
buildability, mechanical/DFM) of the v0.14 design against datasheets, real part
geometry and the fab houses' constraints. It produced **120 findings, 14 of them
blockers**. Every blocker is fixed in the boards, firmware and CAD now in the
repo; both boards subsequently routed to **0 DRC violations / 0 unconnected**. The
CI workflow is a **self-contained ZMK v0.3.0 build** and it **passes** — run
29443394494 (2026-07-15) produced `thumbdeck-zmk.uf2`, and `firmware/` has not
changed since. That proves the firmware *compiles*, nothing more: it has never
been flashed to silicon. Earlier review records (the v0.4 nice!nano-era EE pass,
the v0.14 fab-readiness audit) are superseded by this file plus
[evaluation.md](evaluation.md).

## What changed and why

1. **Snap-dome footprint → production `snaptron_7mm_contact`.** Centre pad
   2.86 mm + a continuous leg ring (4.4–6.9 mm dia, drawn as 13 overlapping
   circles spanning 292°) with a **67.5° escape gap** through which the column
   trace reaches the centre pad. Worst-case dome rotation keeps 3 of 4 legs on
   the ring. Full mask apertures; F.Cu pour keepout r 3.8; all-layer via keepout
   r 3.6. No vent hole — venting comes from the Snaptron retention-tape channels.
   *Why:* the old "simple" 2-pad footprint gave **dead keys at 45° dome rotation**.
2. **E73 rotated antenna-UP at the top board edge (centre-top).** Its all-layer keep-out
   covers the antenna area and crosses the board edge (~3 mm on-board strip + the
   off-board extension); the on-board region is verified copper-free on all 4
   layers (plus a 0.6 mm shell-wall relief). *Was:* antenna
   pointing mid-board at the USB shell over ground pour — detuned.
3. **Bridge → 16-pin 1.0 mm FFC ZIF** (JUSHUO AFA07-S16FCC-00, C13744,
   bottom-contact, 2.5 mm tall) on each grip's inner edge + a **16-way 1.0 mm
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

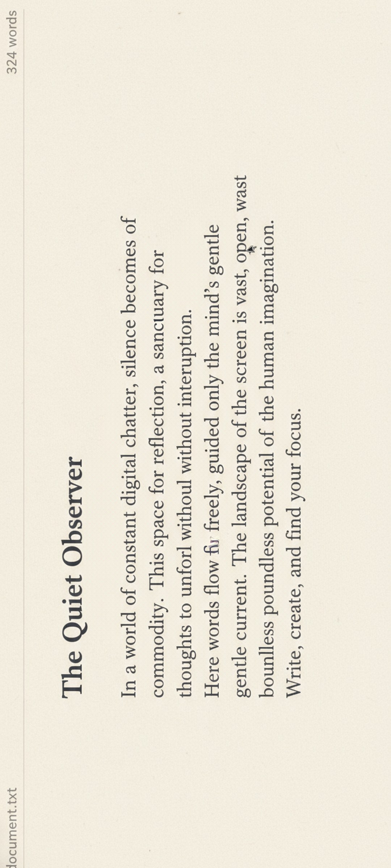
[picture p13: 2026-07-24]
hardware/cad/assets/screen_app.jpg

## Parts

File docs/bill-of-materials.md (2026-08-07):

# Bill of materials — rev-A (v0.27)

Authoritative electrical BOM is machine-exported per board to
`hardware/kicad/generated/fab/right/bom.csv`
and `fab/left/bom.csv` (JLC format, exported only when DRC is clean —
regenerate with `python3 hardware/scripts/gen_fab.py`; the fab package is a build
artifact and is not committed). The tables below mirror those files and add the
mechanical / hand-installed items. Older 50-key and Raytac/Cirque BOMs are history —
see git history and [design-decisions.md](design-decisions.md).

## Right grip board (`thumbdeck_right`) — 70 SMT placements, all bottom side

| Comment | Designators | Package / footprint | LCSC | Role |
|---|---|---|---|---|
| E73-2G4M08S1C | U1 | nRF52840_E73-2G4M08S1C | **C356849** | nRF52840 module, antenna-up off the top edge (centre-top). Extended, X-ray, **low stock — reserve early**. |
| MCP73831 | U2 | SOT-23-5 | C424093 | LiPo charger (-2ACI, 4.2 V). PROG = R24 → ~196 mA. |
| USBLC6-2SC6 | U3 | SOT-23-6 | C7519 | USB ESD, **inline** between USB-C and module. |
| USB-C | J1 | HRO TYPE-C-31-M-12, full SMD 16P | C165948 | Charge + flash. Extended part. |
| FFC20 | J2 | ffc_afa07_s20fcc (AFA07-S20FCC-00) | **C262352** | **20**-pin 1.0 mm bottom-contact ZIF, bridge to the left grip. **v0.27: was 16-pin (C13744)** — the ribbon now carries the cell as well as the matrix (2× GND, 14 matrix, 2× VBAT_CELL, 2 unconnected guard positions). Same Extended tier as the 16-way, so no assembly-class change. |
| MSK12C02 | SW90 | msk12c02_slide | C431540 | Power slide switch, cell+ → VBAT; charger stays on the cell side. |
| TS-1187A | SW91 | SW_Push_1P1T (top-actuated) | C318884 | Reset tact, pressed via a 1.6 mm shell-floor pinhole (UF2 double-tap). |
| TMAG5273A1 | U4 | SOT-23-6 | **C3716049** | v0.21 pointing-nub hall sensor (Bean-style): I²C 3-axis, addr 0x35, reads the nub magnet through the 1.6 mm FR4. Basic-class SMT — machine-placed, no hand assembly. |
| LED_RED | D80 | 0603 | C2286 | Charge LED on MCP73831 STAT (through R25). **Check polarity in the DFM preview.** |
| 1N4148WS | D1–D36 (36×) | SOD-323 | C2128 | Matrix diodes, cathode → row. Basic part. |
| 4k7 | R1–R9 (9×), R26, R27 | 0402 | C25900 | Row pull-downs (R1–R9) + I²C SDA/SCL pullups (R26/R27). |
| 5k1 | R20, R21, R24 | 0402 | C25905 | CC1/CC2 pulldowns (R20/R21) + charger PROG (R24). |
| 1M | R22, R23 | 0402 | C26083 | Battery ÷2 divider on VBAT_SENSE (P0.02/AIN0). |
| 1k | R25 | 0402 | C11702 | Charge-LED series resistor. |
| 4u7/0805 25 V | C3, C4, C5 | 0805 | C1779 | Charger stability caps **at the chip** (C3 = VDD/VBUS, C5 = VBAT_CELL) + VBAT bulk (C4). 25 V rating — no derating collapse at 5 V. |
| 1uF | C1, C7 | 0402 | C52923 | 3V3 (C1) and VBUS (C7) decoupling. |
| 100nF | C2, C6, C8 | 0402 | C1525 | VBAT decoupling (C2) + SAADC filter on VBAT_SENSE (C6) + TMAG5273 bypass (C8). |

Plus non-BOM copper features: silk-labelled test pads **TP1–5** (SWDIO, SWDCLK,
RESET, 3V3, GND) and **TP6–8** (v0.21: now the live **SDA / SCL / TP_INT** I²C
nets of the nub sensor — still probe-able, and still the rev-B expansion bus).

**v0.27: there is no J3.** The battery connector moved to the **left** board (J4),
with the cell's fuse (F1) beside it, so the cell plugs in ~8 mm from where it lives
instead of running a ~265 mm bare pigtail across the whole device. VBAT_CELL reaches
this board's charger and switch over the bridge ribbon. The power tree is otherwise
unchanged — the charger still sits on the **cell** side of SW90, so it still charges
while the device is switched off, and VBAT_SENSE (R22/R23/C6 → AIN0) is untouched.

## Left grip board (`thumbdeck_left`) — 45 SMT placements, all bottom side

| Comment | Designators | Package | LCSC | Role |
|---|---|---|---|---|
| 1N4148WS | D1–D42 (42×) | SOD-323 | C2128 | Matrix diodes. |
| FFC20 | J2 | ffc_afa07_s20fcc | **C262352** | Bridge ZIF, inner edge. **v0.27: 20-pin** (was 16-pin C13744) — matrix + cell. |
| JST-PH-2 | J4 | S2B-PH-SM4-TB side-entry SMT | C295747 | **v0.27, new:** the battery connector, in this grip's chin at deck (60.0, 5.5), mouth facing +y — the cell that lives here now terminates here. Polarized — but **meter the pigtail** against the "+"/"−" silk, see assembly. Pin 1 = "+". |
| PPTC-0.75A | F1 | 1812 (Bourns MF-MSMF075-2) | **C84140** | **v0.27, new and SAFETY-CRITICAL:** resettable fuse in series with the cell **positive**, between J4 and J2, at deck (50.0, 5.5). 0.75 A hold / 1.5 A trip, 13.2 V, Imax 100 A, initial resistance ≤0.45 Ω. **It must be on the CELL side of the ribbon or it protects nothing.** The ribbon now carries the raw cell: a 1S pouch's own PCM does not trip until 2.0–2.5 A, but a 1.0 mm-pitch FFC conductor (0.70 × 0.035 mm = 0.0245 mm²) reaches its 105 °C insulation limit at about 2.8 A·√s and melts its own PET in ~0.2 s at a real short. The 0.43–2.0 A band in between — the signature of a partially abraded conductor in a mechanism that flexes on every phone insertion — is covered by nothing else. Do not omit it, do not substitute a lower-current part (0.5 A derates toward the charge current at car-dash temperatures). What it costs you: the ≤0.45 Ω sits in the charge loop, so undercharge at termination is ITERM × Rloop ≈ **10–16 mV** — negligible against the MCP73831's own ±32 mV VREG tolerance. The real cost is **charge time**, not capacity (CC→CV handover happens at a lower cell voltage, so the taper is longer). v0.27 also gives VBAT_CELL/VBAT a real power netclass at **0.4 mm** — before that VBAT_CELL shipped at 0.2 mm, ~336 mΩ, a third of the whole loop. |

The left board is no longer *quite* passive: as of v0.27 it carries the cell's
connector and the cell's fuse, and nothing else. Still no MCU, no charger, no switch,
no radio — it's still cheap and Economic assembly is still fine.

## Mechanical / hand-installed

| Item | Spec | Qty | Notes |
|---|---|---|---|
| Snap domes | **Snaptron 7 mm 4-leg** (SnapForce) | 78 + spares (36 right / 42 left) | Pressed, not soldered, onto the ENIG contact pads. |
| Dome retention | Snaptron taped polyimide array (Peel-N-Place) or 0.2–0.3 mm laser-cut polyimide spacer | 2 | **Required** — laterally retains each dome; the tape channels also vent them. **v0.25:** this layer is *not modelled in the CAD*, so no collision check knows it exists — but it is the surface the left keymat's nav-pad back rib actually meets. `DOME_RETAIN_T` = 0.3 (the spec'd max) is subtracted before the rib's 0.2 mm clearance, so the rib clears the layer at any thickness in range rather than being preloaded into it. |
| FFC jumper | **20-way, 1.0 mm pitch, TYPE-A ONLY** — contacts on the **same side at both ends** — **length ≥240 mm** (v0.24) | 1 | Straight ribbon; contacts face the boards at both ends. Type-A is load-bearing. **⚠ v0.27: this is a 20-way part, and a 16-way ribbon is now a fire hazard rather than a wiring mistake.** 16-way stock is 17.0 mm wide and drops into the 20-way housing's 21.0 mm slot with 4.0 mm of slop at *each* end — up to a 4-position shift, and nothing about the fit will tell you. Quote the ≥240 mm length against 20-way stock. **v0.24:** the clamp span is now VARIABLE (the grips slide 130–170 mm), so the ribbon carries a **rolling service loop** that folds in a channel under the telescoping bridge and pays out as the jaw moves — sized to reach at max extension (~195 mm J2-to-J2) plus the fold. Coupon-tune the loop radius. **v0.24d:** the ribbon runs in its **own walled channel on J2's y centre** — dead straight into the ZIF, with a divider rib between it and each spring lane, so the loop can crumple at short spans without finding a coil to snag on. **v0.27:** the ribbon now carries the **battery** as well as the matrix, which deleted the separate power cable and its whole lane — the tray's lane plan is `spring \| FFC \| spring`, and the flex channel widened 17.0 → 21.0 mm and moved with J2 from y 24.5 → **28.5** (a 21 mm ribbon on the old centre overlapped the front spring lane). Conductor order, starting at the ribbon's **highest** deck-y edge: GND, GND, ROW0–8, COL5–9, NC, VBAT_CELL, VBAT_CELL, NC. That leaves 15 positions between VBAT_CELL and GND, so even a full 4-position mis-seat lands VBAT on a **column** (one dead MCU pin) instead of on GND (a dead cell short), and the two NC guards absorb a ±1 slip outright. The 14 matrix signals are unchanged, so **firmware is unaffected**. **v0.27 also built the duct the ribbon needs to get out of the grip** — it had never existed for either cable. J2's slot now faces **inboard**, and the ribbon folds in the back cavity and exits through a low duct under the phone cradle, so the fold you make at assembly is a static crease inside the grip rather than a bend the ZIF has to absorb. |
| LiPo | 1S **403040** pouch (4.0 × 30 × 40 mm, ~450–500 mAh), JST-PH pigtail, **with an integrated PCM** | 1 | Foam-taped (0.3 mm) to the **left grip's floor** under the PCB. v0.24: the left grip is the sliding clamp jaw, so the cell rides with it; the FFC is the only cross-grip link. Replacement means opening the left grip (5 screws, lid, keymat, board). **Meter polarity against the "+"/"−" silk at J4, on the LEFT board, first** (pin 1 = "+"). **v0.27: a protected cell is a HARD REQUIREMENT, not advice** — the pouch must carry an integrated protection module (overcurrent 2.0–2.5 A / 8–16 ms, overcharge 4.275 V, overdischarge 2.75 V). Unprotected "bare" 403040 cells are sold and they are the wrong part here. The PCM and F1's PTC cover **different** bands and neither alone is sufficient: the PCM does nothing in the 0.43–2.0 A band that cooks a 1.0 mm FFC conductor, and the PTC does nothing about overcharge or overdischarge. **v0.27: the cell plugs into J4 in its own grip** (~8 mm of pigtail), not across the device. |
| TPU grippers (v0.24) | 2× soft **polyether TPU 95A**, **100 % infill** — edge-grip + **teeth** + lip **facing** (`gripper_left/right`), print with the keymats | 2 | Specify **polyether**, not polyester, TPU (any TDS stating polyether; NinjaTek and similar): polyester TPU hydrolyses in warm humid service, which is exactly a phone grip. 100 % infill is mandatory — a sparse pad's stiffness is infill-dependent, not material-dependent. Compliant grip on the cased short edge, plus half-round **teeth** (3.4 mm pitch, 0.8 mm proud, ribs along the phone's thickness) that bite it so the phone can't creep or rotate in y. **v0.24e — this part still retains the phone, and the lip stays TPU on purpose:** it has to flex for phone+case thickness variance, and hard plastic on cover glass is a scratch source. A rigid hook over the phone was tried and rejected (a hook at a fixed z can only capture a phone at or below the nominal cased thickness). The shell now carries a **retainer that caps the lip's root only** — it stops 0.4 mm outboard of the clamped phone edge, so nothing rigid is over the screen — which stops the gripper peeling off without stiffening the part that needs to give. Slide each gripper in from the **y end, under the retainer** — teeth facing the phone. |
| Clamp springs (v0.24) | 2×, in the tray's outboard y lanes (13.5 / 83.5), ~40 mm working travel | 2 | The clamp force. **v0.24e moved the anchor to x = 76**, so the installed length runs 61.85 → 105.85 mm — a **1.71:1** length ratio instead of the 6.1:1 (510 % extension) the x = 22 anchor demanded. **⚠ Do not buy hooked extension springs yet.** The math doesn't close: a Ø4 / 0.5 mm music-wire spring at C = 7 caps initial tension at ~1.85 N/spring (τ_i would need ~259 MPa vs a ~160 MPa limit), so min-span clamp lands ~5.8 N total, and τ ≈ 870–930 MPa against an ~843 MPa cyclic allowable means it is **fatigue-limited on a part that cycles every insertion — and a hook's failure mode is total release.** Backbone / Kishi / GameSir / Abxylute all use **compression springs captive in the bridge** or a **constant-force spiral** instead. Pick one before ordering. |
| Nub magnet (v0.26) | **Ø4 × 2 mm, NdFeB **N45**, Ni‑Cu‑Ni plated, **AXIALLY magnetized** (poles on the flat faces).<br>**Primary: supermagnete `S-04-02-N`** — Br 1.32–1.37 T, ≤ 80 °C, 0.19 g, ~€0.26 ea in 20‑packs, mass stock.<br>**US: totalElement `D4X2MMN52-250PK`** (N52, Br 1.48 T — see temperature note).<br>**Hot‑climate option — NOT a drop‑in: Radial Magnet 9039 = Digi‑Key `469-1072-ND`** — Ø4 × **2.5** mm N35SH, 150 °C, 100 % sorted to ≤ 3° magnetization‑angle deviation. | 1 + spares | **Order by SKU, not by description.** A Ø4 × 2 mm *diametrically* magnetized disc is also a cataloged product and is the wrong part — it would give the sensor a large static transverse field and a pointer that drifts with cap rotation. Every SKU above is axial. <br>**Grade:** N45, not N52. N52 has the **lowest** service temperature of the common grades (**≤ 65 °C** vs ≤ 80 °C for N45/N42) and this device clamps a phone, sits in sunlight and rides in cars. Past that limit the loss is **irreversible**, and the driver's boot‑zero *cannot* recover it — it silently re‑zeros a weaker magnet and pointing goes permanently sluggish. The 8 % lower Br costs nothing that matters (see `deck3d.py --nub`). Use the N35SH part if the build will see a hot car dash. <br>**Fit:** the pocket is **Ø4.20** (v0.26, was Ø4.10). Stock Ø4 discs are ±0.10, so a +tolerance magnet *is* Ø4.10 — and FDM prints holes undersize, which makes a hand press‑fit into the hub's 1.45 mm wall a split‑hub risk. Bond it with a drop of cyanoacrylate instead; a press fit in a printed part relaxes anyway. <br>**Polarity: N pole DOWN, toward the sensor.** Find N with a compass first — the magnet face that attracts the needle's **SOUTH/white** end is N. The driver calibrates zero at boot but **not** polarity, so a flipped magnet gives a correctly-scaled, permanently **inverted** pointer. <br>**Handling:** keep it away from the assembled boards until it goes in — it will happily jump onto a steel tool and chip (NdFeB is brittle and the Ni plating is the corrosion barrier). <br>**⚠ The Ø4 × 2.5 mm N35SH part is a CAD change, not a substitution.** Because the magnet is bonded against the pocket **ceiling**, an extra 0.5 mm of thickness grows **downward**: the magnet‑to‑die gap falls 3.33 → 2.83 mm (outside the asserted 3.05–3.65 band, so `deck3d.py --report` will fail), and the air gap under the magnet falls 0.95 → 0.45 mm — below the 0.5 mm assert and leaving only 0.10 mm beneath the plunge stop. To use it, raise `NUB_POCKET_TOP` 12.45 → 12.95, which thins the hub crown 1.55 → 1.05 mm. Only worth it for a build that will live on a hot car dashboard. |
| Shells | **v0.25: 6 printed parts** (was 7 — the `bridge` tray is now part of `back_right`): 5 in PETG — `back_left` (moving jaw), **`back_right` (ground — grip + fixed tray as ONE part)**, `grip_lid_left`, `grip_lid_right`, + v0.21 `nub_spring` (Ø14.8 flexure, magnet press-pocket, v0.22 **4.4 mm-square TrackPoint cap platform** — arm thickness is the print-tune coupon) — and the v0.22 `nub_cap` (classic ThinkPad soft-dome replica, **RED TPU 95A**, prints with the keymats). **Or skip printing the cap: any genuine classic full-size TrackPoint cap (soft dome / soft rim / classic dome, ~4.5 mm square socket) fits the platform directly.** | 1 set | STLs tracked in `hardware/cad/models/` (regenerate: `deck3d.py --all --sync-models`). Every part fits an Ender 3 V2 (220 × 220) flat. **v0.24: `center_panel` retired → `bridge` tray; `gripper_left/right` (TPU) added. v0.25: `bridge` merged into `back_right` (joint deleted, not fixed); the faceted back crown deleted and both grips' backs dropped to the tray plane, so the whole back is one flat plane with a 1.2 mm quarter-round edge.** Fit-checked 0 collisions across the 130–170 mm clamp travel (min/nominal/max). |
| Keymats | per-grip, **TPU 95A** | 2 | Living-hinge web; coupon-test >10 k cycles first. **v0.17 geometry**: rectangular 8.5 × 7 rounded-rect caps (2u caps for the space bars + the right H-row's Rii-style Enter), round cluster keys, debossed keycap legends; ~63 × 86–89 mm per mat. **v0.25**: the left mat's nav cluster is one **Ø24 integrated D-pad** (four arm sectors + Ø9 centre OK, 2.0 mm moats over a web thinned to 0.4 mm) with an annular **back rib** at r 13.0–14.5 that meets the grip lid's clamp ring — print it **100 % infill** like the grippers, or the rib's stiffness is infill-dependent and the presses stop being discrete. Print cap-side **down**: the legends deboss cleanly off the bed and the rib/nubs become upstands, so no support. |
| M3 hardware | **M3×10 countersunk (DIN 965)** screws + M3 heat-set inserts (Ø4.0 bores, OD ≤4.6, ~4 mm long) | 10 + 10 | Heads FLUSH with the face: 5 per grip lid. v0.24: the 4 panel border screws are gone (no center panel); the bridge bolts to the right grip with 2 short M3s into its cradle bosses. |
| Bootloader flash rig | SWD probe (J-Link/CMSIS-DAP/pi) + 5 jumper wires | 1 | One-time Adafruit-bootloader flash on TP1–5. |

## Deliberately absent (vs earlier drafts)

- **Trackpad (IQS7211E / Cirque):** dropped from v1; v0.21 gives pointer duty to the
  right-grip hall nub (FN-layer mouse keys + D-pad remain as fallback).
- **ALPS RKJXV analog stick:** implemented then reverted inside v0.21 — the THT
  gimbal module can't sit flush (11.2 mm body vs 5.2 mm cavity) and needed JLC
  hand-solder. The hall nub replaces it outright; see design-decisions.md.
- **JST-GH bridge / 2×08 pin header:** replaced by the FFC ZIF pair + type-A jumper
  (the THT header could not physically fit the shell cavity).
- **Separate battery power cable (v0.24):** deleted in v0.27 — the 20-way bridge
  ribbon carries VBAT_CELL, so there is no second cable crossing the spine and no
  second lane in the tray. Do not buy a 2-wire JST-PH cable for this build.
- **16-way FFC parts — AFA07-S16FCC-00 / C13744 / 16-way jumpers:** superseded in
  v0.27 and **not substitutable**. The `ffc_afa07_s16fcc` footprint is kept in
  `hardware/footprints/thumbdeck.pretty/` only for the earlier board files that
  reference it; nothing on the current BOM is 16-way.
- **Column series resistors + dome-field TVS:** never made it onto any real board;
  the bridge is a fully internal, GND-referenced ribbon. Rev-B option if field ESD appears.

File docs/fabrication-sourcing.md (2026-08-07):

# Fabrication & sourcing — rev-A (v0.27)

> **These boards have never been fabricated.** rev-A is routed, DRC-clean (0/0) and
> the fab package exports cleanly, but no order has ever been placed and no board
> has been brought up. DRC-clean means *no design rule is violated* — it is not a
> proof that the circuit works. Anyone ordering from this document is ordering the
> first article. See [evaluation.md](evaluation.md) for what is and is not verified.

**Recommendation: JLCPCB turnkey PCBA, two separate orders (right + left), 4-layer,
ENIG, single-sided bottom assembly.** The fab package is generated by the pipeline —
nothing to draw, route or export yourself. Run `python3 hardware/scripts/gen_fab.py`
(it refuses unless DRC is 0/0) and it lands in:

```
hardware/kicad/generated/fab/right/  thumbdeck_right_gerbers.zip + bom.csv + positions.csv
hardware/kicad/generated/fab/left/   thumbdeck_left_gerbers.zip  + bom.csv + positions.csv
```

Rough cost target **~$150–250 delivered for 5 sets** of both boards assembled
(indicative 2026 figures — **re-quote at order time**; the E73 price and stock move).
This is **boards + assembly only.** It excludes the domes and retention array, the
LiPo (which must be a **protected** cell — see the BOM), the **20-way** FFC jumpers,
MagSafe rings, M3 hardware, filament, and an SWD probe for the one-time bootloader
flash — budget for those separately (see
[bill-of-materials.md](bill-of-materials.md)).

## Placing the two orders

For each board: upload the `*_gerbers.zip`, choose PCBA, then upload `bom.csv` and
`positions.csv` (they're already in JLC's column format).

| Option | Right board | Left board |
|---|---|---|
| Layers / material | **4-layer**, 1.6 mm FR-4 | same |
| Surface finish | **ENIG — mandatory** (snap domes press on bare pads; HASL oxidises within weeks of key cycling) | same |
| Assembly | **Standard** (forced: the E73 is an Extended part that needs X-ray inspection) | **Economic** is fine (42 diodes, the bridge ZIF, and — v0.27 — the battery JST + its PPTC) |
| Assembly side | **Bottom** (all parts are on the back; the front must stay bare for the domes) | Bottom |
| Panelize? | **No.** Two different designs — panelizing them costs more than two small orders. | No |

### Why two orders, not one panel

Earlier drafts assumed "panelize L+R into one panel, pay setup once". Quoted for
real: a mixed panel of two distinct designs triggers JLC's multi-design surcharges
and a bigger stencil, and the left board no longer shares the right board's Standard
assembly requirement. Two separate orders — the trivial left one on Economic — comes
out cheaper.

**v0.27 doesn't change this.** Moving the battery connector to the left board (J4)
and adding its fuse (F1) takes that board from 43 to **45 placements** — two extra
feeders on the Economic order, not an assembly-class change. There is still no MCU,
no X-ray part and nothing hand-soldered on it. The right board drops to **70
placements** (J3 is gone).

## DFM preview checklist (before paying)

Expect one DFM confirmation hold on the right board: **the E73 module body
overhangs the top board edge by ~0.75 mm by design** (its antenna must clear
the PCB). Reply "proceed as designed" — the overhang is intentional and the
shell has a matching wall relief. (v0.17 moved the E73 to the top zone with the
antenna pointing up off the top edge; the shell was regenerated 2026-07-14 — the
relieved top wall stays **closed** at 1.9 mm over the antenna span, so the module
tip has ≥0.5 mm clearance and the antenna radiates through thin PETG, not a hole.)

`gen_fab.py` exports KiCad-native rotations; JLC's library orientation can differ
per part. In the DFM/component preview, verify and rotate if needed:

1. **Charge LED D80 polarity** — the classic JLC 180° flip. Cathode toward the
   MCP73831 STAT side.
2. **SOT-23-5 / SOT-23-6 rotation** (U2 MCP73831, U3 USBLC6-2SC6).
3. **USB-C (J1)** seated on the pad pattern, shell at the board edge.
4. **E73 (U1) orientation** — antenna edge pointing off the top board edge.
5. **J4 (JST-PH) on the LEFT board** (v0.27, the left board's first polarized part)
   — mouth facing **into** the grip (+y, over the board), pin 1 against the "+" silk.
   A 180° flip aims the mated plug off the bottom board edge into the shell wall.
   F1 next to it is a PPTC and is not polarized.
6. Confirm every part is placed in the **single-pass SMT assembly** — nothing is
   hand-soldered. (The USB-C shell's plated stakes and the FFC/slide-switch
   locating pegs are the only through-board features, and they go on in the same
   pass; if the preview asks for a separate THT/hand-solder step, something is
   wrong.)

## Key parts (LCSC numbers as ordered)

| Part | LCSC | Tier | Notes |
|---|---|---|---|
| Ebyte E73-2G4M08S1C | **C356849** | **Extended + X-ray, stock VOLATILE** (observed from ~1000 down to ~20 units within days) | **Check jlcpcb.com/parts for C356849 and reserve/backorder the modules BEFORE anything else.** Forces Standard assembly on the right board. Backup: Holyiot 18010 — requires a footprint change (rev-B). |
| USB-C 16P full-SMD | C165948 | Extended | |
| MCP73831T-2ACI/OT | C424093 | Extended | Don't sub -2ATI (different Vreg behaviour). |
| USBLC6-2SC6 | C7519 | Extended | |
| FFC ZIF **AFA07-S20FCC-00** | **C262352** | Extended | One per board. **v0.27: 20-pin, not the old 16-pin C13744** — the bridge carries the battery now. 1.0 mm pitch, bottom contact, slide lock, side entry, 2.5 mm height, 0.3 mm FFC, tin plating; ~21.9 k in LCSC stock. Same Extended tier as the 16-way, so it costs a feeder, not an assembly class. **Order the matching 20-way TYPE-A jumper** (contacts same side both ends) — a 16-way ribbon fits this housing with 4 mm of slop per end and is a fire hazard, see the BOM. |
| JST-PH S2B-PH-SM4-TB | C295747 | Extended | **v0.27: this is J4 on the LEFT board** (it was J3 on the right). The right board has no battery connector any more. |
| PPTC 0.75 A — Bourns MF-MSMF075-2 | **C84140** | **Confirm the tier when you quote** | **v0.27, new: F1 on the LEFT board, and it is safety-critical.** 1812, 0.75 A hold / 1.5 A trip, 13.2 V, Imax 100 A, initial resistance ≤0.45 Ω. It sits in series with the cell positive between J4 and J2, on the **cell** side of the ribbon — anywhere else and it protects nothing. Do not let a quote substitute a different hold current. |
| MSK12C02 slide switch | C431540 | Extended | |
| TS-1187A reset tact | C318884 | Extended | |
| 1N4148WS SOD-323 | C2128 | **Basic** | 78 across both boards (36 right / 42 left). |
| Red LED 0603 | C2286 | Basic | |
| All R/C (0402/0805) | C25900, C25905, C26083, C11702, C52923, C1525, C1779 | **Basic** | The 4.7 µF is deliberately **0805 25 V** (C1779) — a 0402 4µ7 derates to ~1 µF at 5 V bias. |

## What stays manual (either fab house)

Snap domes are mechanical spring contacts — they oxidise/warp in reflow, so no
house machine-places them. Your steps after delivery: press the **78 domes** under
the Snaptron retention array, print shells + keymats, foam-tape the battery into
the **left grip before its board goes in**, seat the **20-way** FFC jumper in the
tray channel and both ZIFs — **ribbon first, cell into J4 last**, because the ribbon
carries VBAT_CELL and goes live the moment the cell is plugged in — bolt the
`bridge` tray to the right grip (2 M3s) and lap the left grip's shroud into it,
press the TPU grippers + MagSafe ring, close the shell.
PCBWay can quote manual dome-sheet application, but it
roughly doubles the cost — pressing them yourself is a calm 20-minute job.

## Cost shape (5× each board, assembled)

Flat fees dominate at qty 5: 4-layer PCB + ENIG, one Standard assembly setup +
stencil (right), one Economic setup (left), Extended-feeder fees, E73 X-ray, parts
(~$6 × 5 for the E73 dominates), shipping. Per-board cost only falls with volume.
**Both orders exclude** the domes + retention array, LiPo, printed parts, M3
hardware and the **20-way** FFC jumper — see
[bill-of-materials.md](bill-of-materials.md).

## Caveats

- **E73 stock is volatile** (~1000 → ~20 units observed within days): check
  jlcpcb.com/parts for **C356849** and **reserve/backorder the modules before
  anything else**. The Holyiot 18010 backup requires a footprint change (rev-B).
- **v0.27: the bridge is 20-way.** Any 16-way ZIFs (C13744) or 16-way ribbons bought
  against an earlier version of this document are the wrong parts, and in this build
  they are dangerous rather than merely wrong: a 17.0 mm 16-way ribbon seats in the
  21.0 mm 20-way housing with 4.0 mm of slop at each end. Scrap them.
- **The cell is now on the ribbon**, so F1 (C84140) must be fitted and the LiPo must
  be a **protected** cell with an integrated PCM. They cover different fault bands and
  neither alone is sufficient — see [bill-of-materials.md](bill-of-materials.md).
- **ENIG is mandatory** — state it explicitly; don't let a quote default to HASL.
- Selective hard gold on dome pads is a production-volume upgrade; plain ENIG is
  fine for a personal build.
- Rotations: trust the DFM preview over the CPL numbers (see checklist above).

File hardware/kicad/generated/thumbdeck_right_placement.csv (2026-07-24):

ref | legend | row | col | x_mm | y_mm
SW1 | F6 | ROW0 | COL0 | 12.25 | 39.5
SW2 | F7 | ROW0 | COL1 | 22.25 | 39.5
SW3 | F8 | ROW0 | COL2 | 32.25 | 39.5
SW4 | F9 | ROW0 | COL3 | 42.25 | 39.5
SW5 | F10 | ROW0 | COL4 | 52.25 | 39.5
SW6 | DEL | ROW1 | COL0 | 62.25 | 39.5
SW7 | 6 | ROW1 | COL1 | 12.25 | 48.5
SW8 | 7 | ROW1 | COL2 | 22.25 | 48.5
SW9 | 8 | ROW1 | COL3 | 32.25 | 48.5
SW10 | 9 | ROW1 | COL4 | 42.25 | 48.5
SW11 | 0 | ROW2 | COL0 | 52.25 | 48.5
SW12 | BSP | ROW2 | COL1 | 62.25 | 48.5
SW13 | Y | ROW2 | COL2 | 12.25 | 57.5
SW14 | U | ROW2 | COL3 | 22.25 | 57.5
SW15 | I | ROW2 | COL4 | 32.25 | 57.5
SW16 | O | ROW3 | COL0 | 42.25 | 57.5
SW17 | P | ROW3 | COL1 | 52.25 | 57.5
SW18 | ; | ROW3 | COL2 | 62.25 | 57.5
SW19 | H | ROW3 | COL3 | 12.25 | 66.5
SW20 | J | ROW3 | COL4 | 22.25 | 66.5
SW21 | K | ROW4 | COL0 | 32.25 | 66.5
SW22 | L | ROW4 | COL1 | 42.25 | 66.5
SW23 | ENT | ROW4 | COL2 | 57.25 | 66.5
SW24 | N | ROW4 | COL3 | 12.25 | 75.5
SW25 | M | ROW4 | COL4 | 22.25 | 75.5
SW26 | , | ROW5 | COL0 | 32.25 | 75.5
SW27 | . | ROW5 | COL1 | 42.25 | 75.5
SW28 | / | ROW5 | COL2 | 52.25 | 75.5
SW29 | SHF | ROW5 | COL3 | 62.25 | 75.5
SW30 | SPC | ROW5 | COL4 | 17.25 | 84.5
SW31 | ALT | ROW6 | COL0 | 32.25 | 84.5
SW32 | [ | ROW6 | COL1 | 42.25 | 84.5
SW33 | ] | ROW6 | COL2 | 52.25 | 84.5
SW34 | CTL | ROW6 | COL3 | 62.25 | 84.5
SW35 | PGUP | ROW6 | COL4 | 57.25 | 12.5
SW36 | PGDN | ROW7 | COL0 | 57.25 | 23.5

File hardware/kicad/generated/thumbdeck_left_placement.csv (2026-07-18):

ref | legend | row | col | x_mm | y_mm
SW1 | F5 | ROW0 | COL5 | 62.75 | 39.5
SW2 | F4 | ROW0 | COL6 | 52.75 | 39.5
SW3 | F3 | ROW0 | COL7 | 42.75 | 39.5
SW4 | F2 | ROW0 | COL8 | 32.75 | 39.5
SW5 | F1 | ROW0 | COL9 | 22.75 | 39.5
SW6 | ESC | ROW1 | COL5 | 12.75 | 39.5
SW7 | 5 | ROW1 | COL6 | 62.75 | 48.5
SW8 | 4 | ROW1 | COL7 | 52.75 | 48.5
SW9 | 3 | ROW1 | COL8 | 42.75 | 48.5
SW10 | 2 | ROW1 | COL9 | 32.75 | 48.5
SW11 | 1 | ROW2 | COL5 | 22.75 | 48.5
SW12 | ` | ROW2 | COL6 | 12.75 | 48.5
SW13 | T | ROW2 | COL7 | 62.75 | 57.5
SW14 | R | ROW2 | COL8 | 52.75 | 57.5
SW15 | E | ROW2 | COL9 | 42.75 | 57.5
SW16 | W | ROW3 | COL5 | 32.75 | 57.5
SW17 | Q | ROW3 | COL6 | 22.75 | 57.5
SW18 | TAB | ROW3 | COL7 | 12.75 | 57.5
SW19 | G | ROW3 | COL8 | 62.75 | 66.5
SW20 | F | ROW3 | COL9 | 52.75 | 66.5
SW21 | D | ROW4 | COL5 | 42.75 | 66.5
SW22 | S | ROW4 | COL6 | 32.75 | 66.5
SW23 | A | ROW4 | COL7 | 22.75 | 66.5
SW24 | CAP | ROW4 | COL8 | 12.75 | 66.5
SW25 | B | ROW4 | COL9 | 62.75 | 75.5
SW26 | V | ROW5 | COL5 | 52.75 | 75.5
SW27 | C | ROW5 | COL6 | 42.75 | 75.5
SW28 | X | ROW5 | COL7 | 32.75 | 75.5
SW29 | Z | ROW5 | COL8 | 22.75 | 75.5
SW30 | SHF | ROW5 | COL9 | 12.75 | 75.5
SW31 | SPC | ROW6 | COL5 | 57.75 | 84.5
SW32 | ALT | ROW6 | COL6 | 42.75 | 84.5
SW33 | WIN | ROW6 | COL7 | 32.75 | 84.5
SW34 | FN | ROW6 | COL8 | 22.75 | 84.5
SW35 | CTL | ROW6 | COL9 | 12.75 | 84.5
SW36 | NAV_OK | ROW7 | COL5 | 42.7 | 18.0
SW37 | NAV_U | ROW7 | COL6 | 42.7 | 9.5
SW38 | NAV_D | ROW7 | COL7 | 42.7 | 26.5
SW39 | NAV_L | ROW7 | COL8 | 34.2 | 18.0
SW40 | NAV_R | ROW7 | COL9 | 51.2 | 18.0
SW41 | MB_L | ROW8 | COL5 | 17.75 | 12.5
SW42 | MB_R | ROW8 | COL6 | 17.75 | 23.5

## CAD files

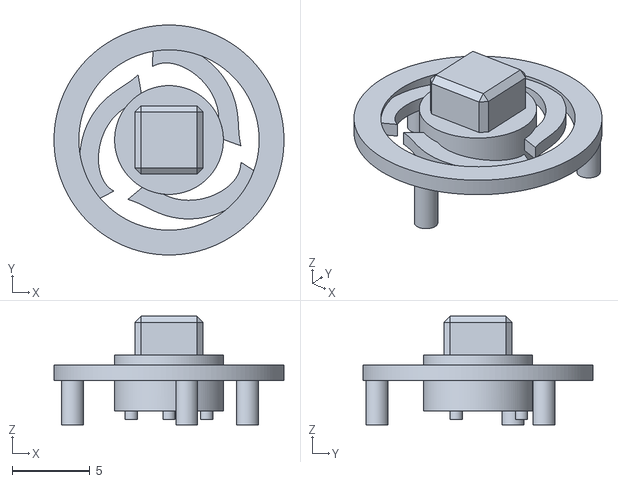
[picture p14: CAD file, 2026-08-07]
hardware/cad/models/nub_spring.stl
14.8 x 14.8 x 7.00

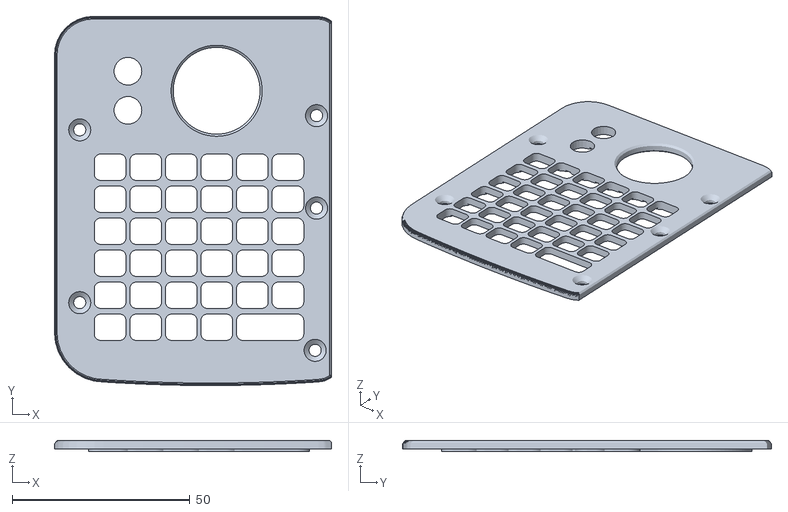
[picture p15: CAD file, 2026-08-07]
hardware/cad/models/grip_lid_left.stl
77.9 x 103.8 x 3.00

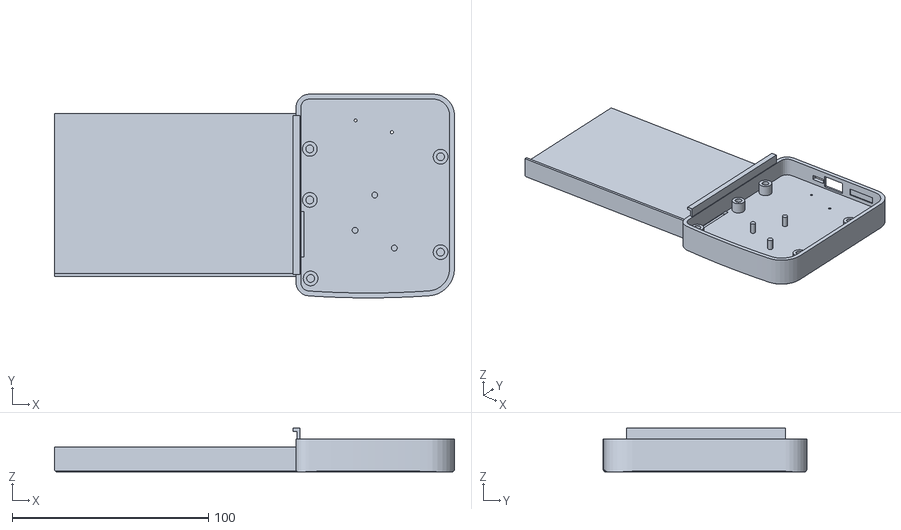
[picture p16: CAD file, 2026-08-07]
hardware/cad/models/back_right.stl
203.8 x 103.8 x 22.2

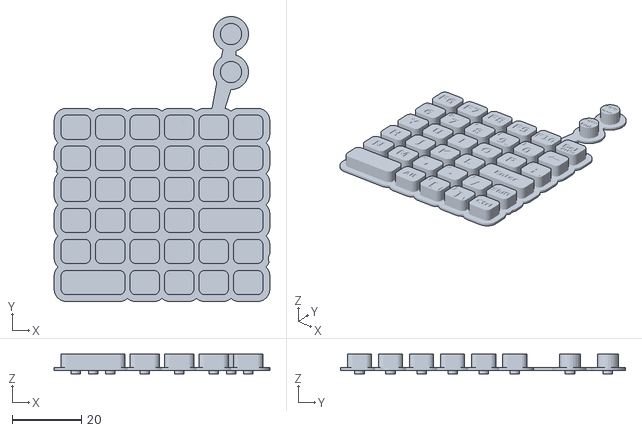
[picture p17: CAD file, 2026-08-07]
hardware/cad/models/keymat_right.stl
62.5 x 82.6 x 5.70

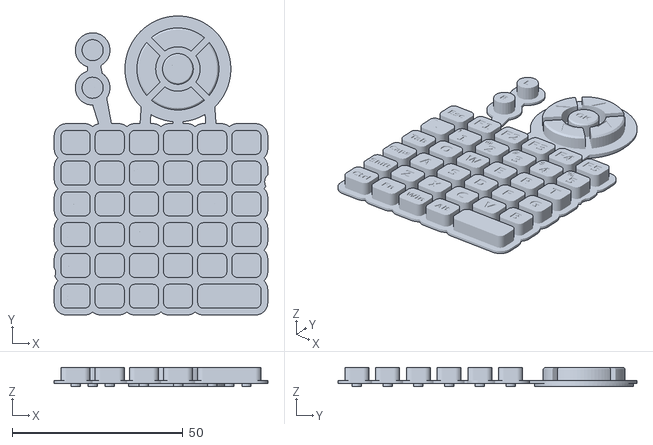
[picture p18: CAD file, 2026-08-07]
hardware/cad/models/keymat_left.stl
62.5 x 87.5 x 5.70

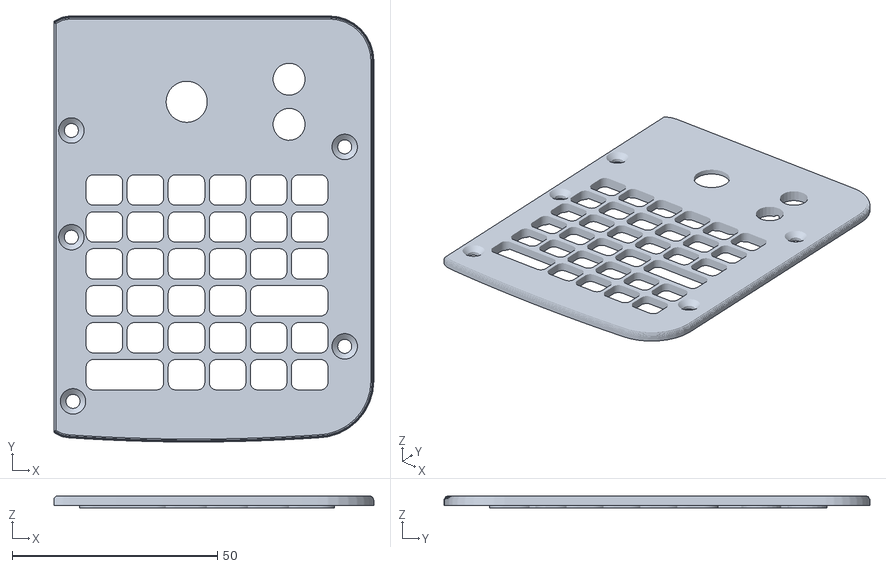
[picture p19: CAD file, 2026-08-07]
hardware/cad/models/grip_lid_right.stl
77.9 x 103.8 x 3.00

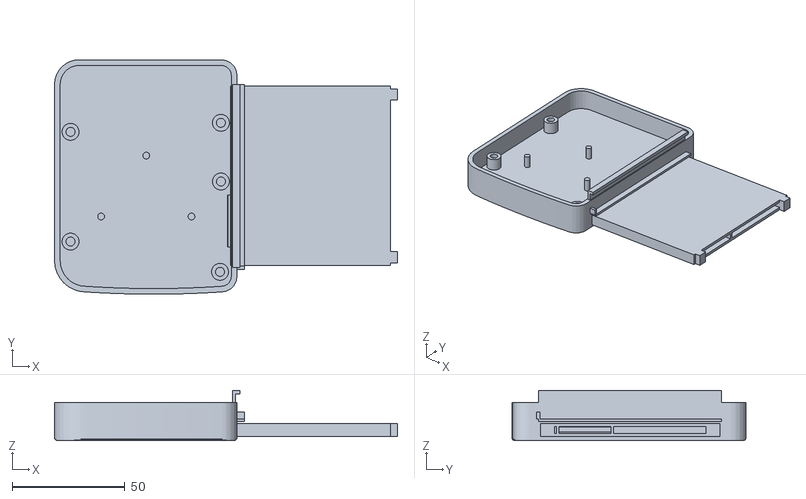
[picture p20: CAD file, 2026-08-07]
hardware/cad/models/back_left.stl
151.9 x 103.8 x 22.2

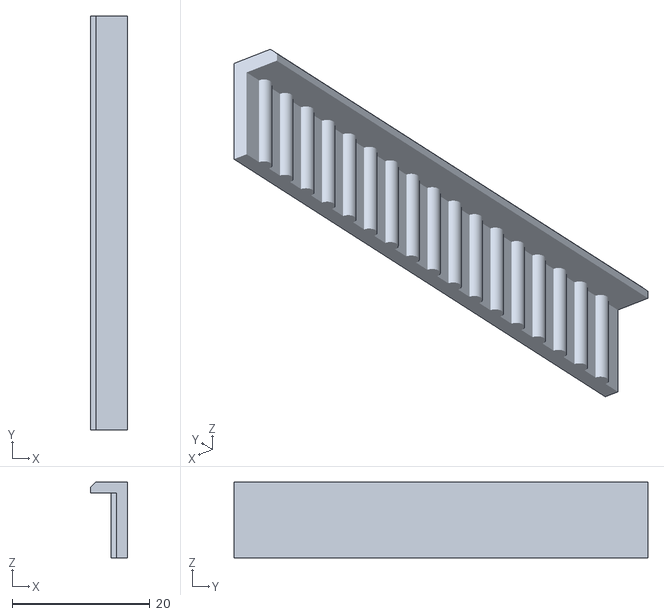
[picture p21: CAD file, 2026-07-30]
hardware/cad/models/gripper_right.stl
5.40 x 60.0 x 11.0

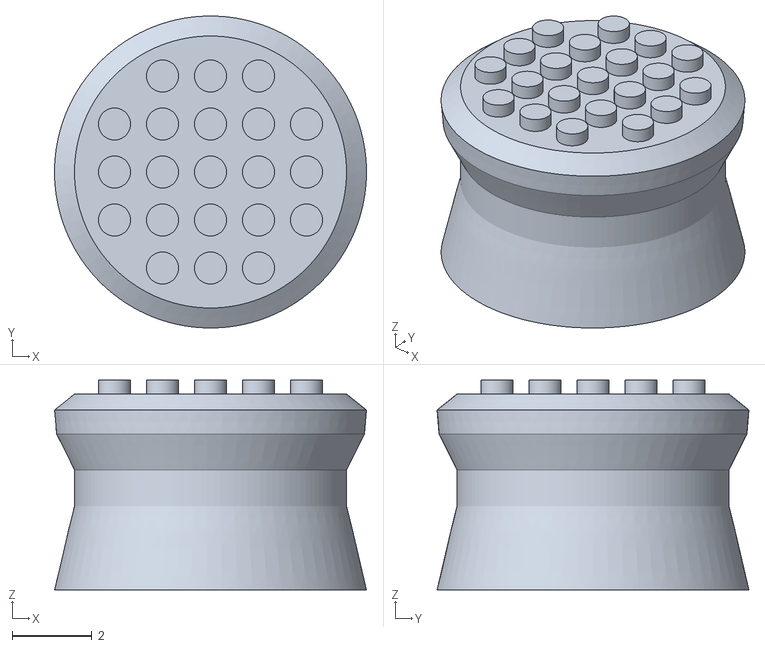
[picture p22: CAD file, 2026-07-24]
hardware/cad/models/nub_cap.stl
7.80 x 7.80 x 5.25

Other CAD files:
hardware/cad/models/gripper_left.stl

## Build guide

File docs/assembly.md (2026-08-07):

# Assembly, first flash, charge, pair & test — rev-A (v0.22)

> **This device has never been physically built.** The boards are routed and
> DRC-clean and the shells are fit-checked in CAD, but no first article exists —
> this guide is a design-derived procedure, not a walkthrough of a build that
> actually happened. Expect to find things it does not anticipate.

Both boards arrive from JLC **fully assembled** — every part is machine-placed
SMT (the v0.21 pointing nub's electronics are a single SOT-23-6 hall sensor,
U4, on the same reflow pass as everything else). There is **no soldering by
you** in this build. Your work is mechanical + one one-time SWD flash.

> **Status (superseded by the v0.19 note below):** the boards, fab package and firmware in this guide are the
> re-routed **v0.17** grip (79.5 × 97 mm; the E73 + power front-end — USB-C,
> charger, ESD, power slide switch, reset, charge LED — moved to the **top**
> zone, with the JST-PH battery connector in the bottom chin) — **unchanged in
> v0.18**. The **3D shells and keymats have been regenerated and fit-checked
> for v0.18** (flush-screen sunken tray sized for a cased Galaxy S25 Ultra;
> battery relocated into the left grip) — print from the current STLs.
>
> **2026-07-15 (Rii-follow Enter):** the right board, keymat and shells were
> regenerated for the **Rii-style 2u Enter** ending the right H-row (right grip
> now 36 keys, 78 total; `'` moved to FN+`;`), the right board rerouted
> (still 0/0) and the fab package re-exported — order from the current `fab/`
> files. The keymats now carry debossed keycap legends.
>
> **2026-07-17 (v0.19 GBC rework):** BOTH boards regenerated + re-routed for the
> boxy Game-Boy-Color outline (75.0 × 97 mm, straight outer edge) and the
> **M3 flush-countersunk** face screws; the phone well is closed (end walls +
> finger dish) and the spine is 3.9 mm wider — order boards and print shells
> from the CURRENT fab package + STLs only.
>
> **2026-08-07 (v0.27 — the battery rides the ribbon):** the bridge is now a
> **20-way** 1.0 mm ZIF and four of its conductors carry the cell, so **there is
> no separate battery power cable any more**. The battery connector moved with it:
> **J3 is gone from the right board; the cell plugs into J4 on the LEFT board**,
> ~8 mm from where it sits, through a new **F1** PPTC fuse. Two things this changes
> for you, both safety-relevant: **buy a 20-way TYPE-A ribbon, never a 16-way**
> (§0.3), and **seat the ribbon BEFORE plugging in the cell** (§2) — the power
> switch gates only the load, so the ribbon is live whenever the cell is attached.
> BOTH boards were re-routed 0/0 for this, so order from the CURRENT fab package.

## 0. Order & print

1. **Boards:** two JLCPCB PCBA orders from `hardware/kicad/generated/fab/` —
   see [fabrication-sourcing.md](fabrication-sourcing.md), including the DFM
   preview checklist (LED polarity!). That directory is **not committed**;
   generate it first with `python3 hardware/scripts/gen_fab.py` (it refuses
   unless DRC is 0/0).
2. **Prints:** six PETG shell parts — `back_left` (moving jaw), `back_right`
   (ground), `grip_lid_left`, `grip_lid_right`, the v0.24 `bridge` telescoping
   tray, and the v0.21 nub pair:
   `nub_spring` (Ø14.8 flexure; **its 3 spiral arms are the compliance coupon**
   — print one, flex it by hand, and if it feels dead-stiff or floppy retune
   `NUB_ARM_T` ±0.2 in `deck3d.py` before printing the final) and `nub_cap`
   (**RED TPU 95A**, prints with the keymats — a classic ThinkPad soft-dome
   replica; tune its 4.6 mm square socket ±0.1 to press snug on the spring's
   4.4 mm square platform — or skip it and push on any **genuine classic
   full-size TrackPoint cap**, which shares the same socket standard) — and
   the two keymats **plus the two `gripper_left/right` phone grippers** (all
   TPU 95A). STLs are tracked in `hardware/cad/models/` (or regenerate to
   `hardware/cad/build/`, STEP alongside). Every part fits a 220 × 220 bed
   (Ender 3 V2) flat; orientations + slicer notes in
   [cad-process.md](cad-process.md). Coupon-test a 3×3 keymat patch for hinge
   fatigue (>10 k presses) before printing the full mats.
3. **Order alongside:** 78+ Snaptron 7 mm domes with the taped retention array,
   a **20-way** 1.0 mm **TYPE-A** (contacts on the SAME side at both ends) FFC
   jumper, **length ≥240 mm** (v0.24) — the clamp span is now VARIABLE (the grips
   slide 130–170 mm), so the ribbon carries a **rolling service loop** that folds
   in a channel under the telescoping `bridge` tray and pays out as the jaw moves;
   it must reach at max extension (~195 mm J2-to-J2) plus the fold, so coupon-tune
   the loop radius. **20-way and type-A are both hard requirements, not
   preferences** (v0.27): this ribbon carries the battery as well as the matrix,
   and a 17 mm 16-way ribbon drops into the 21 mm housing with 4 mm of slop at each
   end — up to a 4-position shift, which the pin order survives (VBAT lands on a
   column, one dead MCU pin) only because it was designed to. There is **no
   separate battery power cable to buy any more**. Also: 2 **extension springs**
   (~5–8 N, ≥40 mm working
   extension) for the clamp force, a 1S **403040** pouch LiPo (4.0 × 30 × 40 mm,
   ~450–500 mAh, JST-PH; the footprint is a hard limit — the cell lives inside
   the **left grip**, not the spine) that **must have an integrated PCM**
   (overcurrent 2.0–2.5 A / 8–16 ms, overcharge 4.275 V, overdischarge 2.75 V —
   the board's F1 PPTC and the pack's PCM cover *different* fault bands and
   neither alone is sufficient), 0.3 mm foam tape for the cell, Ø56 N52
   **10 M3 heat-set inserts (OD ≤4.6, ~4 mm) + 10 M3×10 DIN 965
   countersunk screws** (10 grip lids) + **2 short M3** for the bridge-to-grip
   bolts. (DIN 965 = 90° countersunk flat head, flush with the face.)

## 1. Press the domes

Per grip, on the **front** (bare gold) side:

- Wipe the dome pads with IPA; don't touch the gold afterwards.
- Apply the Snaptron **retention array**: pockets locate each 7 mm dome over its
  contact ring; press each dome until it seats flat. The tape's channels vent the
  domes — don't substitute a solid film.
- Sanity-click a few domes with a meter across the centre pad ↔ ring: open at
  rest, closed when pressed.

## 2. Mechanical assembly

Order matters with the split shells: **FFC into the boards first, battery taped
into the left grip before its board, lids before panel, panel last** (it overlaps
nothing but is the seam splice + the FFC service hatch — the battery is
serviced through the left grip, not the panel).

> **v0.27 — the ribbon goes in before the cell, and that is not a preference.**
> SW90 gates only the **load**, so `VBAT_CELL` — and therefore the bridge ribbon —
> is live the moment the cell is plugged into J4. Seat and latch both ZIF ends
> first, then plug J4 (which is only in §3, after the first flash). J4 is also
> your de-energize point for any later service: **unplug J4 before touching the
> ribbon.**

1. Heat-set the **14 M3 inserts** (Ø4.0 bores): 5 per grip in each back half's PCB bosses
   and 2 per half in the panel bosses beside the x=0 seam (all Ø4.0 bores).
   *(The two ring-height spine anchors are gone in v0.18 — the panel takes 4
   border screws only.)*
2. **FFC jumper first:** with the boards loose, open both ZIF latches and seat
   the ribbon (**20-way**, ≥240 mm, type-A), **contacts facing the board at both
   ends** (the ZIFs are bottom-contact and the jumper is type-A/same-side — a
   straight ribbon is correct by construction; do not twist it). Push it fully
   home against both ends of the 21 mm housing and check it is **square in the
   slot with no conductor over-hanging either end** before closing the latches:
   since v0.27 four of these conductors are the battery, and a ribbon seated a few
   positions over is a fault, not a dead key. Close the latches. The
   ZIFs are unreachable once the lids are on. The ribbon will later fold into a
   **rolling service loop** inside the telescoping `bridge` tray that pays out as
   the clamp jaw slides (step 6).
   Note the ribbon does **not** leave the ZIF toward the spine. Since v0.27 the
   slot faces **inboard**: the ribbon runs a short way into the grip, folds down
   through the back cavity, then doubles back at low level and out through a duct
   under the phone cradle into the tray lane. Seat the fold before the lid goes on
   — it is a static crease, not a moving one (the rolling service loop lives in the
   tray). `deck3d.py --check-lanes` verifies the whole path is clear.
3. **Battery — polarity check first, cell NOT connected yet.** Since v0.27 the
   cell's connector is **J4 on the LEFT board** (there is no J3 — the right board
   lost its JST when the battery stopped crossing the spine). Vendors wire
   JST-PH pigtails **both ways**: meter the pack pigtail and confirm the red/+
   wire lands on the pin marked **"+"** on the back silk beside **J4** — that is
   **pin 1** ("−" marks pin 2); the silk also carries `BAT`, and `F1 PPTC 0.75A`
   labels the fuse sitting in series with that positive line. Foam-tape
   (0.3 mm) the 403040 cell to the **left** grip's floor where it will sit
   under the passive PCB — only the left cavity has the headroom — and dress its
   short pigtail along the chin to J4, ~8 mm away in the same cavity. Nothing
   crosses the spine any more. Leave the cell
   **unplugged** and the power switch **OFF** — it is connected only *after*
   the first flash (§3); see the REGOUT0 warning there.
4. Drop each board in, **parts down**, onto its perimeter bosses + the **3
   support posts** under the key field. On the **left**, the board goes in
   over the cell (~0.8 mm clearance under the diodes at nominal) — check the
   pigtail reaches J4 in the chin cleanly and nothing is pinched. Check the USB-C sits in its wall
   opening, the slide-switch knob reaches its slot, and the reset tact + LED
   align with the floor pinhole + light hole. *(v0.17: the USB-C opening and
   slide-switch slot are in the TOP shell wall, the reset pinhole + charge
   light-hole in the floor near the top zone — the shells were regenerated and
   fit-checked for this layout on 2026-07-14.)*
5. Lay the keymats over the domes and fit each **grip lid** (its rim lightly
   clamps the keymat web); drive the **5 M3×10 countersunk screws per grip** — heads finish flush with the face.
6. **Cable the tray + join the grips (v0.24):** the two grips no longer meet at
   x=0 — they're bridged by the telescoping tray. Lay the FFC into the `bridge`
   tray's enclosed channel with a **rolling service loop** (a U-fold that pays out
   as the jaw slides). Since v0.27 it is the **only** cable in there — one lane
   between the two springs, walled off from both by printed divider ribs, so keep
   the fold inside its channel and it cannot reach a coil. Bolt the `bridge` to the **right
   grip** (the ground member) with its **2 short M3s** into the cradle bosses,
   then engage the **left grip's inner shroud** into the open left end of the
   tray so it laps inside (it stays overlapped 57→17 mm across the travel, so the
   springs and the FFC stay enclosed at every width). Hook the **2 extension
   springs** from the tray's fixed anchors to the inner shroud's hooks — these
   are the clamp force. Leave the battery unplugged at J4 for now.
7. **Pointing nub (v0.21):** three steps, all on the right lid.
   **(a) Magnet:** press the Ø4 × 2 N52 disc into the `nub_spring` hub pocket
   **N pole facing down** (toward the sensor). Find N BEFORE seating, with a
   compass: **the disc face that attracts the needle's SOUTH end (the
   unpainted/white end) is the N face** — seat that face down. The driver
   zero-calibrates at boot but cannot fix a flipped magnet (both axes invert
   and the offset range is wrong). It's a press fit; a drop of CA if loose.
   **(b) Spring:** stand the spring on the bare PCB zone under the aperture —
   its 3 legs on the board's front face, magnet down over the sensor — then
   lower the lid over it so the square cap platform rises through the Ø10
   aperture and the underside counterbore captures the flange. Driving the lid screws presses
   the counterbore ceiling onto the flange (0.05 mm preload against the legs):
   the spring is clamped rigid, no adhesive. If it can rattle after screwing
   down, a print tolerance ate the preload — shim the counterbore with a strip
   of tape rather than glue.
   **(c) Cap:** with the lid screwed down, press the cap — the printed red
   replica or a genuine classic TrackPoint cap — onto the 4.4 mm square
   platform, exactly like re-capping a ThinkPad. It pulls off for lid
   removal — pull straight up, don't lever.
   First power-up: leave the nub untouched for the first ~2 s (32-sample zero
   calibration); axis flips/swaps are DT properties in `thumbdeck.dts`, not
   code.
8. **Grippers (v0.24):** **slide** the two **TPU grippers** in from the
   **y end of each cradle, under the rigid retainer** — they are trapped by it, not
   pressed on, so don't push them straight in from the front and don't glue them. **Teeth face the phone** (half-round ribs down the pad's inner
   face — they bite the cased edge so the phone can't creep or rotate; a gripper in
   backwards will hold, badly, and is the first thing to check if the screen won't
   stay square). The gripper is **biased toward the bottom** of the cradle, not
   centred — once the bottom shelf datums the phone by its lower long edge, a
   centred pad would miss the bottom of every short phone. Push it down against the
   shelf end of the slot. **v0.24e:** the **TPU lip** is what retains the phone — it
   stays soft so it can flex for thicker cases and can't scratch cover glass; the
   shell's retainer only stops the gripper peeling off and never reaches over the
   screen. **Don't run without a gripper** — there is no rigid backup over the phone.
   Retention is **mechanical**, so the deck is safe used screen-down. To fit a phone:
   pull the jaws apart, **seat one short edge under its lip first**, then push the
   other edge in — it will not drop straight down past both lips. To remove, hold the
   jaws open and lift the phone **up over the 3 mm bottom shelf**; the lip undersides
   are deliberately square and won't cam the phone out, which is the same reason it
   can't fall out. **Very thick cases:** compliance is only what the TPU lip can flex,
   so a chunky rugged case may push the lip aside and lose positive capture — check the
   phone can't be lifted straight out before trusting it screen-down. Then
   (v0.25: there is no MagSafe ring any more — retention is entirely the spring clamp,
   the toothed TPU grippers and the capture lips.)
   the battery means opening the **left grip** (5 screws, lid, keymat, board).

## 3. First flash (one-time SWD, then UF2 forever)

The E73 ships **blank** — it cannot be UF2-flashed out of the box.

> **Order matters — first power-up must be battery-free.** Until `UICR.REGOUT0`
> is programmed to 3.3 V, the nRF's I/O rail runs at its **1.8 V** default, and a
> full 4.2 V cell would put the battery divider's **2.1 V on AIN0 — exactly the
> pin's absolute-maximum rating**. So: battery switch OFF and cell unplugged,
> power from USB or the SWD probe only, flash the bootloader (which programs
> REGOUT0 = 3.3 V), and only *then* connect the cell.
>
> **v0.27: "battery-free" now means J4 unplugged, on the left board.** The switch
> alone will not do it — SW90 gates the load, not the cell, so with J4 mated the
> ribbon and the charger see the cell whatever the knob says. That is also exactly
> why J4 exists on the board the cell lives in.

1. Connect an SWD probe (J-Link, CMSIS-DAP, or a Raspberry Pi with OpenOCD) to the
   silk-labelled pads **TP1–5**: SWDIO, SWDCLK, RESET, 3V3, GND. Power the board
   from **USB or the probe's 3V3 only** — cell unplugged, switch OFF.
2. If the part arrives access-protected: `nrfjprog --recover` (or the OpenOCD
   equivalent) first.
3. Flash the **Adafruit nRF52 bootloader — nice_nano build** (that build matches
   this board's flash layout; the board itself is *not* a nice!nano). The
   bootloader sets `UICR.REGOUT0 = 3.3 V`, which the LiPo-direct power scheme
   requires — verify the flash completed before going further.
4. **Now connect the cell at J4** (polarity already metered in §2; the ribbon is
   already seated and latched at both ends) and switch ON —
   **ON = knob toward the USB-connector end of the board**.
5. From now on it's drag-and-drop: **double-tap reset** (paperclip in the floor
   pinhole) → a UF2 drive mounts → drag on `thumbdeck-zmk.uf2` from the GitHub
   Actions build (`.github/workflows/build.yml`, self-contained ZMK v0.3.0).
   That build is green (run 29443394494, 2026-07-15) so the artifact does exist —
   but **it has never been flashed to hardware, because no hardware exists.**
   Actions artifacts also expire, so re-run the workflow and use a fresh build
   rather than an old download.

## 4. Power-on checkpoints

1. Switch ON (knob toward the USB end of the board): BLE advertising should start
   (see the host's scanner). Idle draw on
   a bench meter: single-digit mA advertising, dropping toward µA in deep sleep.
2. Plug USB-C: the **charge LED** in the floor lights; it goes out when full.
   The cell also charges with the switch OFF (charger is on the cell side).
   Never charge unattended.
3. First battery reading on the host should be plausible (÷2 divider on AIN0).

## 5. Pair & test

- Pair the host to **"thumbdeck"**. There is no inter-half pairing — the left grip
  is wired, not a BLE peer.
- Type across **both** grips. Debug map: a dead left-grip **column** → reseat the
  FFC ribbon; a dead **row** affects **both** grips (rows are shared).
- **Modifiers are mirrored** (v0.20): both grips end in the same stack — Ctrl at
  the bottom-outside corner, Shift directly above it, Alt beside Space. Hold the
  modifier with the thumb OPPOSITE the target key (Ctrl+C = right-thumb Ctrl +
  left-thumb C). No sticky/one-shot behaviors — everything is a plain hold;
  same-side triples (Ctrl+Shift+letter) use the corner Ctrl+Shift one-thumb
  bridge or a quick cross-hand reach.
- **FN layer** (hold FN, left grip): MINUS/EQUAL on 0/9, HOME/END on PgUp/PgDn,
  PSCRN on DEL, **SQT (`'`) on `;`** (the apostrophe has no physical key — the
  right H-row ends in the 2u Enter), **PIPE (`|`) on `[` and BSLH (`\`) on `]`**
  (the backslash cap became the right Ctrl in v0.20), `BT_CLR` + `BT_SEL 0–3`
  for profiles, plus `&bootloader` / `&sys_reset`.
- Pointer: nudge the **nub** — the cursor should track, faster with steeper
  deflection (rate control). **Hands off the nub for the first ~2 s after
  power-up** (zero calibration). If an axis is mirrored or swapped, set
  `invert-x` / `invert-y` / `swap-xy` on the `nub` node in `thumbdeck.dts` —
  a first-article calibration, not a code change. FN-layer mouse keys on the
  D-pad remain as a fallback pointer.
- Chord several keys at once — the diodes kill ghosting (verified exhaustively in
  `sim_matrix.py`, but enjoy confirming it with fingers).

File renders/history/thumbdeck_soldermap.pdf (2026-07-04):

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

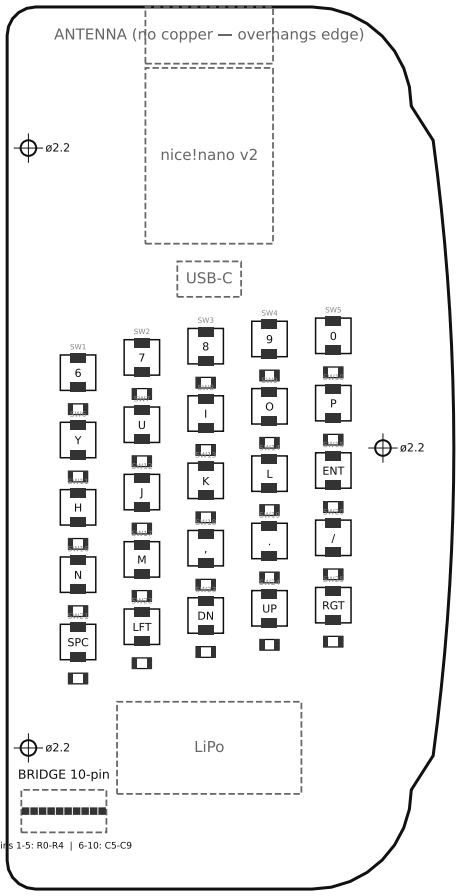
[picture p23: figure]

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

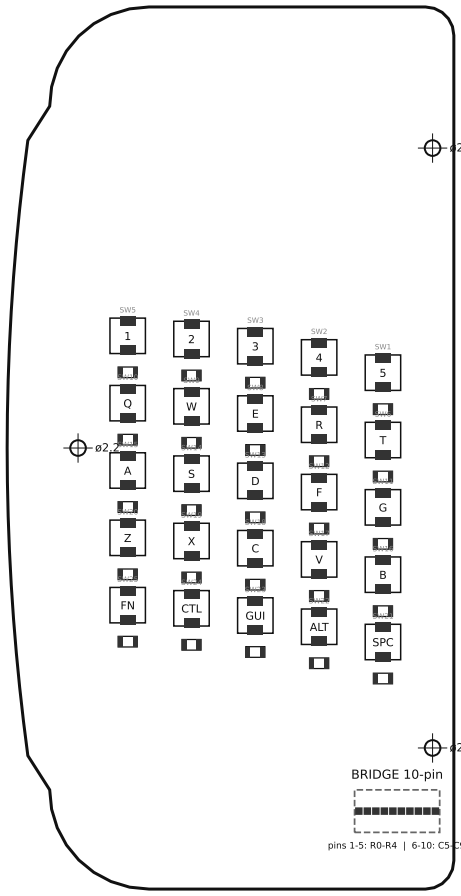
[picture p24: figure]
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

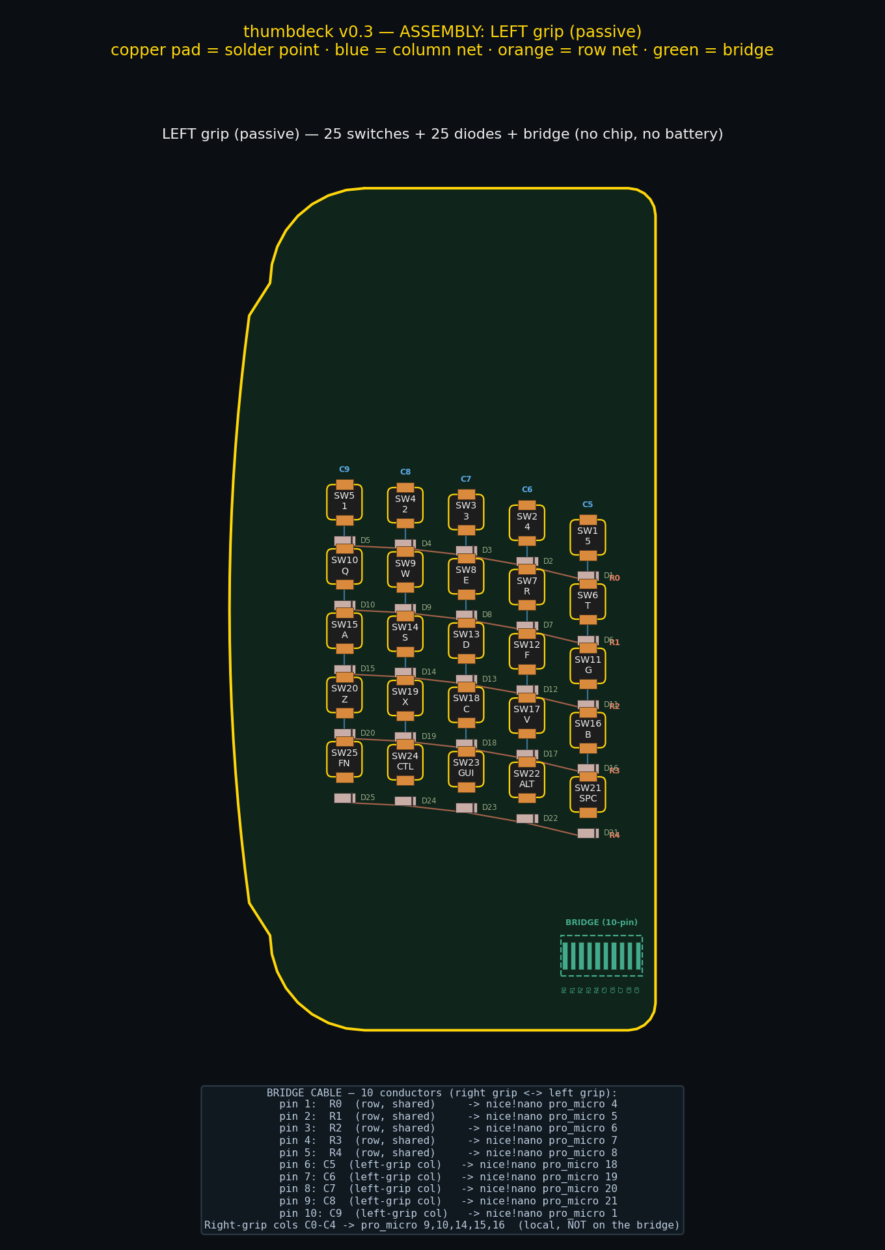
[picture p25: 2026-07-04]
renders/history/wiring_assembly_left.png

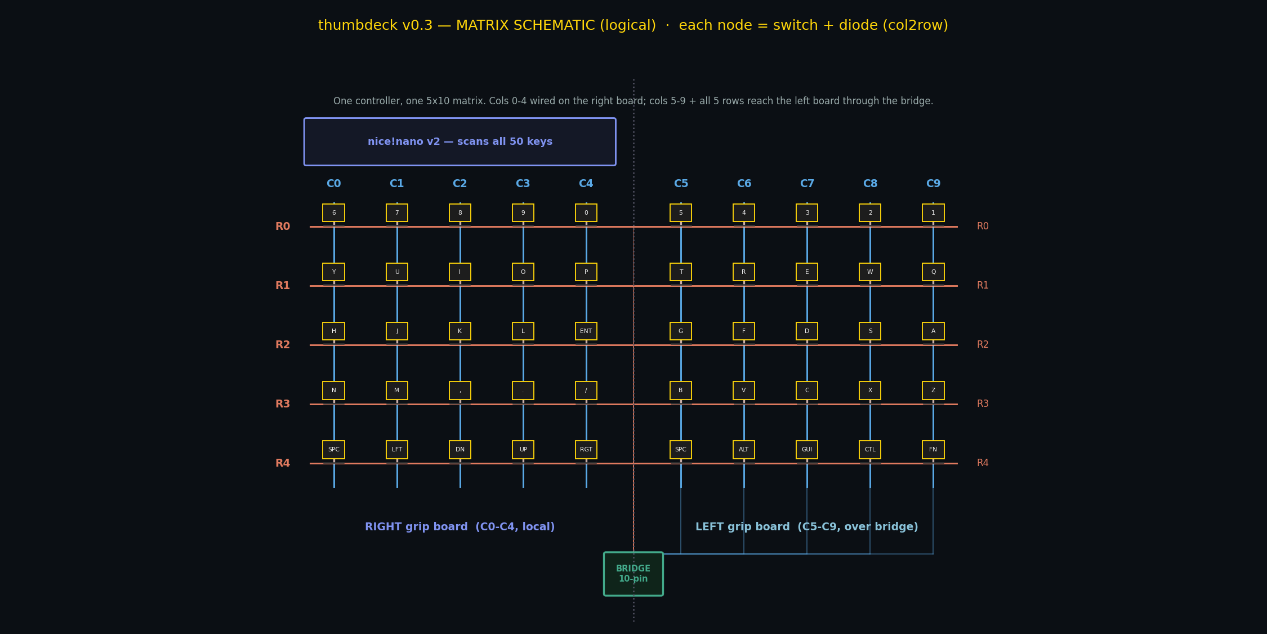
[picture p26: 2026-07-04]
renders/history/wiring_schematic.png

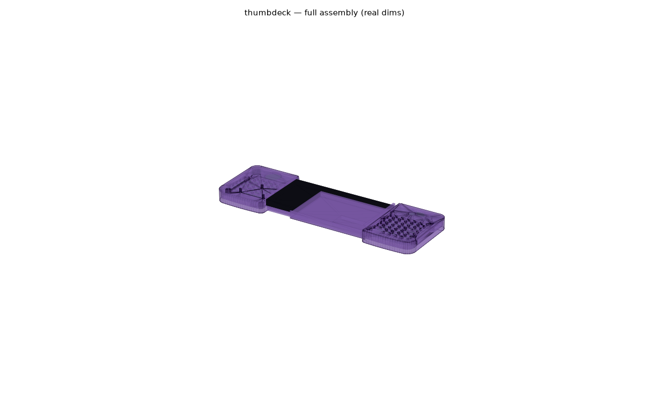
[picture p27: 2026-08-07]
renders/assembly3d.png

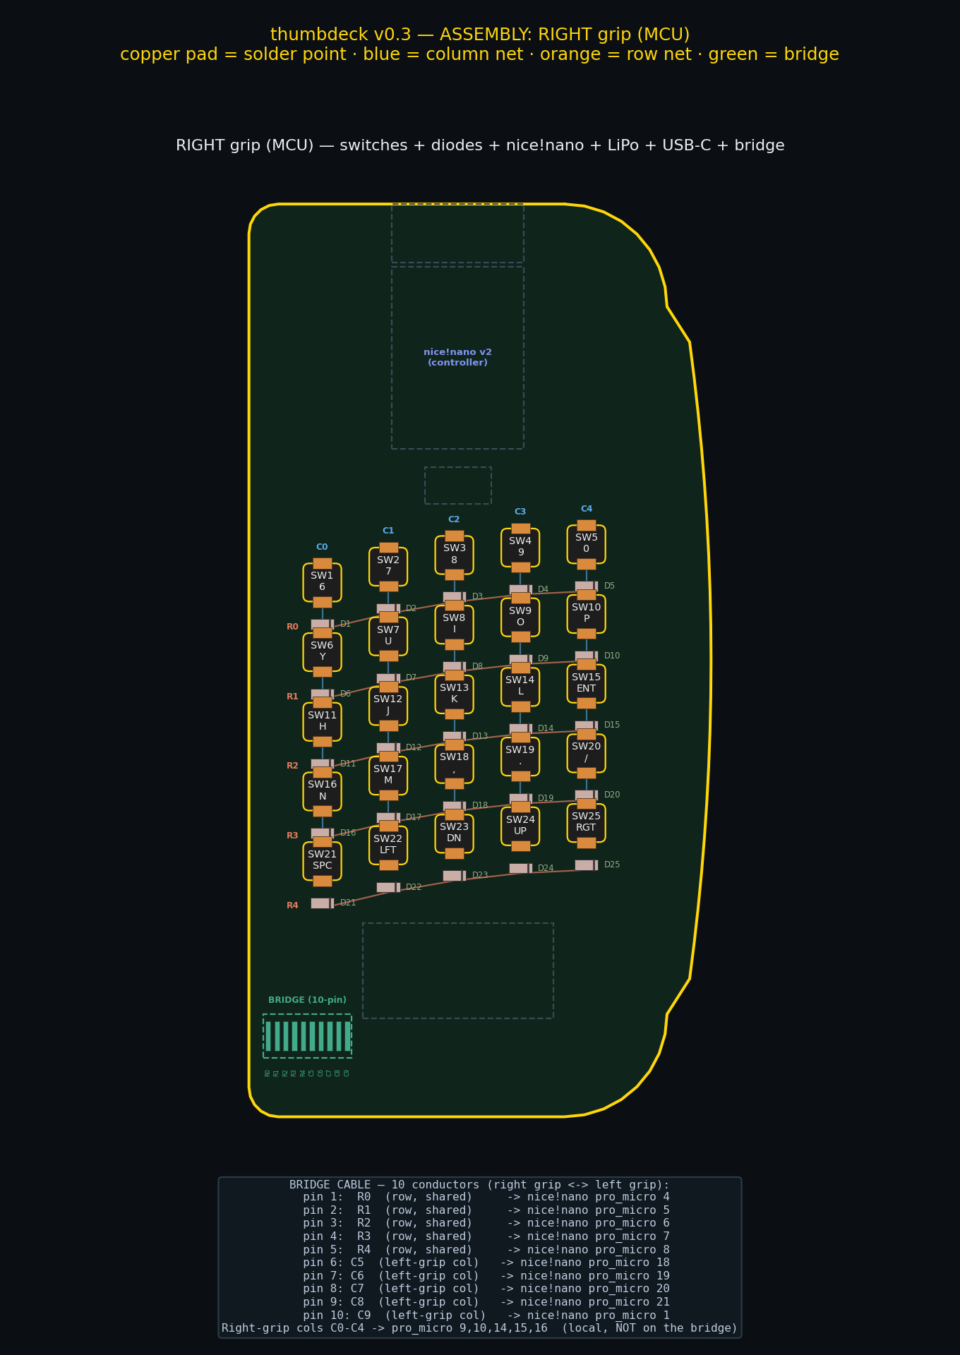
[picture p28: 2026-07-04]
renders/history/wiring_assembly_right.png

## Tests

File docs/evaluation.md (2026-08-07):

# Gripster — fab-readiness evaluation (rev-A, v0.27, 2026-08-07)

Authoritative status of the design's readiness to be produced. Supersedes the
v0.14 evaluation and all older review notes. Where any other doc disagrees with
this file or the code, **this file and the code win.**

Method: the v0.14 6-lens audit (matrix, power/USB, module pinout, footprints,
firmware, mechanical/RF) followed by the rev-A **8-dimension audit** (120
findings, 14 blockers — see [design-review.md](design-review.md)), cross-checked
against official datasheets (Ebyte E73 User Manual, ST USBLC6-2, Microchip
MCP73831, Snaptron), an exhaustive matrix-ghosting simulation, and the headless
KiCad-9 + Freerouting pipeline with a DRC gate.

---

## Verdict

**rev-A is fab-ready: routed, DRC-clean, fab package exported, firmware fixed,
mechanicals fit-checked. It is unverified in physical hardware.** Order a
first-article run of 5 and run the bring-up checkpoints in
[assembly.md](assembly.md) before any larger spend.

## What is PROVEN (machine-verified this pass)

| Item | Evidence |
|---|---|
| **Routing + DRC** | Both boards **0 violations, 0 unconnected** (kicad-cli 9.0.9, error severity) — `hardware/kicad/generated/drc_{right,left}.json`. **Re-routed from scratch 2026-08-07 for v0.27**'s 20-way bridge: right 75 nets / 114 footprints / 30 GND escape vias, left 60 nets (was 58 — VBAT_CELL and VCELL_RAW are new there). Two v0.27 notes worth carrying: (a) `route.sh` now injects a real `power` netclass into the DSN, so `VBAT_CELL`/`VBAT` route at **0.4 mm** instead of signal width — `gen_board.py`'s `PWR` constant had never been applied to anything and `VBAT_CELL` had been shipping at 0.2 mm (~336 mΩ, a third of the charge loop); (b) 0.5 mm was tried and **does not converge** (Freerouting leaves `VBAT_CELL` open through the inner corridor), and the 20-way connector needs **100 passes** where the 16-way closed in 30. |
| **Fab package** | `gen_fab.py` (hard-gated on clean DRC) exported 4-layer gerbers + JLC BOM/CPL for both boards to `hardware/kicad/generated/fab/`. |
| **E73 module pinout** (the silent killer) | `E73_PINMAP` matches the official Ebyte pin table 1:1; footprint pad N = datasheet pin N. VDDH=cell, VDD=REG0 output, USB D±=29/31, SWD=37/39, RESET=26, VBUS=27, VBAT_SENSE=AIN0, **COL9 on P0.04 (XTAL pins free)**. |
| **Power architecture** | High-voltage mode: cell → charger(cell side) → SW90 → VBAT → VDDH(23); VDD(19) = internal REG0 3.3 V output, never driven; module has no DCDC inductors → LDO mode, matching the firmware config. **v0.27:** topology unchanged, but the cell now terminates in its own grip — **J4** (JST-PH) on the LEFT board, through **F1** (Bourns MF-MSMF075-2 PPTC, C84140, 0.75 A hold) — and reaches the charger over the ribbon. **J3 is deleted from the right board.** F1 and a **protected** pouch are both required and cover different fault bands: the pouch's PCM trips at 2.0–2.5 A, an FFC conductor cooks its own PET at ~2.8 A·√s, and the 0.43–2.0 A gap between them is what F1 exists for. Charge-termination cost of the added series R is ITERM × Rloop ≈ 10–16 mV — negligible against the MCP73831's own ±32 mV VREG tolerance; the real cost is charge *time*. |
| **Matrix / NKRO** | `sim_matrix.py` (final pass, re-run 2026-07-24 on the v0.22 boards): **78 unique (row,col) keys (right 36 + left 42), 0 cross-grip collisions, 0 ghost/miss failures** over ~68,500 scenarios; the no-diode control ghosts ~35 k× (sim detects ghosting). The v0.21 nub is I²C — it adds no matrix key. |
| **USB** | CC1/CC2 5.1 k pulldowns; USBLC6-2SC6 **inline**, D+=pins 1&6 / D−=pins 3&4 per ST datasheet; interleaved data pads joined by deterministic generated copper. |
| **Charger** | MCP73831-2ACI, PROG 5.1 k → ~196 mA (~0.43 C @ the 403040 cell's ~450–500 mAh); 4.7 µF 0805 25 V at both supply and cell nodes, at the chip. |
| **Bridge correctness** | Left-grip FFC nets assigned by ribbon geometry; verified net-at-same-height matches 1:1 → a straight type-A jumper is correct by construction. **v0.27:** the bridge is **20-way** (AFA07-S20FCC-00 / C262352) and carries the cell as well as the matrix — 2 × GND, 14 matrix, 2 × VBAT_CELL, 2 unwired NC guards. The 14 matrix signals are byte-identical to v0.22, so firmware is untouched. Conductor order is a safety interlock: GND sits **15 positions** from VBAT_CELL, so even the 4-position mis-seat that a legacy 17 mm 16-way ribbon permits in a 21 mm housing lands VBAT on a column (one dead MCU pin), not on GND (a cell short). |
| **Footprints** | Production `snaptron_7mm_contact` (ring + 67.5° escape gap, pour/via keepouts); E73 43-pad land pattern with embedded antenna keepout; v0.21 adds only a stock SOT-23-6 (TMAG5273 hall sensor) — **everything is single-pass SMT, zero hand-soldered parts**. |
| **Board outline / mounts** | Closed, non-self-intersecting, **75.0 × 97.0 mm** (v0.19 GBC-boxy: straight outer edge, r8/r11 corners, 1.0 mm bottom crown); **5× M3** per grip clear of keep-outs (bbox-gate ≥4.0). |
| **Mechanical fit** | `deck3d.py --check` **re-run on v0.27 geometry (2026-08-07)**: **221 bodies, 0 clashes** (345 AABB-overlapping pairs) at **all four clamp spans** (min 130 / nominal / max phone 170 / open 179 mm), with the cable run reported **SEALED** at every one. Nub gap re-verified at **3.33 mm** (band 3.05–3.65) and retention at a 3.0 mm lip overhang. **v0.27 added the FFC duct that never existed**: the ZIF slot sits at z ≈ 6.95 and the enclosure lane at z = 0.2, and until now the ribbon had 1.20 mm of x in which to lose 6.74 mm of z — i.e. no physical route, in any version. J2 was rotated to face **inboard** and a low **stepped** duct cut at **z −0.8 .. 2.6** on the grip side and .. 1.95 through the moving shroud (a straight 2.6 cut left that shroud's roof 0.55 mm thick; stepping it restores **1.42 mm**), which passes *under* the whole phone-retention structure (cradle backstop wall, rest ledge and bottom shelf all sit at z ≥ 3.9) rather than through it. The descent is dimensioned with a **1.6 mm bend-radius** allowance and asserted to clear the innermost matrix diode by **0.98 / 1.03 mm**. `flex_route_report()` sweeps the ribbon's **full 21 mm section** (not its centre line — v0.24e's recorded lesson) against the built shell solids and **gates**: `--check-lanes` exits non-zero, `--check` asserts. `--check-lanes` (~15 s, since it builds both back halves to sample against) also asserts `FLEX_Y` equals J2's *placed* y and that ribbon width matches pin count via the exact AFA07 land = N+6.85 / ribbon = N+1 identity — the 2.0 mm skew those two had silently carried since v0.24d is what motivated the assert. Every part still bed-gated. |
| **Firmware buildability** | 5 build-breakers fixed (v0.3.0 pin, pointing.h include, DCDC removed, LF-RC clock, exact Adafruit/nice!nano-v2 flash partition layout); board definition at `config/boards/arm/thumbdeck`; CI = a **self-contained ZMK v0.3.0 build** (`west init -l config` inside `firmware/zmk-config`, `west build -b thumbdeck`, uploads `thumbdeck-zmk.uf2`) — ZMK's reusable workflow cannot handle a nested config dir. **CI is STALE for v0.21**: the last green run (29443394494, 2026-07-15, commit `d1ef751`) predates the nub — v0.21 adds the `tmag5273_nub` module, the `&i2c0` node and the `-DZEPHYR_EXTRA_MODULES` build flag, none of which that run compiled. **Re-run the workflow and get green before ordering boards.** It has never been flashed — no hardware exists. |

## What is NOT yet verified (needs the physical prototype)

1. **RF range** with the phone mounted and hands on the grips (antenna is
   edge-mounted with keepout + shell relief — the relieved top wall is in the regenerated v0.19 shells (closed, 1.9 mm over the antenna span); only a range test proves it).
2. **Dome feel** through the printed keymat, hinge fatigue life, retention-tape
   behaviour over thousands of cycles.
3. **Real charge curve + idle/sleep current** on the assembled board.
4. **JLC's actual part rotations** (LED/SOT-23/E73) — controlled by the DFM
   preview checklist, confirmed only at delivery.
5. **The firmware on real silicon — and, for v0.21, the compiler itself.** The
   last green CI run (29443394494, 2026-07-15) predates the nub module; the
   v0.21 firmware (tmag5273_nub, i2c0, PM hooks) has NOT yet been CI-built —
   push the branch and re-run the workflow first. Beyond that, everything past
   the compiler is unverified: the image has never been flashed,
   the matrix has never been scanned, and the pin map, kscan timing and power
   config have only ever been checked by eye against the datasheet. **A clean
   build is not a working keyboard.** Re-run the workflow before ordering so the
   artifact you flash matches the tree you built from.

## Standing constraints

- **E73 C356849:** Extended + X-ray + **volatile stock** (observed from ~1000 down
  to ~20 units within days) — check jlcpcb.com/parts and reserve/backorder the
  modules before anything else (the Holyiot 18010 backup requires a footprint
  change, rev-B); forces Standard assembly for the right board.
- **ENIG mandatory** (dome contacts) — never accept a HASL default.
- **Two separate JLC orders** — do not panelize the two designs.
- The E73 ships blank: first flash is **SWD via TP1–5** (Adafruit bootloader,
  nice_nano build), then UF2 forever.

## Reproduce

```bash
cd hardware/scripts
python3 gen_board.py                  # placement + netlist + fixed USB copper + GND escape vias
./route.sh right && ./route.sh left   # Freerouting -> stitch -> DRC gate -> renders
python3 gen_fab.py                    # fab package (refuses unless DRC 0/0)
python3 sim_matrix.py                 # 78-key ghosting/NKRO proof
python3 gen_firmware.py               # regenerate the ZMK board files from the model
cd ../.. && hardware/cad/.venv/bin/python hardware/cad/deck3d.py --all --check
```

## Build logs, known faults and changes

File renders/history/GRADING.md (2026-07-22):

# Grading system & iteration log — HISTORICAL (v0.4 era, superseded)

> **Historical record.** This describes the v0.4 auto-grader for the abandoned
> **50-key nice!nano** design. None of it reflects rev-A / v0.19 (78 keys, one
> E73 module, routed 4-layer boards) — the "PASS" verdict below is a pass of that
> old geometry/config grader, **not** a statement about the current design or
> about any physical hardware. Current status lives in
> [`docs/evaluation.md`](../../docs/evaluation.md); the scripts referenced below
> are archived in `hardware/scripts/legacy/`.

Two gates, enforced by `hardware/scripts/legacy/final_grade.py`. Done only when
both pass. As of v0.4 the grade also encodes the **EE design-review** findings
(see `../../docs/design-review.md`) so the design is held to them, not just
reminded of them.

> Scope caveat: the grade covers **geometry + config/doc structure**. It is *not*
> electrical sign-off — no compile, no DRC/ERC, no RF sim. Passing is necessary,
> not sufficient. Human-verified fab gates are listed in the design review.

## Gate 1 — functional grade (`grade.py`, 27 checks)

HARD checks (●) block the pass regardless of score. Pass = no hard fails and ≥90%.

**Geometry** F1 keys=25/half ● · F2 no overlap ● · F3 true mirror ● · F4 thumb arc ·
F5 keep-outs clear ● · F6 inner mount holes · F7 envelope · F-usb USB present ·
**F-antenna** RF keep-out overhangs edge + ≥10 mm from LiPo + clear of keys ● ·
F-bridge connector on both inner edges ● · F-role right=mcu(+antenna)/left=passive ●

**Firmware** F8 5×10 transform=50 ● · F8b 25+25 grips ● · F8c keymap 50 ● ·
F9 nice!nano pins valid ● · F10 BLE+USB+battery ● · F11 build.yaml ● · F12 col2row ·
**F-si-debounce** kscan debounce ≥6 ms ●

**Docs/BOM (EE review encoded)** F-si-passives row pull-downs + column series R ● ·
F-esd-tvs TVS on bridge/USB ● · F-charge charge-current vs cell noted ● ·
F-switch-verify meter the pinout ● · F-si-doc matrix doc SI · F-review-doc
design-review.md + FMEA ● · F-bringup bring-up + current checkpoints ● ·
F-fab-gates README gates fab on schematic+ERC+DRC ●

## Gate 2 — visual grade (`renders/visual_scores.json`, 9 items)
Silhouette, mirror, key field, thumb arc, bridge/Backbone interface, keep-outs by
role, silk legibility, envelope, **+ V9 antenna overhang**. Computable items are
also verified numerically in `grade.py`.

## Iteration log

| phase | iter | result | key change |
|---|:---:|---|---|
| v0.2 two-controller BLE split | 00→03 | PASS (16/16, 8/8) | converged split layout; left legends fixed |
| v0.3 single controller + wired bridge | 05 | PASS (17/17, 8/8) | one nice!nano; passive left; bridge connector |
| **v0.4 EE-hardening** | 06 | 92.6% → **PASS (27/27, 9/9)** | antenna keep-out (F-antenna), bridge SI (debounce + BOM pull-downs/series-R/TVS), charge-current, metering + bring-up + ERC/DRC gates. Fixed: antenna/controller touching edge (float overlap) → 0.6 mm gap; `series res` substring in BOM check |

## Final verdict (v0.4, iter 06)

```
FUNCTIONAL : 100.0%  (27/27)  hard-fails: none   -> PASS
VISUAL     : 9/9 checklist items                 -> PASS
OVERALL    : *** PASS ***
```

Reproduce: `cd hardware/scripts/legacy && python3 ../layout_gen.py --iter 6 && python3 final_grade.py --iter 6`

**Kept renders:** `iter_03.png` (v0.2), `iter_05.png` (v0.3), `iter_06.png` (v0.4 final).

## What the grade still does NOT prove (human gates — `../../docs/design-review.md`)
Compile (ZMK CI), DRC/ERC, RF performance, the metered switch pinout, mechanical
flex, and the real bridge-cable flex life. Those gate a fab order; the grade doesn't.

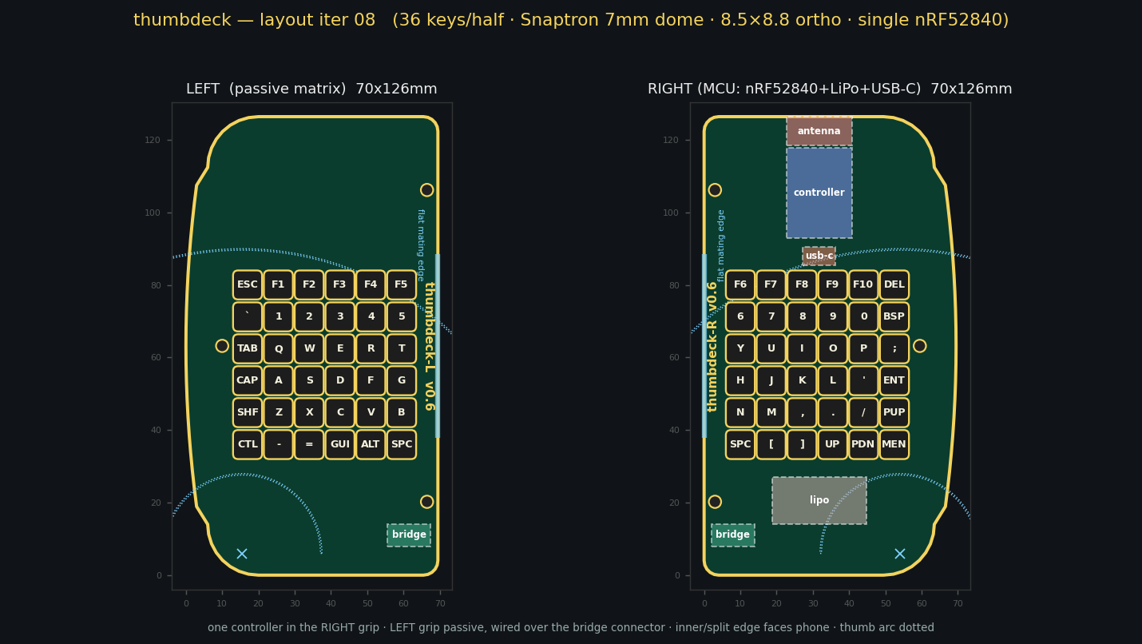
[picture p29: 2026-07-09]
renders/history/iter_08.png

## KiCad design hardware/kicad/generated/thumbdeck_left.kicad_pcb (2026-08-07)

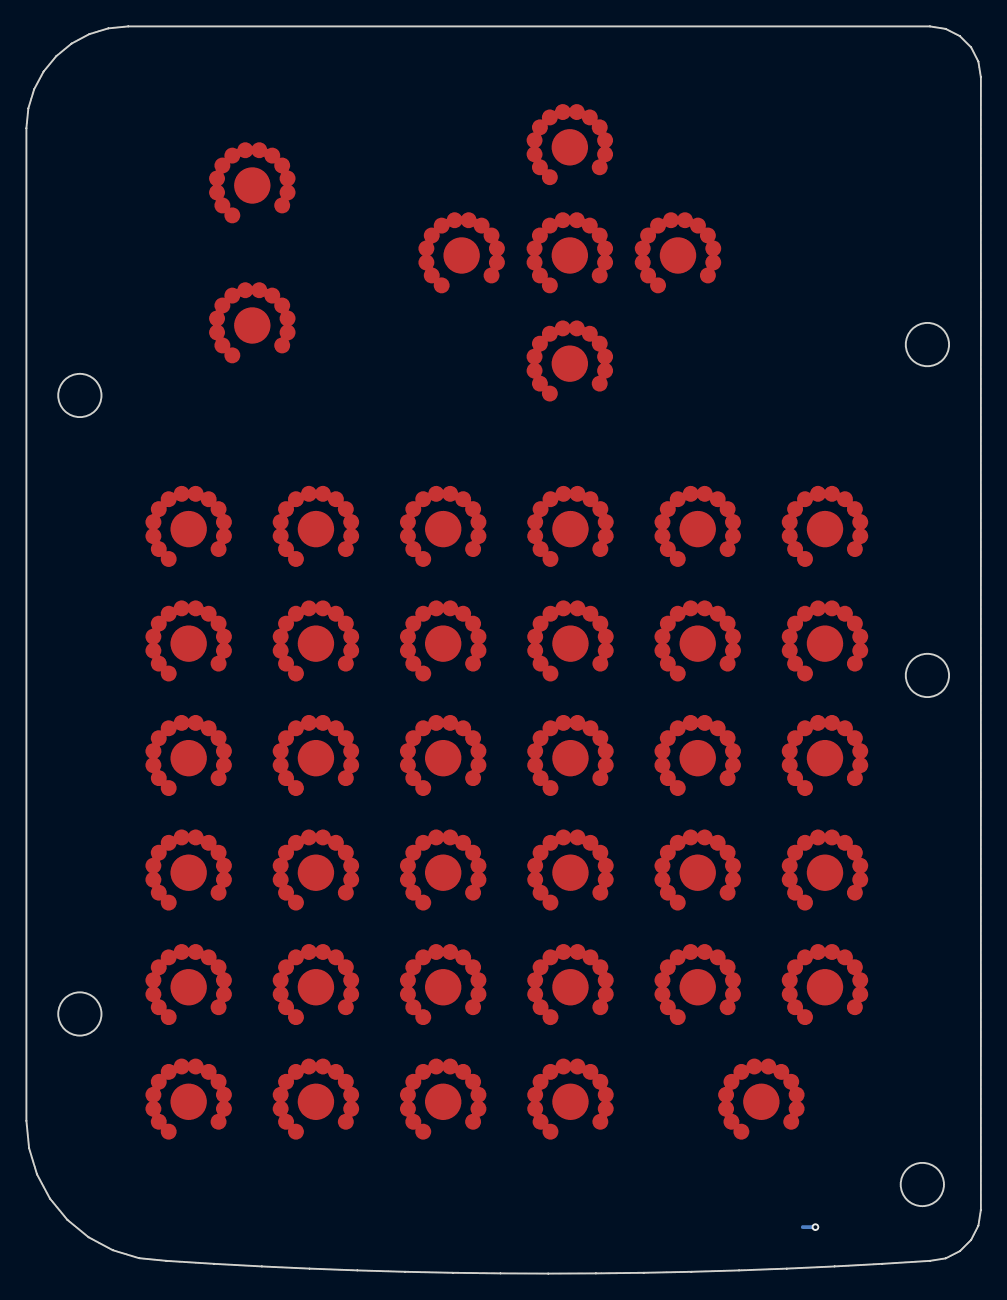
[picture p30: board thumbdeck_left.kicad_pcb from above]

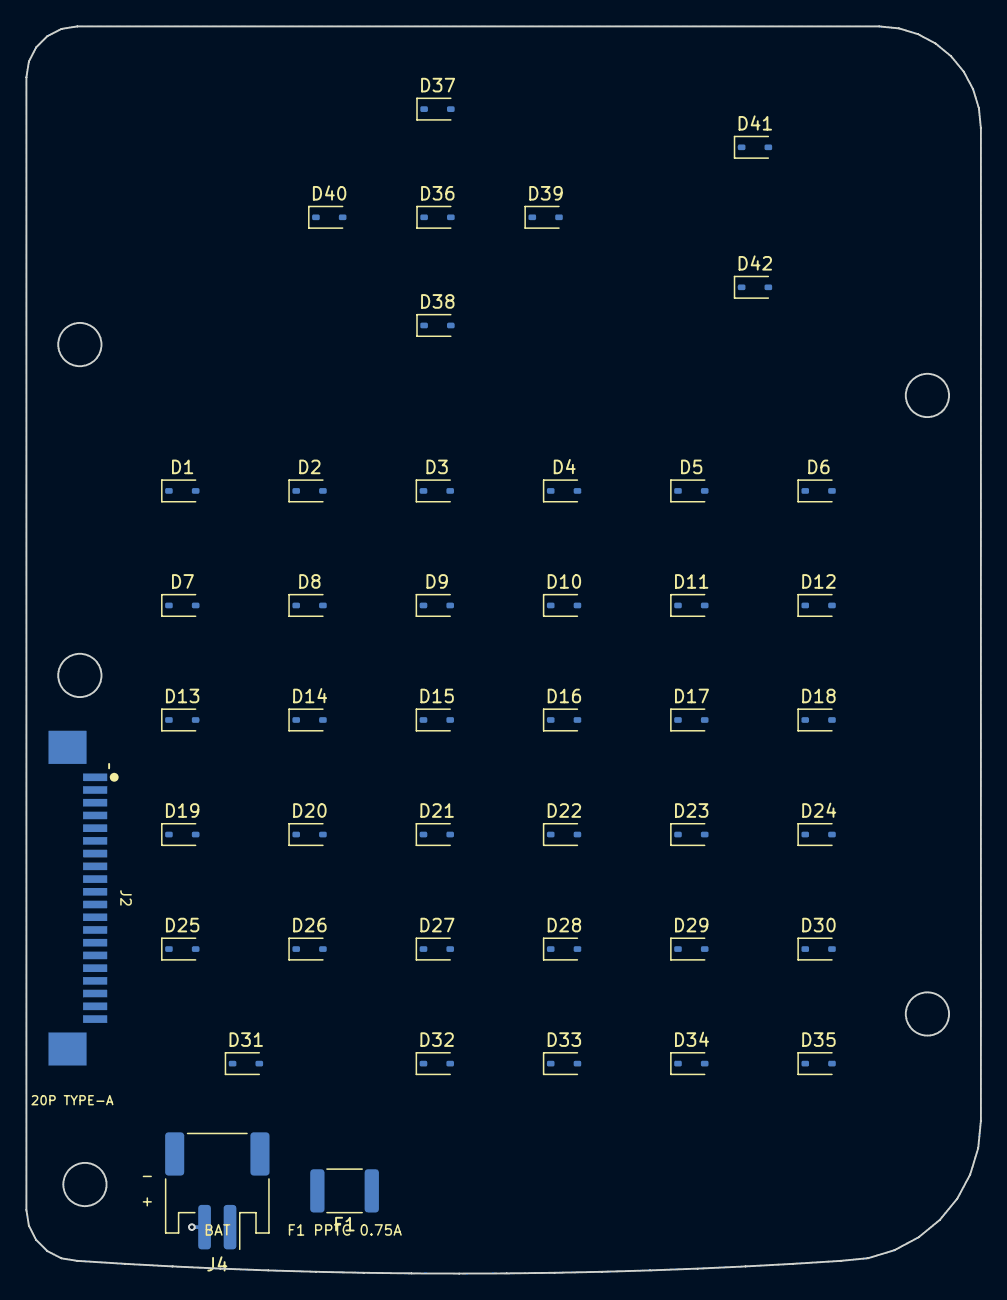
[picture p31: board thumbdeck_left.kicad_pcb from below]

Board: 4 copper layers, 75.0 x 98.0 mm, 87 parts (45 on the bottom side), 59 nets.

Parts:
D1, D2, D3, D4, D5, D6, D7, D8, D9, D10, D11, D12, D13, D14, D15, D16, D17, D18, D19, D20, D21, D22, D23, D24, D25, D26, D27, D28, D29, D30, D31, D32, D33, D34, D35, D36, D37, D38, D39, D40, D41, D42: 1N4148WS; D_SOD-323
F1: PPTC-0.75A; Fuse_1812_4532Metric
J2: FFC20; ffc_afa07_s20fcc
J4: JST-PH-2; JST_PH_S2B-PH-SM4-TB_1x02-1MP_P2.00mm_Horizontal
SW1, SW2, SW3, SW4, SW5, SW6, SW7, SW8, SW9, SW10, SW11, SW12, SW13, SW14, SW15, SW16, SW17, SW18, SW19, SW20, SW21, SW22, SW23, SW24, SW25, SW26, SW27, SW28, SW29, SW30, SW31, SW32, SW33, SW34, SW35, SW36, SW37, SW38, SW39, SW40, SW41, SW42: SNAP7; snaptron_7mm_contact

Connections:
COL5: J2.12, SW1.1, SW6.1, SW11.1, SW16.1, SW21.1, SW26.1, SW31.1, SW36.1, SW41.1
COL6: J2.13, SW2.1, SW7.1, SW12.1, SW17.1, SW22.1, SW27.1, SW32.1, SW37.1, SW42.1
COL7: J2.14, SW3.1, SW8.1, SW13.1, SW18.1, SW23.1, SW28.1, SW33.1, SW38.1
COL8: J2.15, SW4.1, SW9.1, SW14.1, SW19.1, SW24.1, SW29.1, SW34.1, SW39.1
COL9: J2.16, SW5.1, SW10.1, SW15.1, SW20.1, SW25.1, SW30.1, SW35.1, SW40.1
DN_L1: D1.2, SW1.2
DN_L2: D2.2, SW2.2
DN_L3: D3.2, SW3.2
DN_L4: D4.2, SW4.2
DN_L5: D5.2, SW5.2
DN_L6: D6.2, SW6.2
DN_L7: D7.2, SW7.2
DN_L8: D8.2, SW8.2
DN_L9: D9.2, SW9.2
DN_L10: D10.2, SW10.2
DN_L11: D11.2, SW11.2
DN_L12: D12.2, SW12.2
DN_L13: D13.2, SW13.2
DN_L14: D14.2, SW14.2
DN_L15: D15.2, SW15.2
DN_L16: D16.2, SW16.2
DN_L17: D17.2, SW17.2
DN_L18: D18.2, SW18.2
DN_L19: D19.2, SW19.2
DN_L20: D20.2, SW20.2
DN_L21: D21.2, SW21.2
DN_L22: D22.2, SW22.2
DN_L23: D23.2, SW23.2
DN_L24: D24.2, SW24.2
DN_L25: D25.2, SW25.2
DN_L26: D26.2, SW26.2
DN_L27: D27.2, SW27.2
DN_L28: D28.2, SW28.2
DN_L29: D29.2, SW29.2
DN_L30: D30.2, SW30.2
DN_L31: D31.2, SW31.2
DN_L32: D32.2, SW32.2
DN_L33: D33.2, SW33.2
DN_L34: D34.2, SW34.2
DN_L35: D35.2, SW35.2
DN_L36: D36.2, SW36.2
DN_L37: D37.2, SW37.2
DN_L38: D38.2, SW38.2
DN_L39: D39.2, SW39.2
DN_L40: D40.2, SW40.2
DN_L41: D41.2, SW41.2
DN_L42: D42.2, SW42.2
GND: J2.1, J2.2, J2.MP, J4.2
ROW0: D1.1, D2.1, D3.1, D4.1, D5.1, J2.3
ROW1: D6.1, D7.1, D8.1, D9.1, D10.1, J2.4
ROW2: D11.1, D12.1, D13.1, D14.1, D15.1, J2.5
ROW3: D16.1, D17.1, D18.1, D19.1, D20.1, J2.6
ROW4: D21.1, D22.1, D23.1, D24.1, D25.1, J2.7
ROW5: D26.1, D27.1, D28.1, D29.1, D30.1, J2.8
ROW6: D31.1, D32.1, D33.1, D34.1, D35.1, J2.9
ROW7: D36.1, D37.1, D38.1, D39.1, D40.1, J2.10
ROW8: D41.1, D42.1, J2.11
VBAT_CELL: F1.2, J2.18, J2.19
VCELL_RAW: F1.1, J4.1

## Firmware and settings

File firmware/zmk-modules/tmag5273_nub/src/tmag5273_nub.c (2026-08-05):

/*
 * SPDX-License-Identifier: Apache-2.0
 * Copyright 2026 Eric Neuman
 *
 * tmag5273_nub.c — TI TMAG5273 I2C 3D hall sensor as a ThinkPad-style
 * rate-control pointing nub (the v0.21 "Bean-style" pointer: magnet in a
 * printed flexure spring above the sensor, architecture per the Ploopy Bean,
 * CERN-OHL-S v2 hardware; this driver is an original work referencing the
 * Apache-2.0 upstream Zephyr tmag5273 sensor driver for the register map and
 * the TI datasheet SLYS045 for field semantics).
 *
 * Behaviour: at boot the magnetic zero is averaged over calib-samples polls
 * (this also swallows the MagSafe ring's static ambient field ~90mm away).
 * Each poll reads X/Y field, subtracts the zero, applies a deadzone, and maps
 * the excess through a QUADRATIC curve to pointer velocity — deflection angle
 * controls cursor SPEED (true trackpoint rate control), with fixed-point
 * remainder accumulation so slow precise motion still creeps sub-pixel.
 */

#define DT_DRV_COMPAT thumbdeck_tmag5273_nub

#include <zephyr/device.h>
#include <zephyr/drivers/i2c.h>
#include <zephyr/input/input.h>
#include <zephyr/kernel.h>
#include <zephyr/logging/log.h>
#include <zephyr/pm/device.h>

LOG_MODULE_REGISTER(tmag5273_nub, CONFIG_INPUT_LOG_LEVEL);

/* Register map (TI TMAG5273 datasheet; matches upstream Zephyr driver) */
#define TMAG_REG_DEVICE_CONFIG_1  0x00
#define TMAG_REG_DEVICE_CONFIG_2  0x01
#define TMAG_REG_SENSOR_CONFIG_1  0x02
#define TMAG_REG_SENSOR_CONFIG_2  0x03
#define TMAG_REG_MANUFACTURER_LSB 0x0E
#define TMAG_REG_X_MSB_RESULT     0x12
#define TMAG_REG_CONV_STATUS      0x18

#define TMAG_MANUFACTURER_ID      0x5449 /* "TI" */

/* DEVICE_CONFIG_1: CRC off, 8x conversion averaging, standard I2C reads.
 * v0.26 also selects MAG_TEMPCO = 01b (bits [6:5]) = 0.12%/degC, the NdFeB
 * coefficient. The magnet IS NdFeB and loses ~0.12%/degC of remanence, so
 * leaving this at "no compensation" let the pointer gain drift with hand and
 * ambient temperature. It is a free register field. */
#define TMAG_CONV_AVG_8           (3u << 2)
#define TMAG_TEMPCO_NDFEB         (1u << 5)
/* SENSOR_CONFIG_1[7:4] MAG_CH_EN: 0x3 = X and Y channels */
#define TMAG_MAG_CH_EN_XY         (0x3u << 4)
/* SENSOR_CONFIG_2 bit1: X/Y range. 0 = +/-40mT (the A1 reset default), 1 = +/-80mT.
 *
 * v0.26 uses the +/-40mT range, i.e. this bit is left CLEAR. The old code set it
 * and justified it as "headroom vs the close nub magnet" — but that conflates the
 * AXIAL field with the channels actually being measured. MAG_CH_EN above enables
 * X and Y only; Z is never converted, so the ~52mT sitting on the magnet's axis
 * never enters a measured channel. X/Y only ever see the TRANSVERSE field, which is
 * the tilt signal (<= ~4.3mT even at a 320gf abuse push) plus the static offset from
 * the die's 0.418mm in-package misalignment (~6.7mT). Worst case is under 12mT — 30%
 * of the +/-40mT scale — so the wider range bought nothing and cost half the
 * resolution. At +/-40mT a count is 1.2207uT instead of 2.4414uT. */
/* DEVICE_CONFIG_2[1:0] operating mode: 1 = sleep, 2 = continuous measure */
#define TMAG_OP_MODE_SLEEP        0x1u
#define TMAG_OP_MODE_CONTINUOUS   0x2u

struct nub_config {
	struct i2c_dt_spec i2c;
	uint32_t sampling_hz;
	int32_t deadzone;
	int32_t gain_num;
	int32_t gain_div;
	int32_t max_out;
	uint32_t calib_samples;
	bool invert_x;
	bool invert_y;
	bool swap_xy;
};

struct nub_data {
	const struct device *dev;
	struct k_work_delayable work;
	int32_t zero_x, zero_y;
	int64_t calib_acc_x, calib_acc_y;
	uint32_t calib_left;
	int32_t rem_x, rem_y; /* 1/256-px velocity remainders */
};

static int nub_read_xy(const struct device *dev, int16_t *x, int16_t *y)
{
	const struct nub_config *cfg = dev->config;
	uint8_t buf[4];
	int ret;

	/* X_MSB..Y_LSB are contiguous (0x12..0x15), MSB first */
	ret = i2c_burst_read_dt(&cfg->i2c, TMAG_REG_X_MSB_RESULT, buf, sizeof(buf));
	if (ret < 0) {
		return ret;
	}
	*x = (int16_t)((buf[0] << 8) | buf[1]);
	*y = (int16_t)((buf[2] << 8) | buf[3]);
	return 0;
}

/* quadratic rate curve: velocity_256 = excess^2 * gain_num / gain_div,
 * clamped to max_out pixels/poll, sign restored, remainder-accumulated */
static int32_t nub_curve(const struct nub_config *cfg, int32_t d, int32_t *rem)
{
	int32_t mag = d < 0 ? -d : d;
	int32_t out;

	if (mag <= cfg->deadzone) {
		return 0;
	}
	mag -= cfg->deadzone;

	int64_t v256 = ((int64_t)mag * mag * cfg->gain_num) / cfg->gain_div;
	int64_t vmax = (int64_t)cfg->max_out * 256;

	if (v256 > vmax) {
		v256 = vmax;
	}
	*rem += (d < 0) ? -(int32_t)v256 : (int32_t)v256;
	out = *rem / 256;
	*rem -= out * 256;
	return out;
}

static void nub_work_handler(struct k_work *work)
{
	struct k_work_delayable *dwork = k_work_delayable_from_work(work);
	struct nub_data *data = CONTAINER_OF(dwork, struct nub_data, work);
	const struct device *dev = data->dev;
	const struct nub_config *cfg = dev->config;
	int16_t raw_x, raw_y;

	if (nub_read_xy(dev, &raw_x, &raw_y) == 0) {
		if (data->calib_left > 0) {
			/* boot zero calibration (also swallows ambient field) */
			data->calib_acc_x += raw_x;
			data->calib_acc_y += raw_y;
			data->calib_left--;
			if (data->calib_left == 0) {
				data->zero_x = (int32_t)(data->calib_acc_x /
							 cfg->calib_samples);
				data->zero_y = (int32_t)(data->calib_acc_y /
							 cfg->calib_samples);
				LOG_INF("nub zero: x=%d y=%d", data->zero_x,
					data->zero_y);
			}
		} else {
			int32_t dx = (int32_t)raw_x - data->zero_x;
			int32_t dy = (int32_t)raw_y - data->zero_y;

			if (cfg->swap_xy) {
				int32_t t = dx;
				dx = dy;
				dy = t;
			}
			if (cfg->invert_x) {
				dx = -dx;
			}
			if (cfg->invert_y) {
				dy = -dy;
			}

			int32_t rx = nub_curve(cfg, dx, &data->rem_x);
			int32_t ry = nub_curve(cfg, dy, &data->rem_y);

			if (rx != 0) {
				input_report_rel(dev, INPUT_REL_X, rx,
						 ry == 0, K_NO_WAIT);
			}
			if (ry != 0) {
				input_report_rel(dev, INPUT_REL_Y, ry, true,
						 K_NO_WAIT);
			}
		}
	}

	k_work_schedule(&data->work, K_MSEC(1000U / cfg->sampling_hz));
}

static int nub_configure(const struct device *dev)
{
	const struct nub_config *cfg = dev->config;
	int ret;

	ret = i2c_reg_write_byte_dt(&cfg->i2c, TMAG_REG_DEVICE_CONFIG_1,
				    TMAG_CONV_AVG_8 | TMAG_TEMPCO_NDFEB);
	if (ret == 0) {
		ret = i2c_reg_write_byte_dt(&cfg->i2c, TMAG_REG_SENSOR_CONFIG_1,
					    TMAG_MAG_CH_EN_XY);
	}
	if (ret == 0) {
		/* X/Y range stays at the +/-40mT reset default (bit 1 clear) — see the
		 * SENSOR_CONFIG_2 comment above for why the wider range was wrong. */
		ret = i2c_reg_write_byte_dt(&cfg->i2c, TMAG_REG_SENSOR_CONFIG_2, 0x00);
	}
	if (ret == 0) {
		ret = i2c_reg_write_byte_dt(&cfg->i2c, TMAG_REG_DEVICE_CONFIG_2,
					    TMAG_OP_MODE_CONTINUOUS);
	}
	return ret;
}
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

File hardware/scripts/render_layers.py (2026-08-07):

#!/usr/bin/env python3
# SPDX-License-Identifier: Apache-2.0
# Copyright 2026 Eric Neuman
"""
⚠ STALE — DO NOT PUBLISH ITS OUTPUT. This generator was last correct at v0.22.
It still draws the MagSafe ring and pocket (dropped in v0.25), a rigid centre
spine (replaced by the v0.24 telescoping tray) and the left nav cluster as five
separate buttons (v0.25 merged them into one Ø24 integrated D-pad). Its PNGs
were removed from the README for that reason. Fix those three things against
deck.product() before regenerating anything from here.

render_layers.py — the assembly as STACKABLE LAYERS. Five PNGs on an identical
canvas (same size + positioning) so they overlay pixel-for-pixel or flip through
as an animation, back-to-front:

  layer_1_back_shell.png   bottom case: shell, screw bosses, MagSafe + battery
                           pocket in the spine, USB-C cutout
  layer_2_pcb_back.png     PCB back side: module, 81 diodes, charger/USB-C/ESD,
                           connectors, ROW traces, silkscreen refs
  layer_3_pcb_front.png    PCB front side: 81 dome pads, COLUMN traces, mount
                           holes, key silkscreen
  layer_4_keymats.png      one-piece keymats: keycaps + living-hinge strips
  layer_5_front_shell.png  top case: shell with key openings, phone + trackpad
                           windows, screw holes

Whole device (both grips + central spine), front view. Neutral per-layer styling
(no column/row colour-coding). Geometry from deck.product().
"""
import os
import matplotlib
matplotlib.use("Agg")
import matplotlib.pyplot as plt
from matplotlib.patches import Polygon, FancyBboxPatch, Rectangle, Circle
import deck

OUT = os.path.abspath(os.path.join(os.path.dirname(__file__), "..", "..", "renders"))
FIGSIZE = (16.0, 7.0)
DPI = 150
BG = "#0b0f14"

INK = "#cfd6dd"      # neutral light
SHELL = "#3a4149"    # case grey
SHELL_HI = "#4c545d"
PCB = "#0e2a1e"      # board green
PCB_ED = "#1f7a52"
SILK = "#e8edf2"
COPPER = "#b87333"


def _bbox(P):
    lx = P["left_origin"][0]
    rx = P["right_origin"][0] + P["right"]["board_w"]
    top = max(P["right"]["board_h"], P["left"]["board_h"]) + 16  # room for trackpad bump
    return lx - 8, rx + 8, -10, top


def _ax(fig, P):
    ax = fig.add_axes([0, 0, 1, 1])
    x0, x1, y0, y1 = _bbox(P)
    ax.set_xlim(x0, x1); ax.set_ylim(y0, y1)
    ax.set_aspect("equal"); ax.axis("off")
    ax.set_facecolor(BG)
    return ax


def _grip_outline(geo, ox, oy):
    return [[x + ox, y + oy] for x, y in geo["outline"]]


def _spine_rect(P):
    g = P["config"]["phone_w"] if False else None
    gap_x0 = P["left_origin"][0] + P["left"]["board_w"]
    gap_x1 = P["right_origin"][0]
    h = max(P["right"]["board_h"], P["left"]["board_h"])
    return gap_x0, 0.0, gap_x1 - gap_x0, h


# ---------- layer 1: back shell ----------
def back_shell(ax, P):
    for side, key in (("left", "left"), ("right", "right")):
        geo = P[key]; ox, oy = P[f"{key}_origin"]
        ax.add_patch(Polygon(_grip_outline(geo, ox, oy), closed=True,
                     facecolor=SHELL, edgecolor=SHELL_HI, lw=2.5, zorder=2))
    sx, sy, sw, sh = _spine_rect(P)
    ax.add_patch(FancyBboxPatch((sx, sy), sw, sh, boxstyle="round,pad=0,rounding_size=6",
                 facecolor=SHELL, edgecolor=SHELL_HI, lw=2.5, zorder=1))
    # MagSafe + battery pockets in the spine
    ms = P["magsafe"]
    ax.add_patch(Circle((ms["cx"], ms["cy"]), ms["d"] / 2, facecolor="#2b3239",
                 edgecolor=INK, lw=1.4, zorder=3))
    ax.text(ms["cx"], ms["cy"] + ms["d"] / 2 - 6, "MagSafe pocket", ha="center", fontsize=7, color=INK, zorder=4)
    # v0.18: LiPo 403040 sits in the LEFT grip's back cavity (foam-taped to the
    # floor under the passive PCB) — the sunken phone well displaced it from the spine
    sb = P["battery"]
    ax.add_patch(Rectangle((sb["x"], sb["y"]), sb["w"], sb["h"], facecolor="#2b3239",
                 edgecolor=INK, ls="--", lw=1.2, zorder=4))
    ax.text(sb["x"] + sb["w"] / 2, sb["y"] + 5, f"LiPo {sb['cell']}", ha="center", fontsize=6, color=INK, zorder=4)
    # screw bosses
    for key in ("left", "right"):
        geo = P[key]; ox, oy = P[f"{key}_origin"]
        for h in geo["mount_holes"]:
            ax.add_patch(Circle((h["x"] + ox, h["y"] + oy), 2.6, facecolor="#2b3239",
                         edgecolor=INK, lw=1.1, zorder=4))
            ax.add_patch(Circle((h["x"] + ox, h["y"] + oy), h["d"] / 2, facecolor=BG, edgecolor=INK, lw=0.8, zorder=5))
    # USB-C cutout on the right grip outer-bottom
    geo = P["right"]; ox, oy = P["right_origin"]
    ux, uy, uw, uh = geo["keepouts"]["usb_c"]
    ax.add_patch(Rectangle((ux + ox, oy - 1), uw, 3, facecolor=BG, edgecolor=INK, lw=1.2, zorder=5))
    ax.text(ux + ox + uw / 2, oy + 4, "USB-C", ha="center", fontsize=6, color=INK, zorder=5)


# ---------- PCB helpers ----------
def _pcb(ax, geo, ox, oy):
    ax.add_patch(Polygon(_grip_outline(geo, ox, oy), closed=True,
                 facecolor=PCB, edgecolor=PCB_ED, lw=2.0, zorder=2))
    for h in geo["mount_holes"]:
        ax.add_patch(Circle((h["x"] + ox, h["y"] + oy), h["d"] / 2, facecolor=BG, edgecolor=PCB_ED, lw=1.0, zorder=6))


def _meander(ax, x, y, w, h, n=6):
    """A fat serpentine PCB antenna trace inside a rect."""
    seg = w / n; pts = []
    for i in range(n + 1):
        xi = x + i * seg; top = (i % 2 == 0)
        pts += [(xi, y + (h if top else 0)), (xi, y + (0 if top else h))]
    ax.plot([p[0] for p in pts], [p[1] for p in pts], color=COPPER, lw=2.4,
            solid_capstyle="round", solid_joinstyle="round", zorder=4)


def _via(ax, x, y):
    ax.add_patch(Circle((x, y), 0.7, facecolor=BG, edgecolor=COPPER, lw=0.5, zorder=6))


def pcb_front(ax, P):
    # FRONT = vertical COLUMN traces + inner-margin row feeders + trackpad + antenna.
    # Layers only ever connect through vias (never cross on the same copper layer).
    for key in ("left", "right"):
        geo = P[key]; ox, oy = P[f"{key}_origin"]
        _pcb(ax, geo, ox, oy)
        keys = geo["keys"]
        cols, rows = {}, {}
        for k in keys:
            cols.setdefault(k["col"], []).append(k); rows.setdefault(k["row"], []).append(k)
        collect_y = min(k["y"] for k in keys) - 7
        for c, ks in cols.items():                       # vertical columns over the keys
            x = ks[0]["x"] + ox
            ax.plot([x, x], [collect_y + oy, max(k["y"] for k in ks) + oy + 4],
                    color=COPPER, lw=1.5, alpha=0.85, zorder=3)
        fx = 3.2 + ox                                    # inner-margin row feeders (front)
        for r, ks in rows.items():
            ry = ks[0]["y"] + oy
            ax.plot([fx, fx], [collect_y + oy, ry], color="#d18a4a", lw=1.0, alpha=0.7, zorder=3)
            _via(ax, fx, ry)                             # feeder -> back row
        allk = list(keys) + [f for f in geo.get("features", []) if f["type"] == "key"]
        for k in allk:                                   # dome pad + per-key via
            ax.add_patch(Circle((k["x"] + ox, k["y"] + oy), 3.5, facecolor="#caa46a",
                         edgecolor="#edd7b0", lw=0.8, zorder=5))
            _via(ax, k["x"] + ox + 2.6, k["y"] + oy - 2.6)
            ax.text(k["x"] + ox, k["y"] + oy, k.get("label", "").replace("NAV_", "").replace("MB_", "M"),
                    ha="center", va="center", fontsize=4.0, color="#3a2d10", fontweight="bold", zorder=6)
        for f in geo.get("features", []):
            if f["type"] == "trackpad":                  # PCB-integrated cap pad (front copper)
                tw, th = f["w"], f["h"]
                ax.add_patch(Rectangle((f["x"] + ox - tw / 2, f["y"] + oy - th / 2), tw, th,
                             facecolor="#8a6a3a", edgecolor=COPPER, lw=1.2, hatch="xx", alpha=0.5, zorder=4))
                ax.text(f["x"] + ox, f["y"] + oy, "cap. trackpad\n(front copper)", ha="center",
                        va="center", fontsize=5, color="#f1e2c8", zorder=6)
        if "antenna" in geo["keepouts"]:                 # module antenna keep-out at the edge
            axk, ay, aw, ah = geo["keepouts"]["antenna"]
            ax.add_patch(Rectangle((axk + ox, ay + oy), aw, ah, facecolor="none",
                         edgecolor=COPPER, ls=":", lw=1.0, hatch="//", alpha=0.5, zorder=4))
            ax.text(axk + ox + aw / 2, ay + oy + ah + 1, "E73 antenna keep-out (all layers)", ha="center",
                    va="bottom", fontsize=4.2, color=COPPER, zorder=6)
        ax.text(ox + geo["board_w"] * 0.5, oy - 4,
                "FRONT copper: vertical COLUMNS · inner row-feeders · dome pads   ● = via to back",
                ha="center", fontsize=5.2, color=COPPER, zorder=7)


def pcb_back(ax, P):
    # BACK = horizontal ROW traces + diodes + all chips. Rows and columns cross only
    # through vias, so nothing shorts (Rii i8+ topology).
    for key in ("left", "right"):
        geo = P[key]; ox, oy = P[f"{key}_origin"]
        _pcb(ax, geo, ox, oy)
        keys = geo["keys"]
        rows = {}
        for k in keys:
            rows.setdefault(k["row"], []).append(k)
        for r, ks in rows.items():                       # horizontal rows, to the inner via column
            ry = ks[0]["y"] + oy
            ax.plot([3.2 + ox, max(k["x"] for k in ks) + ox + 4], [ry, ry],
                    color=COPPER, lw=1.5, alpha=0.85, zorder=3)
            _via(ax, 3.2 + ox, ry)
        allk = list(keys) + [f for f in geo.get("features", []) if f["type"] == "key"]
        for k in allk:                                   # diode + per-key via
            ax.add_patch(Rectangle((k["x"] + ox - 1.1, k["y"] + oy - 0.7), 2.2, 1.4,
                         facecolor="#2b2b2b", edgecolor=SILK, lw=0.4, zorder=5))
            _via(ax, k["x"] + ox + 2.6, k["y"] + oy - 2.6)
        ko = geo["keepouts"]
        def cen(n):
            x, y, w, h = ko[n]; return (x + ox + w / 2, y + oy + h / 2)
        if "controller" in ko:                           # short LOCAL power traces (bottom cluster only)
            for a, b in (("controller", "charger"), ("charger", "usb_c")):
                axx, ayy = cen(a); bxx, byy = cen(b)
                ax.plot([axx, bxx], [ayy, byy], color=COPPER, lw=1.2, alpha=0.7, zorder=3)
            mcx, mcy = cen("controller")
            ax.plot([mcx, 3.2 + ox], [mcy, mcy], color=COPPER, lw=1.0, alpha=0.5, zorder=3)  # -> row via column
        if "antenna" in ko:                              # all-layer keep-out under the module antenna
            axk, ay, aw, ah = ko["antenna"]
            ax.add_patch(Rectangle((axk + ox, ay + oy), aw, ah, facecolor="none",
                         edgecolor=COPPER, ls=":", lw=1.0, hatch="//", alpha=0.5, zorder=4))
            ax.text(axk + ox + aw / 2, ay + oy + ah / 2, "antenna\nkeep-out", ha="center",
                    va="center", fontsize=3.4, color=COPPER, zorder=5)
        refs = {"controller": "U1 Ebyte E73", "usb_c": "J1 USB-C",
                "charger": "U2 + pwr", "bridge": "J2 FFC-20"}
        for name, (kx, ky, kw, kh) in ko.items():
            if name == "antenna":
                continue
            ax.add_patch(Rectangle((kx + ox, ky + oy), kw, kh, facecolor="#20303f",
                         edgecolor="#7f98c0", lw=1.0, zorder=4))
            ax.text(kx + ox + kw / 2, ky + oy + kh / 2, refs.get(name, name.upper()),
                    ha="center", va="center", fontsize=4.0, color="#cdd6ff", zorder=5)
        ax.text(ox + geo["board_w"] * 0.5, oy - 4,
                "BACK copper: horizontal ROWS · diodes · chips   layers join ONLY through vias (●) — no crossings",
                ha="center", fontsize=5.2, color=COPPER, zorder=7)


# ---------- layer 4: keymats ----------
def keymats(ax, P):
    for key in ("left", "right"):
        geo = P[key]; ox, oy = P[f"{key}_origin"]
        pitch = geo["config"]["pitch_x"]; kw0 = geo["config"]["key_w"]; kh0 = geo["config"]["key_h"]
        grid = {(k["row"], k["col"]): k for k in geo["keys"]}
        feats = [f for f in geo.get("features", []) if f["type"] == "key"]

        def strip(a, b):
            ax.plot([a["x"] + ox, b["x"] + ox], [a["y"] + oy, b["y"] + oy],
                    color="#8a8f96", lw=2.5, alpha=0.55, zorder=3, solid_capstyle="round")

        def dist(a, b):
            return ((a["x"] - b["x"]) ** 2 + (a["y"] - b["y"]) ** 2) ** 0.5

        # grid neighbours
        for (r, c), k in grid.items():
            for dr, dc in ((0, 1), (1, 0)):
                n = grid.get((r + dr, c + dc))
                if n:
                    strip(k, n)
        # cluster living-hinges — every feature key ties into the web: to its nearest
        # grid key (bridges the cluster to the main field) AND its nearest other feature.
        gk = list(geo["keys"])
        for f in feats:
            strip(f, min(gk, key=lambda k: dist(f, k)))
            others = [o for o in feats if o is not f]
            if others:
                strip(f, min(others, key=lambda o: dist(f, o)))
        # keycaps (grid = w-aware incl. 2u space; feature keys = single)
        for k in list(geo["keys"]) + feats:
            w = (k.get("w", 1) - 1) * pitch + kw0
            ax.add_patch(FancyBboxPatch((k["x"] + ox - w / 2, k["y"] + oy - kh0 / 2), w, kh0,
                         boxstyle="round,pad=0,rounding_size=1.6", facecolor="#d7dade",
                         edgecolor="#9aa0a7", lw=0.9, zorder=5))
            ax.text(k["x"] + ox, k["y"] + oy, k.get("label", "").replace("NAV_", "").replace("MB_", "M"),
                    ha="center", va="center", fontsize=4.2, color="#20242a", fontweight="bold", zorder=6)


# ---------- layer 5: front shell ----------
def front_shell(ax, P):
    for key in ("left", "right"):
        geo = P[key]; ox, oy = P[f"{key}_origin"]
        ax.add_patch(Polygon(_grip_outline(geo, ox, oy), closed=True,
                     facecolor=SHELL_HI, edgecolor=INK, lw=2.5, zorder=2))
    sx, sy, sw_, sh = _spine_rect(P)
    # spine is SOLID (the phone MagSafe-mounts to its OUTSIDE, it is not a window)
    ax.add_patch(FancyBboxPatch((sx, sy), sw_, sh, boxstyle="round,pad=0,rounding_size=6",
                 facecolor=SHELL_HI, edgecolor=INK, lw=2.5, zorder=1))
    # MagSafe N52 ring applied to the OUTSIDE of the front shell (top of the stack);
    # the phone mates onto it. Drawn last / on top.
    ms = P["magsafe"]
    ax.add_patch(Circle((ms["cx"], ms["cy"]), ms["d"] / 2, facecolor="none",
                 edgecolor="#43aa8b", lw=6, alpha=0.9, zorder=7))
    ax.add_patch(Circle((ms["cx"], ms["cy"]), ms["d"] / 2 - 4, facecolor="none",
                 edgecolor="#43aa8b", lw=2, alpha=0.5, zorder=7))
    ax.text(ms["cx"], ms["cy"], "MagSafe ring\n(applied on top\nof front shell)", ha="center",
            va="center", fontsize=7, color="#43aa8b", zorder=8)
    # faint phone outline showing where it mounts
    ph = P["phone"]
    ax.add_patch(FancyBboxPatch((ph["x"], ph["y"]), ph["w"], ph["h"],
                 boxstyle="round,pad=0,rounding_size=6", facecolor="none", edgecolor=INK,
                 ls=(0, (4, 3)), lw=1.0, alpha=0.5, zorder=6))
    ax.text(ph["x"] + 4, ph["y"] + ph["h"] - 4, "phone mounts here", ha="left",
            va="top", fontsize=6.5, color=INK, alpha=0.6, zorder=6)
    # key openings + trackpad window + screw holes
    for key in ("left", "right"):
        geo = P[key]; ox, oy = P[f"{key}_origin"]
        sw = list(geo["keys"]) + [f for f in geo.get("features", []) if f["type"] == "key"]
        pitch = geo["config"]["pitch_x"]; kw0 = geo["config"]["key_w"]; kh0 = geo["config"]["key_h"]
        for k in sw:
            w = (k.get("w", 1) - 1) * pitch + kw0
            ax.add_patch(FancyBboxPatch((k["x"] + ox - w / 2, k["y"] + oy - kh0 / 2), w, kh0,
                         boxstyle="round,pad=0,rounding_size=1.6", facecolor=BG,
                         edgecolor=INK, lw=0.7, zorder=4))
        for f in geo.get("features", []):
            if f["type"] == "trackpad":
                ax.add_patch(FancyBboxPatch((f["x"] + ox - f["w"] / 2, f["y"] + oy - f["h"] / 2),
                             f["w"], f["h"], boxstyle="round,pad=0,rounding_size=3", facecolor=BG,
                             edgecolor="#7fd1ff", ls=":", lw=1.4, zorder=4))
                ax.text(f["x"] + ox, f["y"] + oy, "trackpad\nwindow (opt)", ha="center",
                        va="center", fontsize=5.5, color="#7fd1ff", zorder=5)
            elif f["type"] == "hall_nub":
                ad = f.get("aperture_d", 10.0)
                ax.add_patch(Circle((f["x"] + ox, f["y"] + oy), ad / 2, facecolor=BG,
                             edgecolor="#7fd1ff", lw=1.4, zorder=4))
                ax.add_patch(Circle((f["x"] + ox, f["y"] + oy), 4.25, facecolor=BG,
                             edgecolor="#7fd1ff", lw=1.6, zorder=5))
                ax.text(f["x"] + ox, f["y"] + oy, "NUB", ha="center", va="center",
                        fontsize=4.2, color="#7fd1ff", fontweight="bold", zorder=6)
        for h in geo["mount_holes"]:
            ax.add_patch(Circle((h["x"] + ox, h["y"] + oy), h["d"] / 2 + 0.4,
                         facecolor=BG, edgecolor=INK, lw=0.9, zorder=5))


LAYERS = [
    ("layer_1_back_shell", back_shell, "1 · BACK SHELL"),
    ("layer_2_pcb_back", pcb_back, "2 · PCB BACK (module, diodes, chips, rows)"),
    ("layer_3_pcb_front", pcb_front, "3 · PCB FRONT (domes, columns)"),
    ("layer_4_keymats", keymats, "4 · KEYMATS"),
    ("layer_5_front_shell", front_shell, "5 · FRONT SHELL"),
]


def main():
    P = deck.product(deck.Config())
    os.makedirs(OUT, exist_ok=True)
    for name, fn, label in LAYERS:
        fig = plt.figure(figsize=FIGSIZE, dpi=DPI)
        fig.patch.set_facecolor(BG)
        ax = _ax(fig, P)
        fn(ax, P)
        ax.text(0.012, 0.965, f"thumbdeck {deck.VERSION}  ·  {label}", transform=ax.transAxes,
                fontsize=11, color="#f4d35e", fontweight="bold", va="top")
        p = os.path.join(OUT, f"{name}.png")
        fig.savefig(p, dpi=DPI, facecolor=BG)
        plt.close(fig)
        print(p)


if __name__ == "__main__":
    main()

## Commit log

2026-07-03 firmware: ZMK split shield (thumbdeck) + CI build
    - 50-key combined transform; right=central, left=peripheral (col-offset=5)
    - real XIAO nRF52840 pins (D0-D4 rows / D5-D9 cols); col2row diodes
    - BLE + USB + per-half battery reporting; build.yaml + Actions workflow
    Claude-Session: https://claude.ai/code/session_01AmPvvwwHX98PjdDnPxhX97
2026-07-03 hardware: parametric layout generator + two-gate grading system
    - deck.py geometry (D-grip, thumb-arc fan, component strips), mirror-derived halves
    - layout_gen.py matplotlib render; grade.py (16 functional checks) + final_grade.py
    - matrix_map.py asserts render legends == ZMK keymap
    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
2026-07-03 hardware: KiCad board + DXF + placement generation (production-ready outline)
    - gen_kicad.py emits openable .kicad_pcb (Edge.Cuts, mount cutouts, keep-outs,
    placement guides), DXF outline, placement CSV
    - provisional switch footprint + routing left as TODO(user) per spec
    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
    [thumbdeck_left.kicad_pcb, thumbdeck_left_outline.dxf, thumbdeck_left_placement.csv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]
2026-07-03 docs: design decisions, connectivity/power, matrix, BOM, assembly, i8+ reference, arch diagram
    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
2026-07-03 renders: converged layout + fab view + grading log
    Loop converged at iter 03: functional 100% (16/16), visual 8/8, OVERALL PASS.
    iter_01 kept as genuine failing predecessor (envelope 67mm).
    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
2026-07-04 hardware(v0.3): role-based geometry, grader, board gen
    - deck.py: right grip = mcu (nice!nano/LiPo/USB-C/bridge), left = passive matrix
    + bridge connector; symmetric outline, mirrored key field
    - grade.py: 17 checks incl. F-bridge + F-role; nice!nano pro_micro pin validity;
    single 5x10 transform (dropped split-specific checks)
    - gen_kicad/render_fab/matrix_map updated for single controller
    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
    [thumbdeck_left.kicad_pcb, thumbdeck_left_outline.dxf, thumbdeck_left_placement.csv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]
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2026-07-04 v0.4: encode EE design review into the grade, re-converge to PASS
    Turn the professional EE review findings into enforced checks and fix the design
    to satisfy them (functional 27/27, visual 9/9, OVERALL PASS).
    Geometry/RF:
    - nice!nano remounted vertical at top; nRF52840 ANTENNA keep-out overhangs the
    top edge (no copper under RF path), LiPo kept ~90mm away; USB in an access gap
    - new hard check F-antenna; F-role now requires antenna on right / passive left
    Bridge signal integrity:
    - kscan debounce 8ms (F-si-debounce); BOM adds 4.7k row pull-downs, 100-330R
    column series R, TVS, shielded flex (F-si-passives, F-esd-tvs)
    Process/plan gates (now graded):
    - F-charge (1C vs cell), F-switch-v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
    [thumbdeck_left.kicad_pcb, thumbdeck_left_outline.dxf, thumbdeck_left_placement.csv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]
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2026-07-09 v0.12: snap-dome phone MagSafe deck — module, turnkey PCBA, stackable layer renders
    Redesign from v0.4 (50-key nice!nano) to a landscape-phone MagSafe deck:
    - Switches: Snaptron 7mm snap domes on a one-piece 3D-printed living-hinge keymat
    (PocketMage-style); footprint extracted to hardware/footprints/. 81 keys (2x 6x6
    grids + D-pad/OK + mouse + PgUp/Dn), digitized from the sketch to
    hardware/layout/keymat.json.
    - Form: phone landscape, MagSafe-mounted centre; LiPo in the spine behind the ring;
    two ~70x102mm grips clamped to the outline; PCB-integrated trackpad (Azoteq IQS7211E).
    - Electronics (5-lens EE/PD review): one Ebyte E73 nRF52840 module, 9x10 col2row
    matrix with SOD-323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
    [thumbdeck_left.kicad_pcb, thumbdeck_left_outline.dxf, thumbdeck_left_placement.csv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]
2026-07-10 v0.13: printable pitch, 2u space bar, cluster/screw/keymat fixes
    Feedback fixes (all verified: no overlaps, nothing off-board, no screw in a keep-out):
    - #5 DFM: pitch 8.5/8.8 -> 9.5mm so the inter-key wall is ~1.5mm (printable in PETG;
    0.5mm was not). Matches the i8+ pitch. Grips -> 74.5x109.5mm, 79 keys.
    - #4: drop MENU keys, shift bottom row, add a double-wide 2u space bar per side
    (dome stays single under the wide keycap; keys carry a 'w' width in units).
    - #2: D-pad no longer overlaps the F-row (upper zone sized to clear the cluster,
    clusters centred instead of offset down).
    - #1: bottom-inner mount hole moved below the vertical JST-GH bridge connector.
    - #3: keymat now ties every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
    [thumbdeck_left.kicad_pcb, thumbdeck_left_placement.csv, thumbdeck_right.kicad_pcb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]
2026-07-10 Autonomous route+validate loop working (KiCad 9 + Freerouting)
    - Upgraded toolchain: KiCad 9 (drc/render CLI + Specctra API), Freerouting 2.2.4
    (Java 25). gen_board.py places real footprints (Snaptron dome, marbastlib E73,
    stock USB-C/SOT-23/SOD-323/0402) + full netlist; route.sh runs the loop:
    DSN export -> Freerouting autoroute -> SES import -> DRC(json) -> 2D+3D render.
    - Solved the headless blockers: Specctra export chokes on the custom dome pad and
    the MountingHole footprint -> use simple circular dome pads + Edge.Cuts holes.
    - First autoroute of the right grip: 780 tracks + 100 vias; DRC 34 violations /
    44 unconnected (iterating to clean). E73 pin-map + wiring in docs/routing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
    [thumbdeck_left.kicad_pcb, thumbdeck_right.kicad_pcb]
2026-07-10 v0.14: verified-correct 4-layer board, real firmware, 3D shells/keymats + fit-check
    PCB / electrical (audited vs datasheets + adversarial multi-lens review):
    - FIX blocker: USBLC6-2SC6 ESD shorted USB D+ to D- (pin6 == pin1 node). Rewire
    D+=pins1&6, D-=pins3&4 per ST datasheet.
    - Verified E73 pinmap 1:1 vs the official Ebyte datasheet (the "silent killer" is clean).
    - Charger R24 2k->5k1 (~505mA -> ~196mA, ~0.5C of a 400mAh cell).
    - Fix left-grip bridge header on wrong edge; rotate left-grip switch pads (ring-pad
    direction) so they clear the inner connector.
    - Single-sided back assembly: move all reflow parts to B.Cu; connectors J2/J3 to back
    so they clear the top shell + keymat.
    - Mov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
    [bottom_shell.step, bottom_shell.stl, keymat_left.stl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]
2026-07-11 rev-A (v0.15): production-ready boards, fab package, firmware, shells
    Full top-to-bottom redesign pass driven by an 8-dimension adversarial audit
    (120 findings, 14 blockers) and closed by a 6-agent verification review.
    Boards (both DRC 0 violations / 0 unconnected, kicad-cli 9.0.9):
    - Production snap-dome footprint: centre pad + 292° leg ring with 67.5° escape
    gap, mask apertures, pour + all-layer via keep-outs (old 2-pad proxy gave
    dead keys at 45° dome rotation)
    - E73 rotated antenna-down at the bottom edge; keep-out verified copper-free
    - Bridge: 16P 1.0mm FFC ZIF (AFA07-S16FCC-00) per grip + straight type-A
    jumper; left-grip nets assigned by ribbon geometry (proven 1:1)
    - Batte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
    [thumbdeck_left.kicad_pcb, thumbdeck_left_placement.csv, thumbdeck_right.kicad_pcb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]
2026-07-14 added everything
    [bottom_shell.step, bottom_shell.stl, keymat_left.stl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]
2026-07-14 v0.17: Rii-proportioned grips — chin cut, electronics to top, rectangular keys
    Print-in-hand feedback on the right grip lid: the device towered over both the
    phone (~80mm) and the Rii i8+ (~97mm) the layout mimics, with the excess in the
    chin below the space row. This rev takes the grip 114.5 -> 97.0mm to match the
    i8+, verified end-to-end.
    PCB / 2D (both boards re-routed, 0 DRC violations / 0 unconnected):
    - bottom_strip 19 -> 7: chin under the space row ~23 -> ~9mm
    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
    [back_left.stl, back_right.stl, center_panel.stl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]
2026-07-14 v0.18: flush-screen phone well, battery to left grip, full nested assembly GLB
    The cased S25 Ultra's SCREEN is now FLUSH with the grip lids' keyboard face:
    one continuous 14.3mm front plane (lids / panel border / glass), device
    15.3mm thick overall (was 22.9 with the phone proud). Boards untouched — no
    reroute, same 0/0 DRC, same fab package, byte-identical firmware.
    Shells (deck3d, --check = 203 bodies / 0 collisions, all parts bed-fit):
    - center panel is now a SUNKEN TRAY: border flange flush at 14.3, well floor
    4.7 with the MagSafe recess/0.8 web/0.2-proud ring translated 10.2mm down;
    4 border screws + 4 floor nubs replace the 6-screw plateau (M2 16 -> 14);
    R9 thumb scallop in th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
    [back_left.stl, back_right.stl, center_panel.stl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]
2026-07-15 v0.16-follow: Rii-style 2u Enter, keycap legends, M2 screws in the model
    Layout (per the Rii i8+ reference, minus the crossed-out features we don't
    carry): the right H-row is now H J K L + a DOUBLE-WIDE Enter at the outer
    end — the apostrophe key gives up its spot and SQT moves to FN+;. Key count
    79 -> 78 (right 36 + left 42). deck.py now lays out each side from its OWN
    legend grid (WIDE_KEYS drives 2u caps generically).
    Right board regenerated + rerouted: DRC 0 violations / 0 unconnected; fab
    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
    [back_right.stl, grip_lid_right.stl, keymat_left.stl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]
2026-07-18 fixed keybaord issues
    [back_left.stl, back_right.stl, center_panel.stl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]
2026-07-22 added stuff
    [keymat_right.stl, thumbdeck_right_placement.csv]
2026-07-22 v0.20: mirrored modifiers — Ctrl/Shift/Alt on both grips
    Two right-grip caps relabel (AGR->Alt, corner backslash->Ctrl); both grips
    end in the same stack (Ctrl corner, Shift above, Alt beside Space). FN+[ = |,
    FN+] = \ as direct bindings. Side-aware HID codes (right emits RCTRL/RSHFT/
    RALT). No sticky behaviors — plain holds only. dtsi byte-identical (zero
    matrix/PCB change); keymats re-debossed; sim_matrix 78 keys 0 collisions;
    models/renders/GLB regenerated; v0.20 docs + changelog.
    Also: models/ now tracks the 7 printable STLs (5-part shell split), stale
    layout renders archived to renders/history/, fab package regenerated.
2026-07-23 v0.21: right-grip ThinkPad-style pointing nub — Bean-architecture TMAG5273 hall sensor
    The right top zone mirrors the left cluster: PgUp/PgDn at the mouse-button
    mirror, and a rate-control pointing nub at the exact D-pad mirror (32.3, 79.0).
    Architecture per the Ploopy Bean (CERN-OHL-S v2, credited): a TMAG5273A1 I2C
    hall sensor (C3716049, SOT-23-6, machine-placed SMT on the back) reads a
    O4x2 N52 magnet in a printed flexure spring through the 1.6mm FR4; firmware
    maps deflection to cursor VELOCITY (quadratic curve + deadzone + remainder).
    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
    [back_right.stl, grip_lid_right.stl, keymat_right.stl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]
2026-07-24 v0.22: true-mirror page keys + genuine-TrackPoint-cap nub mount
    Two feedback items on the v0.21 print:
    - PGUP/PGDN move to the TRUE mouse-button mirror x=57.25 (the F10|DEL gap,
    mirroring the left pair's ESC|F1 gap; was 45.7, "above F9"). v0.21's
    blocker was a face-conflation: domes are front-side, the E73 is back-side —
    they coexist. Both feature diodes drop to deck y73.2 under the TP row
    (defaults hit the module belly / the SWD row), SW91 moves to the vacated
    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
    [back_right.stl, grip_lid_right.stl, keymat_right.stl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]
2026-07-24 site: render-on-demand viewer, right-shifted framing + Pages deploy workflow
    Viewer performance: switch to render-on-demand (only draw when the camera
    moves or state changes), replace the per-frame 555k-tri occlusion raycast with
    a near-free back-hemisphere test, and cache hotspot anchor positions so bounding
    boxes recompute only on explode/model change. Idle frames now cost nothing.
    Framing: push the model into the empty space right of the hero copy via a
    camera frustum offset (setViewOffset), scaled to viewport and disabled on
    stacked/mobile layouts; keeps the orbit pivot centred so it stays put while
    spinning and pins still track.
    Also hardens build-content.mjs to fail on an unresolved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
2026-07-24 site: fix PCB layer z-fighting (keep board layers, depth-bias them)
    The web export was merging the four coplanar KiCad board layers (FR4 body,
    copper, soldermask, silkscreen) into one mesh, so their surfaces fought for the
    depth buffer and flickered. Keep each layer as its own mesh again
    (pcb_*__body/__copper/__soldermask/__silkscreen, components merged separately)
    and apply polygonOffset in the viewer so they stack in physical order — body
    behind, copper, mask over copper, silk on top — instead of z-fighting. All
    traces/pads preserved; no geometry change.
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2026-07-24 site: procedural social card rendered from the live viewer + proper OG tags
    Add scripts/render-thumbnail.mjs: headless Vite + Playwright/Chromium loads the
    site in a new ?shot mode (dark, centred, static, no pins) and screenshots the
    canvas to public/renders/og-card.png (2400x1260) — so the social image always
    matches the current model. Wired into `npm run models` so it regenerates on
    every model update. Viewer gains framingOffset/frameMargin/onFullLoaded hooks.
    index.html: real Open Graph + Twitter card with ABSOLUTE image/URL (relative
    ones don't resolve for scrapers), image dims, alt text, and better copy.
    CI never renders the thumbnail (the PNG is committed), so set
    PLAYWRIGHT_SKIP_B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
2026-07-24 site: replace phone lockscreen with a generated minimal writing-app screen
    The S25U model shipped a portrait Pixel lockscreen, which read sideways once the
    phone is mounted landscape. Generate a minimal landscape writing-app screenshot
    (iA-Writer style) with Gemini 2.5 Flash Image via hardware/cad/gen_screen.py,
    rotate it into the phone's 1080x2400 portrait texture space, and bake it onto the
    phone "display" material at model-build time in optimize-models.mjs — swapping
    BOTH the base-colour and emissive channels so the old lockscreen stops glowing
    through. Screen now reads upright and landscape; the og-card reflects it too.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
2026-07-25 site: drop the designed-not-built framing entirely
    It's a hobby hardware project page linking to its own GitHub repo — it doesn't
    need a disclosure. Replace the "Where it stands" status section with a plain
    "Build one" CTA (open hardware, how to make one, PRs welcome), drop the antenna
    "you only find out by building one" aside, relabel the lede link, and clear the
    footer line. No more not-built language anywhere in the visible copy.
2026-07-26 v0.23: faceted ergonomic back crown (Rii-8+ swells, 90s hard-industrial)
    The dead-flat back becomes a faceted palm crown. Two cut-corner grip
    plateaus (-5.5mm below the z=0 back plane, apex biased to each grip's outer
    edge, three scored shadow-line grip grooves each) rise from a lower faceted
    spine panel (-2.2mm) so the whole back reads as one milled Sega/Nokia-style
    block, tapering to a thin land at the perimeter. Built with CadQuery ruled
    lofts of cut-corner sections (planar-facet B-rep) in deck3d._crown_solid /
    _grip_mound / _spine_ridge / _crown_grooves.
    The crown is purely additive BELOW z=0, so the validated electronics cavity
    (z>=FLOOR), the 221-body collision result (still 0 clashes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
    [back_left.stl, back_right.stl, nub_spring.stl]
2026-07-27 v0.24: expanding spring-clamp back (Kishi 2 / Backbone style)
    Replace the rigid center — the bolted center panel + sunken flush-screen well +
    MagSafe ring — with a telescoping spring clamp that clasps different-size phones
    (cased long edge 130-170mm), per the user's Kishi-2/Backbone request.
    deck.py: product() is now parametric on clamp_pos. The RIGHT grip is fixed ground
    (inner edge pinned at the nominal half-gap); the LEFT grip is a moving jaw whose
    origin tracks the clamped span. Config gains phone_span_min/max; magsafe dropped.
    deck3d.py: deleted center_panel, magsafe_ring, the well/slab/ring/panel constants,
    the x=0 seam joinery, the spine slab (full_footprint is grips-only) and t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
    [back_left.stl, back_right.stl, bridge.stl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]
2026-07-27 v0.24: enclose the clamp mechanism (telescoping shrouds) + add the power cable
    Feedback: the springs, FFC, and the (missing) battery power cable must be enclosed
    at all times, regardless of clamp extension.
    Enclosure: the open dual-rail bridge becomes two NESTED TELESCOPING SHROUDS
    (Backbone style). The bridge part is now the fixed OUTER shroud — a closed box
    (recess-floor top, bottom cover, y-walls, right end wall) open only on its left end,
    bolted to the right grip — that houses the 2 extension springs and the cable runs.
    back_left grows the moving INNER shroud that telescopes inside it (open right end,
    carries the cables + the spring hook). They always overlap (_shroud_overlap assert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
    [back_left.stl, bridge.stl, nub_spring.stl]
2026-07-27 v0.24: three-stage GEARED telescoping brace (Kishi rack-and-pinion)
    Feedback: match the Kishi's geared telescope — a left/right/centre brace where the
    centre is hidden within the outer stages until pulled apart, geared so pulling one
    side extends the other equally. Emphasis on a sturdy, printable/mouldable result.
    Replaces the two-stage nested shroud with a THREE-stage geared brace:
    - bridge = the CENTRE stage: a sturdy rounded-back bar (flat phone-side top, rounded/
    beveled back for bending+torsion stiffness via _rbar) with a mid-y gear/rack slot +
    pinion axle. It telescopes into a channel on each grip; built at x=0 and placed at
    _center_x() (the phone midpoint) in assemble.
    - pini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
    [back_left.stl, back_right.stl, bridge.stl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]
2026-07-28 v0.24c: 2-part telescoping tray + TPU grippers + MagSafe back
    Simplify the geared 3-stage brace (fbf79a9, kept in history) down to a
    2-part telescoping tray, the Abxylute-S9 / 8BitDo approach: our clamp
    travel is only ~40 mm (130-170 mm phones, ~1.3:1), so a rack-and-pinion
    solved a large-travel problem we don't have. The fixed `bridge` shroud
    bolts to the right grip and the left grip's plate laps inside it,
    enclosing the springs, FFC and power cable at every extension.
    Retention is now MECHANICAL, so the phone is safe used screen-down over
    your face (Switch/Steam-Deck style), never depending on magnets:
    - gripper_left/right: soft TPU 95A edge pads that protrude into the well
    (the phone c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
    [back_left.stl, back_right.stl, bridge.stl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]
2026-07-28 v0.24c: add cable-enclosure assertion to --check
    collide() only tests interpenetration, so an exposed FFC/power cable in
    the inter-grip gap passed silently — the enclosure was only ever
    eyeballed in a (translucent) render. Add cable_enclosure(): ray-cast
    each cable outward in ±z (top/bottom) and ±y (front/back walls) across
    the tray-bridged gap at every span and assert a shell blocks every ray.
    Connector ends (inside each grip) are excluded. --check now prints
    "cable enclosure SEALED/EXPOSED" per state and fails on any exposure.
    Verified SEALED at min/nominal/max (the geometry was already enclosed;
    what reads as "outside" in the web viewer is the cables seen THROUGH the
    translucent Atom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
2026-07-29 push it baby
    [back_left.stl, bridge.stl, gripper_left.stl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]
2026-07-30 better grippies and extension
    [back_left.stl, back_right.stl, bridge.stl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]
2026-08-02 dpad fixed
    [grip_lid_left.stl, keymat_left.stl, nub_spring.stl]
2026-08-02 merged pieces re-optimized
    [back_left.stl, back_right.stl, bridge.stl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]
2026-08-05 added substack forms
    [back_left.stl, back_right.stl, nub_spring.stl]
2026-08-07 added typing screen
    [back_left.stl, back_right.stl, grip_lid_left.stl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]

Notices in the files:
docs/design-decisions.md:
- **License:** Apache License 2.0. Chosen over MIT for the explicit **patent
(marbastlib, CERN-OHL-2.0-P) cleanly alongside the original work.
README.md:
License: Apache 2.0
